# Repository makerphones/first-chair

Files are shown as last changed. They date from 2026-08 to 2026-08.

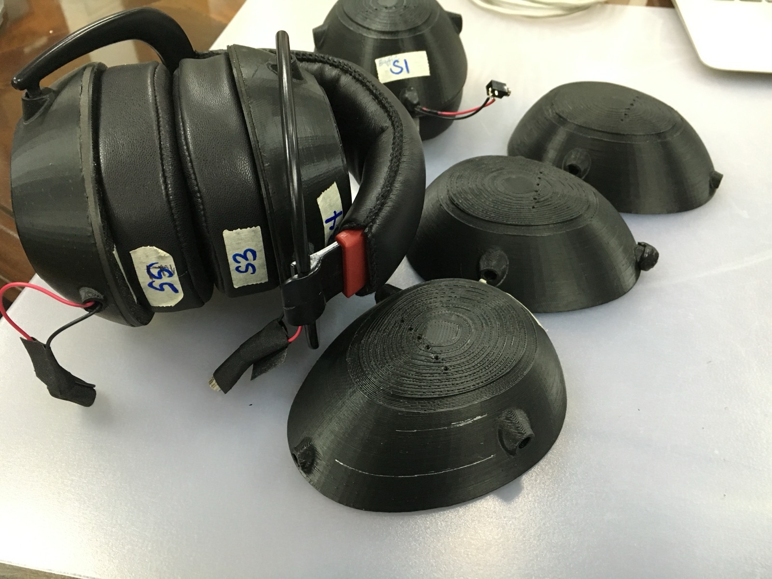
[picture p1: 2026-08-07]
design/form/reference/dev-6398.jpg

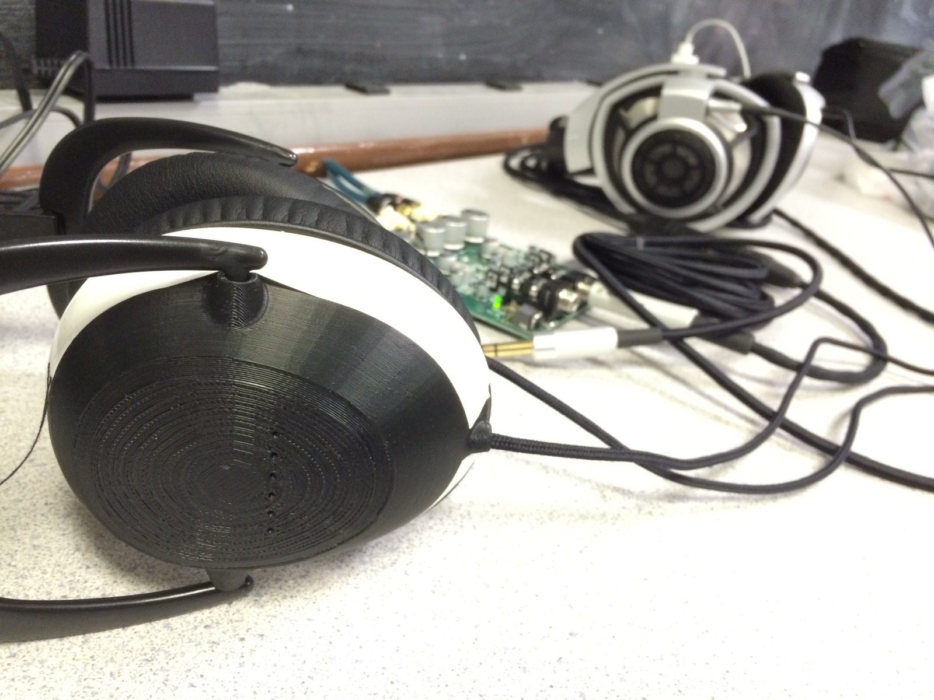
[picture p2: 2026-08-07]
design/form/reference/dev-6343.jpg

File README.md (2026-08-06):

# First Chair

An open-source **40 mm open-back headphone** you can build yourself, modify, and
make your own. Parametric CAD — change a driver, a pad, or a head size and the
model follows. A project of [MakerPhones](https://makerphones.com) / Warren Labs.

> **🧊 Spin it in 3D** — inspect the assembly in your browser before you build:
> **[live 3D preview →](https://makerphones.github.io/first-chair/)**

> **Status: early / in active development.** The cup and baffle are first-pass
> geometry; the headband parts (yoke, slider) are stubs. Nothing has been
> print-verified yet. Follow along — and fork freely.

Honest sonic target: a bright, open, detailed open-back — strong mids and
treble, modest bass. That's the nature of a small driver in an open baffle, and
the design leans into it rather than chasing bass the hardware can't make.

## How it's made

The parts are defined in code with [CadQuery](https://cadquery.readthedocs.io)
(Python). That means the whole design is plain text you can read, diff, and
modify — and it exports both **STL** (ready to print) and **STEP** (to edit in
other CAD).

### Build the parts

```bash
python -m venv .venv && source .venv/bin/activate
pip install -r requirements.txt
python build.py                 # all parts → output/
python build.py baffle          # just one
```

STLs and STEPs land in `output/`.

For the live VS Code [OCP CAD Viewer](https://github.com/bernhard-42/vscode-ocp-cad-viewer)
(`python show.py`), also install the viewer-only deps and point VS Code's Python
interpreter at this `.venv`:

```bash
pip install -r requirements-dev.txt
```

### Modify it

Open `params.py` — every dimension lives there with a comment. Common changes:

- **Different driver?** Measure it with calipers, update `driver_od` and
  `driver_aperture`, rebuild the baffle.
- **Different pad?** Adjust `pad_lip_od` to your pad's inner-ring diameter.
- **Bigger/smaller head?** Adjust the cup and headband parameters.

The build log in [`docs/DESIGN-LOG.md`](docs/DESIGN-LOG.md) explains the
reasoning behind the design and tracks the open questions. The full functional
spec is in [`docs/design-spec.md`](docs/design-spec.md).

## Bill of materials (build-it-yourself)

| Component | Source | Est. cost |
|---|---|---|
| 2× 40 mm driver, 32 Ω | Parts Express / Madisound | $8–18 |
| 1× Dekoni Universal 100 mm pads (Beyer-type) | Dekoni Audio | $30–45 |
| 1× spring steel arc (laser-cut, formed) | SendCutSend + form | $8–15 |
| 8× M3 heat-set inserts | hardware / online | $1 |
| 8× M3×8 mm button-head screws | hardware / online | $1 |
| Foam gasket tape | hardware | $1 |
| Damping pack (foam + felt + fiberfill) | Parts Express | $3–5 |
| Cable + Y-split + 3.5 mm TRS plug | online | $8–15 |
| Printed parts | own printer or print service | $3–25 |
| **Approx. total** | | **~$55–105** |

No printer? FDM print services (JLCPCB, Xometry) will print the set cheaply.

## License

**This project is open source under the [MIT License](LICENSE).** You are free
to use, modify, build, and **sell** the First Chair — commercially or
otherwise. No "personal use only" restriction, no fee. One license over the
whole repo, code and docs alike; full text in [`LICENSE`](LICENSE).

**Attribution requested:** when you share or build on it, credit *makerphones by
Warren Labs (makerphones.com)*.

The **makerphones** and **Warren Labs** names and brands are *not* covered by
the license and are protected separately by trademark — it covers the design
and code, not the names.

## Contributing

This is a learning-in-public project. Builds, measurements, and fixes are
welcome — open an issue with what you tried and what happened.

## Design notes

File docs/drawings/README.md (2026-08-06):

# Daily Driver — drawings

Schematic 2D part sheets (SVG) for the Daily Driver, in the DT880-family
direction (see `../design-spec.md`). These are **Resolve-phase schematics** — not
CAD projections. They capture intent, key joints, and first-pass dimensions so
the spec and the eventual `parts/*.py` geometry agree on what each part *is*.

| Sheet | Part | Referenced from spec section |
|---|---|---|
| `assembly.svg` | Exploded stack + the 3 joints | System architecture / BOM |
| `cup.svg` | Cup shell + integral grille | Cup shell |
| `baffle.svg` | Front-mount baffle | Baffle plate |
| `yoke.svg` | DT880-style fork-yoke | Fork-yoke |
| `slider.svg` | Bow slider (height + swivel)| Slider |
| `bow.svg` | Spring-steel head bow | Headband / bow |

**Every dimension on these sheets is a first-pass starting value pending measured
parts** — the bow especially is TBD from the real Beyer Metal Head Bow. Sheets
are schematic, dimensions are not to scale.

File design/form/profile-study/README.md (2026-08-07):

# Cup profile study

Six directions, generated by `design/form/profiles.py`, rendered from one camera so the
silhouettes compare honestly. **Silhouette only** — no grille, no bosses, no lip chamfer.
This answers *what shape is it*, not *what parts is it*.

Held fixed, because the commodity Grado pad sets them from outside:
**Ø54 rim · 3.0 lip · Ø48 body · 3.0 wall.** Depth and the whole rear form are free.

| | depth | PETG | note |
|---|---|---|---|
| `cylinder` | 27.6 | ~13.1 g | the baseline. Austere, and the wall you print is the wall you specified |
| `cone` | 27.6 | ~18.5 g | prints nose-down self-supporting; mass falls away from the ear |
| `waist` | 27.6 | ~12.5 g | the move in the 2016 shape sketches, read in section |
| `stepped` | 25.0 | ~9.2 g | concentric plates — every diameter change is a future parting line |
| `shallow` | 21.6 | ~11.0 g | Old Faithful's earcup measured 21.6 deep; this is that read |
| `bell` | 26.0 | ~7.6 g | one continuous curve from the lip to a small back face |

Mass assumes PETG 1.27 g/cm³ at ~55 % effective solid (30 % gyroid + perimeters).

## Working with it

```bash
.venv/bin/python design/form/profiles.py            # all six
.venv/bin/python design/form/profiles.py cone waist # just these
```

Add or change a direction by editing `PROFILES` — each is a list of `(radius, depth)`
points running outward from the axis at the rim, around the outside, back to the axis.

**No handoff.** These are real CadQuery solids in the repo's own toolchain, so a chosen
profile goes straight into `parts/cup.py` as the lathe profile it already is.

## Known limitation

`cone` falls back to a straight Ø26.3 bore — OCC refuses the profiled inner loft on that
one ("Courbes non jointives"), so its wall is thicker than 3.0 at the back and its mass
is overstated. The silhouette is correct; the number isn't. Same class of OCC fragility
recorded in `docs/cadquery-build-notes.md`.

---

# Split study — where does the part break?

`design/form/splits.py`. Two cases, assembled and exploded, in `_contact-splits.png`.

**The architecture being tested:**

| | |
|---|---|
| **FRONT** | pad rim + baffle + driver seat, **one printed part**. The driver is registered concentric to the pad by *geometry* rather than by assembly — no bolt circle, no four insert positions to align. |
| **REAR** | the acoustic variable: open area, volume, damping. The part a builder iterates and swaps — which makes open-vs-closed a **part**, not a parameter. We already learned that lesson the expensive way. |
| **DRIVER** | loads from the rear, seats against the back of the front piece. |

Both halves print open-side-down, no supports. That is *why* the split goes here.

| case | split | front | rear |
|---|---|---|---|
| `shallow` | 11.0 of 21.6 | 4.3 g | 6.7 g |
| `waist_split` | 15.5 of 27.0 — **at the pinch** | 9.0 g | 7.3 g |

`waist_split` is a *true* waist. The original `waist` only swells then tapers; this one
pinches to Ø42.8 at d=15.5 and flares again behind it, so **the parting line has somewhere
to hide.** A seam at the narrowest point reads as intent; the same seam on a straight wall
reads as a seam.

## On joining the two

- **Screw thread** — no fasteners, serviceable. But a thread **cannot control where it
  stops**, so anything directional on the rear cup (mark, cable exit, an oriented grille)
  lands at a random angle. Only viable if the rear is rotationally indifferent.
- **Bayonet, quarter-turn** — no fasteners *and* a defined angular stop. Strongest option.
- **Screws** — positive and serviceable, but reintroduces bosses, inserts and hardware, and
  works against the *"only parts not printed are ___"* sentence.
- **Glue** — kills serviceability. Against the standing tie-breaker: the user is a tweaker.

---

# Straight front + tapering back

Maker on `waist_split`: *"it looks like a yoyo."* Correct, and not a rendering error — that
profile swells, pinches, then **flares back out**. Wide-narrow-wide is a yoyo.

The read was *"the base of the one on the left, with the back of the other one but flipped"*:
straight front, then mass falling **away** from the head instead of bulging back out.
`_contact-taper.png`, three rates:

| | straight to | back face | depth | PETG |
|---|---|---|---|---|
| `taper_soft` | 13.0 | Ø35 | 25.0 | 10.3 g |
| `taper_mid` | 12.0 | Ø29 | 24.0 | 9.1 g |
| `taper_hard` | 11.0 | Ø22 | 22.5 | 7.8 g |

The straight section is also the split zone — which is the point. Parting on a cylinder
means both mating faces are the same diameter, so the joint is a simple round fit rather
than something that has to follow a curve.

## The parting line: shadow gap, not chamfer

A chamfer at the joint is a bad print — on whichever part has it facing down it is a
first-layer overhang. A **shadow gap** is a pure diameter step: the rear cup steps down
0.6–1.2 mm for ~2 mm above the joint. Zero overhang on both parts, prints trivially, and it
does three jobs at once:

1. reads as intentional rather than as a seam
2. **hides tolerance mismatch** — a flush joint shows every 0.1 mm of print variation, a
   recessed one shows none
3. gives a fingernail purchase for opening it

0.6 mm is a line. 1.2 mm is a feature. Both print; the choice is taste.

## On the bayonet — quarter turn is probably enough, and here is the alternative

A bayonet's retention is the **lug ramp and detent**, not the rotation angle. Three lugs at
120° need only ~60–90° to engage, and load is shared three ways.

If it still feels insufficient, the better answer is a **3-start coarse thread**: ~120° of
rotation, more screw-like in the hand, and it still solves the orientation problem — it
lands in one of **three** defined angular positions rather than anywhere at all. That is the
real objection to a single-start thread, which stops wherever friction says.

---

# Section — does the front piece hold the driver?

`design/form/section.py` → `_section.png`. **Yes, comfortably, for a dynamic.**

```
ear ──5.5── cup face ──3.5── driver flange ──5.0── driver back ──3.5/4.5── split
            (worn pad)        (dome+excursion 2.0 forward of the flange)
```

| | split | front cavity | behind the driver |
|---|---|---|---|
| `taper_soft` | 13.0 | 7.0 mm | **4.5 mm** |
| `taper_mid` | 12.0 | 7.0 mm | **3.5 mm** |

**Front cavity 7.0 mm** — the gap from the excursing dome to the ear. That is the number
that sets tonality, and it is mostly the pad: change flats for bowls and it moves several mm.

The driver flange sits **3.5 mm** back from the cup face. That is a *design* choice, not a
constraint — pushing it back trades front cavity for tail room 1:1.

## Where the planar breaks it

Maker: *planars are thicker, with a nipple on the front, so they need more space and a
different mounting ring.* That is exactly what the budget shows.

A dynamic spends **2.0 mm forward** of the flange and **5.0 mm behind**. Push either and the
front piece has to grow, because the split can only move back so far before the rear cup
stops being the acoustic part:

```
front piece depth needed ≈ DRV_SEAT + basket + 3 mm of mounting structure
```

At a plausible planar — say 9 mm body with a 3 mm front nipple — the seat has to move back
to 4.5+ and the basket needs 9, so the split lands near **17 mm**. The current 12–13 does not
hold it.

**Those planar numbers are invented.** What is needed is one caliper session on a real
planar: body depth, front protrusion, flange OD, mounting hole pattern. Then this drawing
answers it properly instead of plausibly. Adjust `DRV_*` at the top of `section.py` and re-run.

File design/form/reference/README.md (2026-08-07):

# Reference — prior work, for the form pass

**These are the maker's own prior professional headphone designs**, from the HeadRoom Cosmic
programme (planar-magnetic over-ear, taken to production prototype and independently measured
by InnerFidelity) and the shape studies that preceded it. They are here so a design session can
be seeded from *what was actually built* instead of from adjectives describing it.

Captions matter as much as the pixels — read them.

## The shape studies

| File | What it is |
|---|---|
| `shape-sketches-overview.jpg` | **Six cup-outline studies in one row.** Teardrop, oval, rounded-square, faceted, egg, round. Note what does *not* change between them: the waisted, flared yoke stem and how it lands on the cup. That constant is the family language; the outline was the variable. |
| `shape-sketch-1a … 6a.jpg` | The same six, individually. |

`shape-sketches-overview.jpg` is the single most useful image here. It is a decade-old answer to
the question the current pass is asking — and it shows the answer was never one outline.

## The headband blanks

`bow-blanks-cut-and-formed.jpg` — laser-cut blue-tempered spring steel. Flat blanks at left,
formed arcs at right.

Read the cut: a tapered strip that **splits into a Y-fork** toward the ear end, with the slots
**terminated in teardrops** so a cut cannot start a crack, and a mounting hole at each tip.
Material follows the bending moment — wide where the load is, split and slender where it is not.
This is "shape the silhouette, don't thin the slab," executed in steel years before it was
written down as a rule.

**What worked and what didn't:** the *cutting* is resolved. The *forming* failed — the arc came
out wrong and the spring rate too low, using printed forming jigs. That is why the current build
buys a bow. It is also why "make our own" is a sourcing conversation with a spring house rather
than a design problem: the part is already drawn.

## Prototypes

| File | What it is |
|---|---|
| `prototype-1.jpg` | Prototype 1 (left) benchmarked against an Audeze LCD, a MrSpeakers/Dan Clark, and a Fostex. Useful for scale and for the company it was designed to keep. |
| `driver-70mm-planar.jpg` | The 70 mm planar diaphragm — spiral conductor trace, with a polygon of tape strips laid across it. That tape is **damping applied by placement**, the same lever as acoustic paper on a baffle. |
| `dev-*.jpg` | Development photographs: printed cup and baffle series, pad trials, assembly. |
| `earcup-07revB.stl` | An actual printed earcup from the programme. Measures **80.00 × 100.06 × 21.59 mm** — matching the design letter's "fits in about 100 mm x 80 mm." Oval, not round. |

## The intent, written at the time

From the design letter to the industrial designer on that product:

> "The code name Old Faithful is chosen to represent something that lasts a lifetime and will be
> passed down for generations. It should exude quality craftsmanship, **almost looking handmade
> but with extreme precision**. Parts should be easily replaceable and durable. Reduce weight
> where ever possible."

## The rules, taken from corrections given to that designer

1. **If a mechanism isn't needed, delete it.** A fold hinge was killed with *"an extra weakness
   we do not need."* Not "unnecessary" — a **weakness**.
2. **No ornament.** On a decorative step added where the pad met the cup: *"I am assuming this is
   for aesthetic reasons? I do not have to have this."*
3. **Simplify until it's simple, then stop before it's ugly.** *"There seems to be too much going
   on with the headband mechanism right now, we'd like to simplify"* — and *"we're looking to
   simplify without looking ugly. Hopefully we can find a nice middle ground."* Both halves.
4. **Material follows load.** On a yoke: *"if we don't need the extra metal we can save weight —
   but it does look nice and beefy."*
5. **The prototype settles arguments, not the drawing.** Hinge pins moved 8 mm because a built
   part said so.

## Provenance

Everything in this folder is the maker's own photography of his own prototypes, his own shape
sketches, and his own printed part.

**Deliberately excluded:** commissioned industrial-design renders and CAD from Deep Blue Design
and Martin Ortiz (ownership likely but unconfirmed), third-party product photography from the
original mood-board collection, and anything touched by a supplier NDA. This repo is public and
MIT-licensed; none of that can live here.

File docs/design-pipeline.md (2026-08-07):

# AI-Assisted Design Pipeline

**v0.3 · 2026-08-06 · Claude Design replaces the FAL image pipeline**

This describes how AI assists the design of a MakerPhones build and, just as importantly,
**where it stops**. The pipeline produces *form* and *figures*. It never produces engineered
CAD. The headphone you can actually build is authored by hand in CadQuery, from human
decisions.

This file is not First-Chair-specific. First Chair is the fork template for every build
after it (`starting-a-new-product.md`), so what is written here is the standing process.

**Capability map: `warren-labs/docs/claude-design.md`** (internal — deliberately not linked,
since this repo is public and that one is not). That file is the source of truth for what the
tool can and cannot do — verified by direct probe on 2026-08-06, not from marketing copy —
and it applies line-wide, beyond MakerPhones. It is not restated here; the one conclusion
that changes how you work is repeated below, and nothing else.

What follows is the MakerPhones-specific part: where it sits in *this* process, what we hand
it, what we demand back, and what we do with the result.

---

## The one thing to internalise

**It has no boolean operations.** No CSG means a hole in an arbitrary place on a curved wall
is impossible, which means **nothing printable can originate there** — and that settles the
handoff with no per-part judgement. Form and figures upstream, engineering in CadQuery. It
described its own output as *"industrial-design intent, not a print-ready CAD part"*, which
is the same boundary we draw from the other side. Both parties agreeing on that unprompted
is the reason it is safe to adopt.

The corollary is the useful part: **it is valuable at the two ENDS of a project and useless
in the middle.** Before CAD exists, nothing is lost to a tool that can't do booleans, because
there is no engineering yet. After CAD exists, it is the best documentation-figure tool we
have. While CAD exists, it can only get in the way.

---

## Workflow: Diverge → Resolve → Engineer

Three phases, each with its own surface and its own job. The discipline is not doing one
phase's work on another's surface.

```
DIVERGE                          RESOLVE                          ENGINEER
find the form + family           develop it into a buildable      author the geometry
Claude Design (3D)               design — chat + SVG sketches     Claude Code + CadQuery
named, scaled GLB                parts, fit, fasteners,           params.py + parts/*.py
       │                         acoustics, wall, weight          build · gate · log · commit
       │                                  │                                │
  GLB + part list ────────────> resolved design intent ──CC prompt──> verified parts
       └──────── inspect_glb.py, then read into chat ────┘

                                                    ┌─────────────────────────────┐
DOCUMENT (after Engineer)                           │ CadQuery/OCP renders ───────┼──> Claude Design
compose, annotate, typeset the figures              │ (our geometry, our fidelity)│    composes the plate
                                                    └─────────────────────────────┘
```

### 1 · DIVERGE — find the form, before any CAD exists

Run the family/form pass in Claude Design, seeded with the repo and the naming schema (see
Conventions). Ask for **the rules in words before it models anything** — proportion and rule,
not a repeated detail; something that still works at 54 mm and at 91 mm. Then let it model.

**FORM BEFORE PARTS. This order is not optional and we got it backwards first time.**

```
1. one continuous form, no parts at all      ← judge it as an OBJECT
2. split that form into parts                ← serviceability + printability enter here
3. details: grille, mark, fasteners, joints
4. ENGINEER — re-author by hand in CadQuery
```

Asking for parts in step 1 produces exactly what it sounds like: primitives butted together,
every junction an abutment, nothing flowing into anything. That reads as clunky no matter how
good the proportions are, and no amount of "make it more elegant" fixes it, because the
*construction method* is the problem.

**It also plays to the tool.** No booleans means it cannot cut features into a body — so
assembling primitives is the only way it can fake parts, and it is its weakest mode. A single
lofted or swept body is its strongest. Ask for the thing it is good at.

And the payoff at step 2: **if the form is defined as a profile, splitting it into parts is a
split of the profile, not a boolean.** The whole path stays inside the tool's ceiling instead
of hitting it one step later.

This is also how the maker's own prior product was done — the industrial-design firm delivered
*surfacing* (one form), and the part split came afterwards, from the maker, once the shape was
agreed.

Output: **a named, hierarchical, correctly-scaled GLB** — not a picture. That is the whole
reason this replaced what came before. Run `makerphones/scripts/inspect_glb.py` on it (it is
in the parent repo, not this one), read the part list, and
carry the numbers into the discussion.

**Two things to push back on, every time.** It will try to make a "family" by repeating a
detail — that is the weak version. And it drifts toward glossy injection-moulded consumer
product, because that is what the training data is full of; anything printed, machined or
hand-built has to be asked for explicitly and defended on the second pass.

### 2 · RESOLVE — develop the chosen direction into a buildable design

With the direction picked, work the design conversationally in chat: the parts, how they fit
and fasten, then the engineering-taste calls — connector choice, acoustic treatment, wall
thickness, weight, and the design language carried across parts. Claude sketches schematic 2D
concepts (SVG) and reasons through structure, constraints, acoustics and printability.

**This is where the acoustic and mechanical decisions are made, not just the visual ones** —
chat is the only one of the three surfaces that can *reason*, so the judgment calls live here.
Output: a resolved design intent, ready to engineer.

### 3 · ENGINEER — author the geometry

In Claude Code: author the parametric CadQuery geometry (`params.py` + `parts/*.py`), then
build, gate, log, commit. The CC loop is for engineering and verification — **not** for
iterating taste one tweak at a time; that belongs in Resolve.

### 4 · DOCUMENT — the strongest mode, and the workflow it proposed itself

**Do not have it re-model geometry at lower fidelity to draw a picture of something we
already hold as real CAD.** Export views from CadQuery/OCP, hand it the renders, and let it
compose, annotate, sequence and typeset: exploded assemblies, print-orientation plates with
overhang callouts, numbered step figures, hardware tables. For schematic figures that need no
dimensional truth (exploded order, orientation, fastener callouts) it can build them directly.

For a documentation-led product this is plausibly worth more than anything it does for the
CAD, since the CAD is already solved and illustration is a cost you pay forever.

---

## Conventions — set these in every prompt

**Two of these fail silently. That is why they are a checklist and not advice.**

- **Author at 1 unit = 1 mm.** Matches CadQuery and every slicer. glTF's spec convention is
  **metres**, so a model that does not say otherwise imports at **1/1000 scale** into a
  slicer — a 54 mm cup arrives as a 0.054 mm speck, or a correctly-authored-in-metres file
  arrives 1000× too big. Nothing errors. `makerphones/scripts/inspect_glb.py` warns on **both** failure
  directions; run it on anything that arrives, without exception.
- **GLB only, never OBJ.** OBJ has no scene graph — it carries groups, not parent/child nodes
  — so it *structurally cannot* express the `SUBASSEMBLIES` hierarchy that makes the output
  worth having. An OBJ silently degrades the one property we are asking for.
- **Impose the mesh-naming schema.** Give it `assembly.py`'s `SUBASSEMBLIES` contract up
  front. It conforms exactly — verified against a test part whose names (`cup_R`,
  `cup_shell_R`, `boss_m3_1..4_R`) landed against the contract unchanged. When the names
  match, ingest is nearly free; when they don't, someone hand-maps 69 meshes.
- **Seed it, and record the seed.** A project can be seeded from a design system, uploaded
  files, or a GitHub repo. **The reproducible unit is (skill + seed + prompt), not the prompt
  alone** — record all three or the result cannot be reproduced later. A prompt kept without
  its skill and its seed is not a record of anything.
- **Write the prompt self-contained. It cannot see this repo.** Claude Design has no
  filesystem access, so "read `docs/industrial-design-brief.md`" silently yields a session
  working from its own priors — the exact failure the pass exists to fix. State every
  constraint inline and reference no local path. Seeding from the public GitHub repo does give
  it real access, but keep the prompt self-contained anyway: "go and read X" is a weaker
  instruction than stating X, and it fails quietly when the seed doesn't take.

The `claude-design` MCP has **no verb for the 3D agent** — that capability is driven by
chatting in Claude Design itself, so the loop is: prompt there, download the GLB, ingest here.
What the MCP usefully adds is **seeding**: writing our conventions and parameter table into a
project so the session starts inside our constraints instead of inventing its own.

---

## Taste vs. convention — the split that decides what AI touches

This boundary predates Claude Design and survives it unchanged. It is worth being explicit
about why: **Claude Design produces taste, never convention.** It is a form tool. It cannot
author a screw boss you would reuse, and it should never be asked to.

**TASTE is human and manual.** Cup depth, grille form, where the screws go, proportions,
stance, finish. These are judgment calls, decided from references **plus real measurements**
(that deciding is **Resolve**; **Engineer** only encodes the result). Taste is encoded two
ways, both authored by you, in code: some taste is a **number** (cup depth → a value in
`params.py`), and some is **form** (grille pattern, cup profile) authored as parametric
**geometry in `parts/*.py`** and driven by those params. AI may *inform* taste by showing
options; it never *sets* it, never writes a dimension, and never authors a part.

**ESTABLISHED MECHANICAL CONVENTIONS are not reinvented.** A screw boss, a fillet, a standard
thread, a snap fit — solved by decades of practice. They live as **reusable parametric
helpers**, authored once from convention in `parts/features.py`, and **reused** across parts.
Convention is a library, not a creative act.

| | Who/what | Where it lives |
|---|---|---|
| **Taste** | Human decision, informed by form refs + measurement | `params.py` (numbers) + `parts/*.py` (form) |
| **Convention** | Standard practice, authored once | `parts/features.py` (reusable helpers) |
| **Form + family** | Claude Design (3D) | `design/form/<date>/` — GLB + the prompt record |
| **Engineered parts** | Human + CadQuery | `parts/*.py` |
| **Documentation figures** | Claude Design, over **our** renders | `docs/figures/` |

There is a second reason the boundary holds, beyond "no CSG": **engineered features are
decisions, not pixels.** Where the screws go, how deep the cup is, how the baffle seats, the
vent open area — these have consequences for fit, acoustics and print success. They are
reasoned and measured, not inferred from a form study, and no form study knows your driver's
caliper measurements or your printer's tolerance.

---

## Layout

```
docs/industrial-design-brief.md   the form brief that seeds the Diverge pass
docs/design-pipeline.md           this file
design/
  form/<date>/                    Claude Design GLB + the (skill + seed + prompt) record
  figures/                        source renders handed out for documentation plates
scripts/inspect_glb.py            (in the makerphones repo) scale + naming + hierarchy check
parts/features.py                 reusable mechanical primitives (convention)
```

Curated keepers are committed; the exploration history is part of an open design's story.
Record the seed alongside the GLB — a GLB with no `(skill + seed + prompt)` note beside it is
an orphan nobody can regenerate.

---

## What this replaced, and why the old pipeline is gone

The **FAL image pipeline** — Stage 1 text→concept image, Stage 2 image→reference mesh — was
removed from this repo on 2026-08-06 along with `pipeline/` (`config.py`, `gen_concepts.py`,
`gen_reference_mesh.py`, `smoke_test.py`) and the FAL client dependency.

It was a two-stage lossy path whose output was images we did not want to build, and it was
abandoned rather than finished. Claude Design does both stages in one and returns **named,
hierarchical, correctly-scaled geometry instead of a picture**. That is not an incremental
improvement: an image has to be re-interpreted by a human before it can become parameters,
and a named part list reads straight into `params.py`.

**Deleted rather than kept as a documented fallback — that is a decision, recorded here so it
is not mistaken for neglect.** The argument for keeping it was that a fallback costs nothing
to leave in place. It doesn't cost nothing: an abandoned two-stage path sitting in `pipeline/`
with working code, a config file and a smoke test reads as *current* to the next person who
opens the repo, and the fork template propagates it into every future build. A trap that
regenerates itself with each fork is worse than a paragraph of history. The code is in git
history and in the Daily Driver repo if it is ever genuinely wanted.

*(Daily Driver still carries the FAL pipeline and its v0.2 version of this document. It is
paused, not deleted, and reconciling it is deliberately out of scope here.)*

---

*v0.3 · 2026-08-06 · Rewritten around Claude Design; FAL pipeline and `pipeline/` deleted;
conventions promoted to a checklist because two of them fail silently.
v0.2 · 2026-06-14 · Added the Diverge → Resolve → Engineer workflow (Resolve was the missing
layer). v0.1 · 2026-06-13 · Written as the form pass opened.*

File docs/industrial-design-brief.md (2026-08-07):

# First Chair — Industrial Design Brief

**v0.2 · 2026-08-06 · rewritten for the supra-aural, and re-opened**

> **This brief was wrong, and the CAD faithfully built the wrong thing.**
>
> v0.1 was Daily Driver's brief with the product name changed. It specified an
> *"open-back, **over-ear (circumaural)** DIY headphone"*, recorded the resolved direction as
> **"DT880-family, around-ear"**, and named a **Dekoni Universal 100 mm** pad. The fork reset
> about eight dimensions in `params.py` and left this file — the thing the geometry is supposed
> to descend from — untouched.
>
> So the model on the website was a **shrunken DT880**: domed cup, circumaural stance,
> over-ear pads on a Ø54 rim. Dimensionally correct, formally the wrong product. Same failure
> as the Ø91 radii in `params.py` and the DT 770 pads in `BOM.md`, one level further upstream.
>
> The rule that would have caught it is `starting-a-new-product.md` step 1b — run the form pass
> in Claude Design **before** writing `params.py`. This build predates that rule.

**Status: the form is OPEN. This brief states the constraints; it deliberately does not state
the answer.** The Diverge pass (`design-pipeline.md`) produces 3–5 directions and the maker
picks one. Do not read a direction into this file that isn't here.

---

## What it is

An open-back **supra-aural (on-ear)** headphone around a 40 mm driver. 3D-printed, fully
parametric, open source (MIT), meant to be downloaded, forked and modified. It is the
**flagship first build** — the first rung of a learning path, not the last.

Sonic character is bright, open, detailed, with modest bass — the honest nature of a small
driver in an open baffle on an on-ear. The form should feel like that: light, airy, unfussy.

## Who it's for, and how it should read

DIY makers and hobbyist builders. The form should read as **honest engineering — pro-audio
sensibility through a maker lens** — not glossy consumer product. Credibility comes from
looking considered, functional and serviceable, not flashy. If it looks like it was designed by
someone who knows audio and respects the person building it, it's working.

**This one needs defending on every pass.** Generative tools drift hard toward glossy
injection-moulded consumer product, because that is what the training data is full of.
Printed, machined and hand-built has to be asked for explicitly and re-asserted on the second
pass — see `design-pipeline.md`.

---

## LOCKED — the form pass works inside these

These are decided. A direction that breaks one of them is out, however good it looks.

**Architecture — supra-aural, and it must read as one.**
The failure to design away from is a scaled-down over-ear. A supra-aural sits *on* the ear:
small cup, small pad, light band, close to the head. It is a different object, not a small
version of another object.

**Dimensions** (see `params.py`; these regenerate everything):

```
front plate / pad rim   Ø 54.0        the pad-mount interoperability dimension
cup body                Ø 48.0        what the pad grips, behind the lip
interior                Ø 42.0        → 3.0 mm wall
overall depth              27.6
driver                     40 mm
```

**Parts** — sprung steel bow (bought, screwed at its end tabs) → printed slider → printed yoke
→ printed cup + separate baffle + clamp ring. **Three degrees of freedom**: swivel and tilt at
the cup, plus slider travel.

**Pads are commodity Grado-pattern.** We design a rim the foam stretches over and ship no pad.
This is the one interface where we deliberately do not innovate — diverging costs the builder
the whole aftermarket. Retention is the **step**: axial on the Ø54 lip, friction on the Ø48
body behind it.

**Prefer the smaller pad.** Not taste — our own 2026-08-03 placement data has the small-padded
SR60x ~2.5× more repeatable through 2–8 kHz than the larger-padded RS1x. Repeatability is what
this design competes on.

**Spring steel, not printed springs.** No FDM plastic is a good spring; a printed band is loose
by month three.

**Serviceability beats manufacturability.** The standing tie-breaker: the user is a tweaker.

---

## DECIDED 2026-08-06 — the cup outline rule, and why First Chair is round

Round was never chosen. It was inherited from the Daily Driver, which took it from a round
Grado reference. The maker's own prior products — the HeadRoom Cosmic and Old Faithful — were
**oval / teardrop**, and the archived earcup STL measures 100 × 80 × 21.6, matching the design
letter's "fits in about 100 mm x 80 mm."

**The rule is not a shape. It is: the cup outline follows the ear coverage the product needs.**

- **Circumaural** cups enclose the pinna, and a pinna is a teardrop. A round over-ear either
  pinches the ear or wastes cup volume avoiding it. Daily Driver, Session and Encore should be
  **teardrop / oval**.
- **Supra-aural** sits *on* the ear rather than enclosing it, so it has no outline to follow.
  **First Chair is round** — now decided rather than assumed, and overdetermined: the commodity
  Grado-pattern pad is round, and that interface is LOCKED.

*Maker's framing: "We don't have to be so rigid in our approach, we want to design with intent
for the right application."* The family is held together by the rule and the detail language,
not by a repeated outline — a repeated outline across products with different jobs is the weak
kind of family, the same failure as a repeated yoke.

**Correcting the assumption that produced the original choice:** round is easier to *turn and
mould*. It is not easier to *print* — FDM does not care whether a cross-section is a circle or
an ellipse, and there is no rotational tooling anywhere in the process. Nor is it easier in
CadQuery: the cup is already a loft of stacked circles, and stacked ellipses cost nothing. So
"round because it is easier to manufacture" was a constraint inherited from a process we do not
use — the same failure mode as the Ø91 radii, one level further out.

Cost, stated: oval cups mean oval pads, so the over-ears lose the commodity pad aftermarket.
First Chair keeps it.

## OPEN — this is what the pass is for

The form language. Explicitly *not* pre-decided in this file.

**Grado is the architectural reference, not the styling target.** It is the right reference
for *what a supra-aural is* — small cup, rod-in-block gimbal, minimal band, flat rear face,
everything visible. It is the wrong thing to copy: cloning a Grado would be the least
interesting version of this project, and `design-spec.md` §5 already lists where we diverge on
purpose:

| Grado does | We should | Why |
|---|---|---|
| Barrel profile from wood turning | Whatever prints well | A barrel is a *lathe* form; inheriting it copies a manufacturing process we don't use |
| Separate Ø45 × 2 mm screen disc | Integral printed grille | One fewer part, one fewer thing to source |
| Register the driver behind a restricted aperture | Aperture as a free acoustic variable | The clamp ring means the aperture need not double as the register |
| Glued / pressed assembly | Clamp ring, serviceable | The tie-breaker above |

**Ask for the family rules in words before anything is modelled.** The weak version of a
"family" is a repeated detail. The strong version is proportion and rule — something that
still works at 54 mm here and at 91 mm on the Daily Driver, because these two have to look
like siblings.

Specific questions the pass should answer:

- **Cup profile.** The current convex dome is inherited DT880 and is now shallow and
  chamfer-like anyway (it is capped inside the 6 mm back band). Flat rear face? Stepped?
  Something that isn't either?
- **How the grille reads.** The triangular lattice with the logo riding on it is built and
  works, but it was proportioned for a Ø91 cup and rebuilt to fit rather than designed for
  this one. `grille_logo_zone_fraction` is the live knob.
- **The gimbal.** Ours is a fork-yoke inherited from an over-ear. Grado's rod-in-block gets a
  rotational axis for free; ours pushes both rotations out to designed joints and makes the
  yoke the crowded part.
- **The band and how the cup hangs off it.** We inherit a circumaural's arc from the Beyer bow,
  knowingly, until a bow is stocked to our own spec.
- **Stance and worn silhouette** — the thing that most says "on-ear" or doesn't.

---

## Deliverable

3–5 form directions, per `design-pipeline.md`. **GLB, 1 unit = 1 mm, named to the
`SUBASSEMBLIES` contract**, with the `(skill + seed + prompt)` record beside it in
`design/form/<date>/`. Run `makerphones/scripts/inspect_glb.py` on everything that arrives.

The prompt to paste into Claude Design is **`design/form/PROMPT.md`** — self-contained, because
**Claude Design cannot see this repo** and a prompt that says "read the brief" gets a session
working from its own priors instead. It duplicates the constraints above on purpose; when this
file changes, `PROMPT.md` changes with it. `design/form/SEED.md` is the how-to-run notes and
the `(skill + seed + prompt)` record.

Renders and meshes give **appearance, not manufacturable geometry**. Claude Design has no
boolean operations, so nothing printable can originate there: the chosen direction is
translated back into parametric CadQuery by hand.

---

*v0.2 · 2026-08-06 · Rewritten as supra-aural; the resolved-direction claim removed and the
form re-opened. v0.1 · 2026-06-14 · Daily Driver's brief, renamed — see the note at the top.*

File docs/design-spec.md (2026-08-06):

# First Chair — Open-Back Headphone

### Design Specification · v0.3 · 2026-06-14

**Status:** Design phase — direction locked, CAD catching up. This document is the functional
spec the CAD is built against, and the reference behind the build guide, the parts list, and the
measurements.

> **🧊 Spin it in 3D** — inspect the assembly in your browser before you build:
> **[live 3D preview →](https://makerphones.github.io/first-chair/)**

> **Every dimension below is a first-pass starting value pending measured parts.** Numbers are
> here so the geometry has something to build against, not because they're confirmed. They get
> replaced as real drivers, pads, and the bow are measured with calipers. Where a number depends
> on a part not yet in hand (the bow especially), it's marked **TBD from measured part**.

---

## Overview

The First Chair is the canonical first build: a 40 mm open-back headphone that's forgiving to
design and to assemble, buildable by a first-timer, and good enough to keep wearing once it's
done. It's fully parametric and built to be modified — change the driver, the pad, or the head
size and the model follows. A pre-sourced kit may be offered later; everything here is also
exactly what you need to build it yourself.

Honest sonic target: a **bright, open, detailed open-back** — strong mids and treble, modest
bass. That's the nature of a small driver in an open baffle, and the design leans into it
rather than chasing sub-bass the hardware can't make.

---

## Direction — DT880-family, around-ear

The form is locked to the **Beyerdynamic DT880 family**: a sprung-steel head **bow**, **sliders**
that ride it, and **fork-yokes** that straddle each cup. This is a deliberate choice between three
candidates the form pass explored:

- **DT880-family (chosen).** Spring-steel bow + fork-yoke + sliders. Around-ear, serviceable,
  honest pro-audio engineering — and the architecture decomposes cleanly into printed parts that
  bolt to a sourced steel bow. It reads exactly like what it is.
- **Grado-minimal (rejected).** On-ear, rod-block gimbals, exposed everything. Charming but small
  on the ear and fiddly to make comfortable; not the around-ear fit we want.
- **DCA thin-metal (rejected).** Dan Clark-style folded thin-metal baffle/arc. Beautiful, but it
  only makes sense in metal fabrication, not FDM — it would be faking a process we don't have.

Everything downstream — the fork-yoke, the screw-pin pivot, the slider that reuses a real Beyer
bow — follows from picking the DT880 family.

---

## System architecture

Seven parts per side, printed or sourced, each interface independently iterable. Top of the head
down to the ear:

```
SPRING-STEEL BOW         (bought: Beyerdynamic Metal Head Bow  |  or DIY 1095 to same geometry)
        │  ← slider rides the bow
SLIDER  × 2              (printed) — height adjust + swivel; clamps the bow
        │  ← fork-yoke carried by the slider
FORK-YOKE × 2            (printed) — DT880-style fork straddling the cup; ±20° tilt
        │  ← screw-pin pivot into the cup
CUP × 2                  (printed) — shell + integral rear grille; perimeter-wall screw bosses; earpad lip on the outer rim
        │  ← baffle front-mounts into the cup
BAFFLE × 2               (printed) — front-mount driver-mount plate; integral driver guard
        │
DRIVER × 2               (bought) — ~40 mm dynamic, damped, with rear air space
        │
PAD × 2                  (bought) — Dekoni Universal 100 mm (Beyer-type); slips over the cup-rim lip
```

Keeping each interface separate means any one part can be reprinted and iterated without touching
the others. The three real joints are detailed under **Interfaces** below.

→ See **[drawings/assembly.svg](drawings/assembly.svg)** for the exploded stack with the three
joints called out.

---

## Parts table

| Part | Printed / bought | Key dims (first-pass) | Status |
|---|---|---|---|
| Head bow | **Bought** (Beyer Metal Head Bow) or DIY 1095 | width ~10 mm; arc + length **TBD from measured part** | Sourcing target; geometry from real part |
| Slider ×2 | Printed | rides bow; height + swivel | Concept (CAD stub) — see [drawings/slider.svg](drawings/slider.svg) |
| Fork-yoke ×2 | Printed | straddles cup; ±20° tilt; M3 screw-pin | Concept (CAD stub) — see [drawings/yoke.svg](drawings/yoke.svg) |
| Cup ×2 | Printed | ID 78 · **depth 20** (DT880/770 ref; rear ~96 cc) · OD 90 (pad-driven) · wall 6; earpad lip on the rim | First-pass geometry; grille authored — see [drawings/cup.svg](drawings/cup.svg) |
| Baffle ×2 | Printed | OD ~77 · **stepped 6 (driver/guard hub) / 4 (outer ring)** · aperture ⌀35 · **open arc-slot vents + glued acoustic paper** | First-pass geometry — see [drawings/baffle.svg](drawings/baffle.svg) |
| Driver ×2 | Bought | ~40 mm dynamic, 32 Ω | Candidate: Peerless HPD-40N16 |
| Pad ×2 | Bought | Dekoni Universal 100 mm (Beyer-type); outer foam ⌀100, ear opening ⌀60 | Pad target locked |
| M3 heat-set inserts | Bought | M3 brass | Convention (`parts/features.py`) |
| M3 screws (rim + pivot) | Bought | M3 — rim: socket/button; pivot: shoulder screw | Convention |
| Damping pack | Bought | felt / foam / fiberfill | Tune by ear |

---

## Interfaces — the three joints

Three real joints hold the headphone together. Each is an independently iterable interface with a
resolved decision; exact dimensions are first-pass pending the mating parts.

### 1 · Cup ↔ Baffle — front-mount plate

The baffle (OD ~77) drops into the front of the cup (interior ID 78) and **front-mounts**: four
M3 screws pass through the baffle rim, **counterbored from the front**, into four heat-set inserts
in the cup's **perimeter-wall bosses**. The screw heads sit under the pad and are hidden once the
pad is on.

- **Decision:** front-mount, screws hidden under the pad; baffle is removable for driver swaps and
  tuning.
- **Not a hard seal.** The interface allows **controlled venting** plus a deliberate
  **damping-material spot** — the open-back wants some leakage here, not a gasketed seal.
- Supersedes v0.2's rear-ledge gasket-sealed baffle and its 70%-radius free-standing insert posts.

### 2 · Yoke ↔ Cup — screw-pin pivot

A DT880-style **fork-yoke straddles the cup**. Each fork arm pivots on a **screw-pin**: an M3
**shoulder screw** through the fork arm into a **heat-set insert** in the cup. Tilt is **±20°**.

- **Decision:** screw-pin pivot (shoulder screw + heat-set insert), one per side of the fork.
- Supersedes v0.2's "project's own 6 mm pivot post" interface — the pivot now lives at the
  yoke↔cup joint as a serviceable screw-pin, not a moulded post.

### 3 · Yoke ↔ Bow — slider

The **slider** clamps and **rides the bow** for height adjustment and provides the **swivel**
(cup rotation to meet the head); the fork-yoke is carried by the slider. Together: slider = height
+ swivel, fork-yoke = tilt.

- **Decision:** printed clamp on the bow; the bow is a **Beyerdynamic Metal Head Bow drop-in** (or
  DIY 1095 to the same geometry).
- **Open:** friction vs. detent on the height adjust is still undecided — with a real Beyer bow in
  hand there's the option to **reuse Beyer's metal wiper** rather than print the clamp spring.

---

## Acoustic approach (open-back)

- **Open rear.** The back of the cup is an integral open **grille**, not a sealed chamber — that's
  what makes the design forgiving and gives the open, airy character.
- **Front cavity = pad depth.** Driver-to-ear distance is set by pad thickness. Deeper is more
  comfortable and slightly warmer; shallower is more present and brighter. This is the main tuning
  lever, and it's why the pad choice is locked into the spec.
- **Light damping.** Acoustic felt / thin open-cell foam at the rear grille and a damping spot at
  the baffle interface tame cone breakup and reflections. Start light, tune by ear and measurement.
- **Rear air space.** The driver mounts with a deliberate rear air space behind it (cup depth),
  not pressed against the back.
- **No sealed volume to get right** — the reason an open-back is the right first build.
- **Expected response:** forward mids, extended/airy treble, gentle rolloff in the low bass.

---

## Design decisions

### Cup shell

→ **[drawings/cup.svg](drawings/cup.svg)**

- **Shell + integral grille** — the rear face *is* the grille, modelled into the cup (not a
  separate vented disc). Grille = a center **hub** + **2 concentric rings** + **8 radial spokes**,
  ~**40% open** area, every member **≥ 2 mm** for FDM printability.
- **Perimeter-wall screw bosses** — the four M3 heat-set bosses for the baffle are **blended into
  the perimeter wall**, *not* free-standing posts in the field of the back. Front-mount, and
  **clocked off the pivot axis** so they don't collide with the fork pivots.
- **Earpad retaining lip on the outer rim** — a raised ring at the cup's front **outer** edge
  (DT770-style); the earpad slips **over** it and its skirt wraps the lip. Retention lives on the
  structural cup, *not* the baffle. The lip OD = the cup OD, so it sizes with the cup.
- **Envelope** — interior **ID 78 mm × depth 30 mm**; **OD 90 mm** — a **pad-driven** outer
  diameter set to the earpad's cup-mount opening, so the cup's actual wall falls out at **6 mm**
  (`wall_thickness` 3 mm is now just the min-wall floor). The interior is unchanged at 78 mm —
  this is a pad/mounting change, not an acoustic one — so the ~143 cc internal volume holds
  (⌀78 × 30 mm ≈ π·39²·30 ≈ 143 cc; the old "~90 cc" was an arithmetic slip).
  Parameterized; **cup OD is now SET at 91.44 mm** (4 in overall − 2× pad lip), back-solved from the
  Beyer/Dekoni stretch-ring grip range — no caliper needed (see the build-readiness plan).
- **Symmetric** — identical left and right; L/R marked in the surface only.
- **Print orientation** — open face down / grille flat, no supports.
- **Material** — PLA+ for prototyping, PETG for durable/kit parts.

> **Engineering-pass note.** The current CAD still carries the June-14 grille where the outer ring
> sits on the old 70%-radius boss circle (bosses as ring nodes). This direction **moves the bosses
> out to the perimeter wall**, which decouples the grille's outer ring from the boss radius. The
> clean grille + wall-boss relocation + driver guard land together in the next engineering pass —
> this docs pass only records the target.

### Baffle plate

→ **[drawings/baffle.svg](drawings/baffle.svg)**

- **Front-mount plate**, OD **~77 mm**, **~4 mm** thick — drops into the cup front and screws from
  the front (see Interface 1).
- **Aperture ⌀35 mm with an integral printed driver guard** — thin spokes / grid printed across
  the aperture to protect the driver, in the same logo-evocative language as the rear grille.
- **No pad lip on the baffle** — the earpad retaining lip now lives on the **cup's outer rim**
  (DT770-style; see the Cup shell section); the baffle is a clean **driver-mount plate**. The
  front venting is now **open arc-slots** in the ring (between the 3 clamp-standoff sectors),
  **backed by a glued acoustic paper/mesh** in a shallow front depression — the paper sets the
  back→front resistance (open area large + parametric; paper grade measurement-gated).
- **Driver pocket ⌀42 mm on the back** — the driver frame seats into a pocket on the rear face;
  the aperture is the acoustic opening it fires through.
- **4 M3 rim screws**, counterbored from the front, into the cup's perimeter-wall bosses (see
  Interface 1). Heads hidden under the pad.
- **Open front venting + acoustic paper/mesh** (resistance-controlled), not a hard seal.
- **Print orientation** — flat, no supports.

### Fork-yoke

→ **[drawings/yoke.svg](drawings/yoke.svg)**

- **DT880-style fork** that straddles the cup.
- **Screw-pin pivot** — M3 shoulder screw through each fork arm into a heat-set insert in the cup
  (see Interface 2).
- **Tilt ±20°**, with hard stops in the geometry to protect the cable.
- **Carried by the slider** at the top; the slider provides swivel and height.
- **Left/right** — mirror images, two files.

### Slider

→ **[drawings/slider.svg](drawings/slider.svg)**

- **Printed clamp that rides the bow** — provides **height adjustment** and **swivel**.
- **Adjustment mechanism open** — friction (a printed spring arm pressing the steel) vs. detent
  (punched holes in the bow for click-fit) is undecided; with a real Beyer bow there's also the
  option to **reuse Beyer's metal wiper** instead of printing the spring.
- **Carries the fork-yoke** below it.

### Headband / bow

→ **[drawings/bow.svg](drawings/bow.svg)**

- **Primary: Beyerdynamic Metal Head Bow as a drop-in.** Sourced ready-made (~$11). Design the
  slider/mount to accept it directly.
  Source: <https://north-america.beyerdynamic.com/p/metal-head-bow>
- **Option: DIY 1095 spring steel** to the **same geometry** — laser-cut a flat developed profile
  (e.g. SendCutSend), form cold over a printed radius jig. For builders who'd rather make it than
  buy it, or where the Beyer part isn't available.
- **Exact bow dimensions are TBD from the measured part** — width is ~10 mm class; arc radius,
  developed length, and the wiper/detent interface all come from a real bow on the bench.

### Cable

- **Dual entry** — each cup has its own exit; Y-split at chin level. No routing through the bow.
- **Strain relief** — raised ring at the entry; jacket clamped before it enters the cup.

---

## Component specifications

### Driver (parametric)

Design the baffle around named parameters, not a fixed part. Confirm the real numbers with
calipers and print a baffle test piece (a ~20-minute print) before committing a full cup set.

| Parameter | Starting value | Notes |
|---|---|---|
| Outer frame diameter (`driver_od`) | 42 mm | 38–42 mm class; **measure your actual driver** |
| Acoustic aperture (`driver_aperture`) | 35 mm | Driver fires through this; guard printed across it |
| Driver pocket (baffle back) | 42 mm | Frame seats into the rear pocket |
| Driver depth | 10 mm | Sets minimum cup interior depth |
| Cutout tolerance | +0.3 mm | Actual cut ≈ 35.3 mm for fit |
| Impedance target | 32 Ω | Works from phones/laptops, no amp |

**Candidate driver: Peerless HPD-40N16** — a ~40 mm dynamic that fits the class and the sonic
target. Treated as a **candidate**, not locked: the baffle stays parametric so the production
driver is confirmed late (smooth response without aggressive peaks above ~3 kHz, ideally with a
published measurement from another builder). Mount with damping and a rear air space.

### Ear pads

- **Dekoni Audio Universal 100 mm** (Beyer-type) — outer foam **⌀100 mm**, ear opening **⌀60 mm**
  (the ⌀60 is the *ear* hole, **not** the cup mount). The design is built to this pad. Price
  **~$30–45 (ESTIMATE)**.
- **Slips over the cup-rim lip** — the pad's skirt wraps a raised retaining ring at the cup's outer
  front edge (DT770-style); the lip is part of the structural cup, not the baffle.
- **Pad-mount = cup OD.** Set `cup_outer_diameter` to the Dekoni pad's actual cup-mount opening and
  the cup-rim lip follows. Current value **90 mm is ESTIMATE/TBD** — measure the pad's mounting lip
  with calipers before finalizing (don't confuse it with the ⌀100 foam OD or the ⌀60 ear hole).

### Head bow

| Parameter | Value | Notes |
|---|---|---|
| Primary part | Beyerdynamic Metal Head Bow | Drop-in, ~$11 — [source](https://north-america.beyerdynamic.com/p/metal-head-bow) |
| DIY alternative | 1095 high-carbon spring steel | Laser-cut flat profile, formed cold over a jig |
| Width | ~10 mm | Standard headband width; **confirm from the measured bow** |
| Thickness | ~0.7 mm class | 0.6 mm lighter, 0.8 mm firmer (DIY route) |
| Arc radius / length | **TBD from measured part** | Slider + jig geometry derive from the real bow |

**DIY sourcing (the clever part).** Draw the arc as a *flat developed profile*, export a DXF, and
order it laser-cut in 1095 spring steel (e.g. SendCutSend, ~$10–15 at low quantity). They ship
flat blanks; form the curve cold over a printed radius jig — no metal shop, no minimums. The DXF
ships alongside the STLs. Cold-formed spring steel springs back ~10–15%, so cut the jig radius
10–15% *smaller* than target.

---

## 3D-print guidance

- **Material:** PETG (durable, slight flex — good for cups and the stressed yoke/slider) or PLA+
  (easy, rigid, fine for prototypes). Avoid brittle plain PLA on any stressed part.
- **Tolerances:** start 0.2 mm clearance for a friction fit, 0.3–0.4 mm for a slip fit; tune to
  your printer.
- **Heat-set inserts:** M3 brass inserts in printed bosses for any joint opened and closed (baffle
  rim, pivot) — far more durable than screwing into plastic.
- **Orientation:** best surface on visible faces; print the grille flat; orient the yoke so stress
  runs *along* layer lines, not across them (layer adhesion is the weak axis).
- **Supports:** designed to be support-free where possible (overhangs ≤45° chamfered).

---

## Parametric setup (for builders who want to modify it)

The model is driven by named parameters so it can be adapted without re-modeling. **All values are
first-pass starting points** (`params.py` is the single source of truth):

```
cup_interior_diameter = 78 mm
cup_depth             = 30 mm
wall_thickness        = 3 mm
driver_od             = 42 mm     ← update when driver confirmed
driver_aperture       = 35 mm     ← update when driver confirmed
cup_outer_diameter    = 90 mm     ← pad-driven; earpad lip on the cup rim (Dekoni ~90, TBD)
baffle_thickness      = 6 mm     ← driver/guard HUB (dome-gated); outer ring 4 mm (front recessed)
grille_ring_count     = 2
grille_spoke_count    = 8
grille_target_open_fraction = 0.40
grille_member_width   = 3.8 mm    ← held ≥ 2 mm for printability
pivot_tilt_degrees    = 20        ← ±20° fork tilt
```

**Cup approach — interior first.** Model the acoustic void as the primary geometry (revolve the
half-profile of the interior, then shell outward to `wall_thickness`), then add the integral
grille, the perimeter-wall bosses, and the pivot insert bosses. Build order: cup → baffle → yoke →
slider, each constrained by the part before it.

---

## Printing the parts without your own printer

If you don't have a printer, FDM print services (e.g. JLCPCB, Xometry) will print the part set
inexpensively — order a few iterations at once to batch the shipping wait. For a show finish on
the cups, an SLA service gives a smoother surface. Once a design is stable and you're iterating
often, an inexpensive desktop printer pays for itself quickly.

---

## Bill of materials (build-it-yourself)

Mirrors the assembly sheet ([drawings/assembly.svg](drawings/assembly.svg)).

| Component | Source | Est. cost |
|---|---|---|
| 1× Beyerdynamic Metal Head Bow | [beyerdynamic](https://north-america.beyerdynamic.com/p/metal-head-bow) | ~$11 |
| — or DIY 1095 spring-steel bow (laser-cut, formed) | SendCutSend + form | $8–15 |
| 2× ~40 mm driver, 32 Ω (candidate Peerless HPD-40N16) | Parts Express / Madisound | $8–25 |
| 1× Dekoni Universal 100 mm pads (Beyer-type) | Dekoni Audio | $30–45 |
| M3 heat-set inserts (baffle rim + pivots) | hardware/online | $1–2 |
| M3 screws — rim (socket/button) + pivot (shoulder) | hardware/online | $1–2 |
| Damping pack (foam + felt + fiberfill) | Parts Express | $3–5 |
| Cable + Y-split + 3.5 mm TRS plug | online | $8–15 |
| Printed parts (2× cup, baffle, fork-yoke, slider) | own printer or service | $3–25 |
| **Approx. total** | | **~$55–110** |

Own-printer build lands near the low end (filament only); print-service sourcing near the high end.

---

## Open design questions

These are the live problems still being worked — documented as the design develops.

**Bow geometry from the measured part.** The slider clamp, swivel, and (if DIY) the forming jig
all derive from the real Beyer Metal Head Bow's cross-section, arc radius, and length. Get one on
the bench and measure before committing slider geometry.

**Slider adjustment: friction vs. detent.** Printed spring-arm friction clamp, punched-hole
detents in the bow, or reuse of Beyer's metal wiper. Decide with a real bow in hand.

**Driver confirmation.** The baffle is parametric specifically so the production driver can be
locked late — update `driver_od` / `driver_aperture` and the baffle follows. Confirm the Peerless
HPD-40N16 (or alternative) against the selection criteria, ideally one with published measurements.

**Venting balance.** How much controlled leakage at the baffle interface vs. how much damping —
tuned by ear and measurement once a driver is in.

---

## Locked vs. open — for the form/industrial-design work

**Locked (the design must respect these):**

- **DT880-family architecture:** spring-steel bow → slider (height + swivel) → fork-yoke (±20°
  tilt) → cup → baffle → driver → pad. Each interface independently iterable.
- **Screw-pin pivot** at the yoke↔cup joint (M3 shoulder screw into a heat-set insert) — supersedes
  the old 6 mm post interface.
- **Front-mount baffle** — a clean driver-mount plate with the driver guard integral to it (no pad
  lip); rim screws into perimeter-wall cup bosses, hidden under the pad.
- Driver seat parametric to `driver_od`; baffle aperture to `driver_aperture`; integral guard
  protects the driver.
- **Earpad retaining lip on the cup's outer rim** (DT770-style); pad-mount = cup OD (Dekoni
  Universal 100 mm → ~90 mm, exact **TBD** — measure the pad's mounting lip).
- Circumaural fit; Beyerdynamic Metal Head Bow drop-in (or DIY 1095 to the same geometry).
- Standard 3.5 mm cable connector, dual entry.

**Open (the form playground / still to resolve):**

- Cup outer profile and overall form.
- Final rear-grille geometry within the hub + 2 rings + 8 spokes language (the signature look).
- Fork-yoke and slider styling within the pivot and clamp constraints.
- Slider adjustment mechanism (friction / detent / Beyer wiper).
- Color, finish, and overall aesthetic language.

---

*v0.3 · 2026-06-14 · Direction locked to the DT880 family (around-ear; spring-steel bow + fork-yoke
+ sliders). Resolved the pivot (screw-pin), the driver-guard location (baffle), the baffle mount
(front-mount, hidden screws), the cup bosses (blended into the perimeter wall), and the bow sourcing
(Beyer drop-in / DIY 1095). All dimensions first-pass pending measured parts. Geometry changes —
clean grille, wall bosses, driver guard, real yoke/slider/bow — come in the next engineering pass.
Open: bow geometry from the measured part, slider adjustment, production driver, venting balance.*

*Update (2026-06-25) · Earpad target switched to the **Dekoni Universal 100 mm** (Beyer-type); the
retaining lip moved from the baffle to the **cup's outer rim** (DT770-style), making the baffle a
clean driver-mount plate; the cup OD is now a **pad-driven 90 mm** (interior held at 78 mm, wall
6 mm). Cup OD is **ESTIMATE/TBD** pending a caliper read of the pad's cup-mount opening. See the
DESIGN-LOG for the full reasoning.*

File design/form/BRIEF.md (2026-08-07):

# First Chair — design brief

**Design me a headphone.** Not a variation on one I've already drawn — I have that, and it is
the problem. I want to see what you'd do with the constraints, not watch you execute my answer.

Previous passes failed because I over-specified: I handed over a parts list, a mechanism, exact
dimensions and a naming contract, and then was disappointed to get back a rearrangement of the
product I already had. This brief gives you the constraints that are genuinely fixed, the goals
that matter, and then gets out of the way.

---

## 1. What it is, and who it's for

An **open-back supra-aural (on-ear) headphone**, 3D printed, open source, built at home by
someone who owns a printer and has never built a headphone before.

It is the **first rung of a learning path**. Not the cheapest, not the simplest — the *first*.
Someone builds this, it works, it sounds good enough to keep wearing, and they believe they can
build the next one. That is the whole job.

The character we're accepting honestly: a supra-aural leaks by design, so it will be **bass-
light**. Grado is the reference point and Grados are famously bass-light *and* famously
unfussy about placement — those are the same fact. We lean into it rather than chasing
extension the hardware can't produce.

## 2. What is genuinely fixed — and why

Everything here is set from **outside** the design. None of it is my taste.

**A 40 mm dynamic driver.** Ø39.5 measured frame, ~32 Ω. Bought. 40 mm is the standard size and
we're not designing around a specialty part.

**A commodity Grado-pattern earpad. We design and ship no pad.** This is the single most
constraining thing in the brief and it works inward:

> The foam stretches over a rim of about **Ø54**, then grips a body of about **Ø48** behind a
> step of about **3 mm**. Retention is *axial* — the lip stops it climbing forward. Radially
> it's light: the pad rotates freely on the cup but doesn't slide off.

Those numbers have real tolerance — the same pads fit cups across Ø54–56.7 — so treat the
**relationship** as fixed and the exact figures as approximate. It must mount a pad someone can
buy for ten dollars, in a dozen variants, forever.

**Printed on an FDM machine.** 0.4 mm nozzle, 0.2 mm layers, PETG. Nothing thinner than 2 mm.
**Support-free is a constraint, not a preference** — if a part needs supports it's the wrong
part. Layer lines run *along* the load on anything structural; layer adhesion is the weak axis
and that's what snaps.

**No printed springs.** FDM plastics creep under sustained strain. A printed band works on day
one and is loose by month three — the most likely way this build disappoints someone.

**Fasteners: M3 only.** M3 heat-set inserts, M3 screws, M3 washers. One thread, one insert
size, all metric. Not fewer fasteners at the cost of variety — *one kind*.

**Real heads.** Ear-to-ear is roughly 147 mm at the 50th percentile, ~140–155 across adults.
Clamp force in the HD 600 / DT 770 class — but note that force on a supra-aural concentrates on
the ear rather than spreading onto the skull, so the *pressure* is much higher. Comfort is a
first-order problem here, not a finishing touch.

## 3. What is yours to decide — explicitly

I have previously prescribed every one of these. **I am not prescribing them now.**

- **The part breakdown.** How many parts, what they are, where they split. There does not have
  to be a "cup" and a "baffle" and a "clamp ring" — that's just what I did last time.
- **How the driver is held**, and whether the thing holding it is the same thing the pad mounts to.
- **How deep it is, how thick the walls are, how much volume is behind the driver.**
- **The rear treatment.** It must be acoustically open — you can see through to the driver — but
  what that looks like is open.
- **How it attaches to the head.** A sprung steel band is what I have; anything that clamps
  without a printed spring is fair game.
- **Whether height adjustment exists at all**, and how. My last mechanism was a post and a
  thumbscrew. It's gone. Discrete positions, a compliant layer, or nothing are all on the table.
- **How many rotation axes, and how they're achieved.** A joint is one answer. A printed
  variant is another. So is doing without.
- **Cable entry**, and how the driver gets wired.

## 4. What it has to actually do

Functions, not parts. Solve these however you like:

1. Hold a 40 mm driver at a controlled distance and angle from the ear
2. Present a rim a commodity Grado-pattern pad mounts to
3. Let the back radiate freely
4. Carry the whole thing on a head at a comfortable, consistent clamp force
5. Fit adult heads across the range
6. Get a cable to the driver
7. **Come apart and go back together, repeatedly.** The person building this will take it apart
   more than once. When serviceability and manufacturability conflict, serviceability wins.

## 5. The character

From the design letter I wrote to the industrial designer on my last headphone:

> *"Something that lasts a lifetime and gets passed down. It should exude quality craftsmanship,
> **almost looking handmade but with extreme precision**. Parts should be easily replaceable and
> durable. Reduce weight wherever possible."*

**And the house language is the print process itself.** Not applied to the object — generated by
it. With one filament, material can't separate parts, so *form* has to: profile, section change,
how an edge breaks, how one part meets the next. A printed part that owns its layer direction is
on-brief. One pretending to be injection-moulded is not. Fasteners are visible and that's fine —
deliberate, neither hidden nor fetishised.

Five rules, from the corrections I gave that designer:

1. **If a mechanism isn't needed, delete it.** I killed a fold hinge with *"an extra weakness we
   do not need."* Not "unnecessary" — a **weakness**.
2. **No ornament.** *"I am assuming this is for aesthetic reasons? I do not have to have this."*
3. **Simplify until it's simple, then stop before it's ugly.** Austere is not resolved.
4. **Material follows load.** Beefy where it works, gone where it doesn't.
5. **The prototype settles arguments, not the drawing.**

**The sentence the design has to survive:** *"The only parts not 3D printed are ___."* If that
can't be finished in a short breath, it isn't a 3D printed headphone — it's a buy-a-lot-of-parts-
and-print-a-few headphone. Target answer: screws, drivers, earpads, cable, and whatever provides
the spring.

## 6. Don't drift

- **It must not read as a shrunken over-ear.** A supra-aural sits *on* the ear; it's a different
  object, not a small version of another one. This is the failure mode I keep hitting.
- **Don't design for a factory.** No bezel-and-inlay, no polished collars, no four-material
  palette. Those are machining languages and we have one filament.
- **Don't make it precious.** Someone is printing this at home in PETG.

## 7. What I need back, and why

You can't produce a printable part — no booleans, no fillets, no tolerances — so I re-author the
chosen direction by hand in parametric CAD. **These five make that handoff clean, and none of
them constrain what you design:**

1. **1 unit = 1 mm.** glTF defaults to metres; unspecified, a model imports at 1/1000 into a
   slicer and nothing errors.
2. **Every number in one constants block** at the top.
3. **Build shapes from explicit profile arrays or curves**, not hardcoded primitives — a lathe
   profile as a list of `[radius, depth]` points is *directly* re-authorable by me. This is the
   single most useful thing you can do.
4. **One named node per part.** Your names, `_R`/`_L` for sides. Tell me what you chose.
5. **State the parts list and the rules in words.** I re-derive from rules; the geometry is the
   sanity check.

**GLB only, never OBJ** — OBJ has no scene graph and loses the hierarchy.

## 8. The deliverable

**Three directions**, each a genuinely different answer to §4 — not three finishes on one idea.
State each one's rule in words *before* you model it.

One page, one live 3D stage, nav switching between them. One line per direction on **what
doesn't close** — a stated conflict is worth more to me than a resolved-looking render, and it's
been the most valuable thing you've produced.

**No written study. If it isn't in the stage, it doesn't exist.**

---

*Context if you want it — my own prior headphone work is in `design/form/reference/` with
captions, and `docs/prior-art.md` records what we've studied and what's off-limits. Read them
as background, not as a template. `params.py` describes the design I'm replacing; don't take
numbers from it.*

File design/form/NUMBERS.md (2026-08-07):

# First Chair — the numbers a form pass needs

**This file, not `params.py`.** `params.py` is the engineering source of truth for the *CAD*,
and it still carries a mechanism that was deleted by decision in August — a design pass told to
treat it as authoritative will faithfully redraw a thumbscrew, because that is what it says.
This file is the subset that is true, current, and relevant to form.

If something you need isn't here, ask. Don't infer it from `params.py`.

## Cup — LOCKED, regenerates everything

```
pad rim / front plate     Ø 54.0      the Grado pad-mount interoperability dimension
cup body                  Ø 48.0      what the pad grips, behind the lip
lip depth                    3.0      the step the pad hooks behind — retention is AXIAL
cup interior              Ø 42.0      → 3.0 mm wall
overall depth               27.6      front face to back face
grille zone               r 19.0      = interior/2 − 2.0 landing ring
```

## Driver and pad

```
driver OD                 Ø 39.5      MEASURED. "40 mm" is the nominal name
earpad OD                 Ø 60.0      commodity Grado pattern — we design and ship none
earpad opening            Ø 38.0      ESTIMATE, caliper pending
earpad depth                 9.0      a FLAT pad; bowls are thicker. Swapping is the tonal lever
```

## Bow — bought, measured off the real part

```
relaxed arc radius          63.5      a 5 inch circle
flexed on a head           ~78.0      this sets ear spacing
developed length           236.2      rolled flat
strap width                 33.0      a STRAP, not a wire
strap thickness              0.8
end tabs                   2 prongs ~7 wide, Ø3.2 hole 5 mm from each tip, 26.0 apart
```

Central ~110 mm carries an X-brace cut-out. **No printed springs** — no FDM plastic is a good
spring; a printed band works on day one and is loose by month three.

## Cup ↔ yoke pivot

```
pivot centres             Ø 56.0      = body 48 + 2 × 4 proud
pivot boss                Ø  8.0
boss stands proud            4.0      room for the insert and the arm seat
```

## Print constraints — these are design inputs, not manufacturing notes

```
nozzle / layer            0.4 / 0.2
minimum member               2.0      anything thinner is not printable here
minimum wall                 2.0      design wall is 3.0
structural sections          4.0      anything carrying bending load
```

**Support-free is a design constraint on every part, not a preference.** Layer lines run *along*
the load on anything structural — the yoke arms especially, where layer adhesion is the weak
axis and printing flat-in-plane is the difference between a part that lasts and one that snaps.

## Fasteners — the target

**M3 heat-set inserts, M3 cap screws, M3 washers. Nothing else.** One thread, one insert size,
all metric. Heat-set inserts are kept deliberately: an insert is a small cylindrical bore, where
a captured nut needs a hex pocket, capture geometry, an access slot and clear space *behind* the
joint — and it gives a reusable thread, which a build for tweakers wants.

## What does NOT exist yet

**There is no height-adjustment mechanism, and no slider.** Do not draw one, and do not infer
one from anything you find in the repo. The Daily Driver post-and-thumbscrew that appears in
`params.py` was deleted by decision in August and has never been replaced.

What replaces it is an open question, not a pending implementation:

- a printed cantilever leaf riding a detent ladder, or
- **no height adjustment at all** — discrete positions, or a compliant suspension layer

If a direction needs to take a position on this to be coherent, **say which one it assumes and
why**, and treat it as a proposal rather than a given.

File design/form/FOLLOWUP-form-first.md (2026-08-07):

Stop. We've had the process backwards and I want to reverse it.

## The order was wrong

We've been building parts and then trying to make the assembly elegant. That's the engineering order, and it's why everything reads as primitives butted together — because that's what it is.

The right order is form first:

1. **This pass — one continuous form.** No parts.
2. **Next — split that form into parts.** Where the baffle separates, where the yoke attaches, where the pad rim sits. Serviceability and printability enter here.
3. **After — details.** Grille, mark, fasteners, the treatment at each joint.
4. Then I re-author it as engineered CAD by hand.

## This pass: one body per product, no parts at all

Each product is **one continuous form** — the ear unit and the arm that carries it, flowing into each other. No part lines. No joints. No bosses, no fasteners, no grille, no rim step, no clamp ring. Nothing that implies assembly.

I want to judge it as an **object** before it becomes an assembly.

**Build each as a profile, lofted or swept — not a stack of primitives.** If a section changes, it changes through the loft. If something is round, the roundness lives in the profile curve. Where the arm meets the cup, that's one surface changing section, not two shapes meeting.

This plays to what you're good at. With no boolean operations you can't cut features into a body anyway — so a single continuous lofted body is your strongest mode, and assembling primitives is your weakest. I've been asking for the wrong one and then complaining that it looks assembled.

It also sets up step 2 properly: **if the form is a profile, splitting it into parts is a split of the profile, not a boolean.** The whole path stays inside what you can actually do.

## Reference, in the repo

`design/form/reference/shape-sketches-overview.jpg` — six cup outlines, and note the **waisted stem flowing into each one**. No step, no boss, no joint. That is the level of resolution I want back from this pass, in 3D.

The headband blanks in the same folder are the same idea in metal: one continuous taper over the whole length, and where a cut ends it ends in a teardrop.

## What I want back

The **four products, each as one body**, at true relative scale — First Chair, Daily Driver, Session, Encore. Three directions to choose between. One live 3D stage, nav switches between them. Rule stated in words first, one line on what doesn't close.

Numbers from `params.py`. Nothing else.

Don't hand me a written study. If it isn't in the stage it doesn't exist.

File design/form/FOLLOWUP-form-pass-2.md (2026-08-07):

Next pass. Same project — keep `model.js`, refine it. Don't start over.

## Scope: family and form only

Four ear units and the thing that connects them to the head. **No details this pass** — no grille patterns, no logo marks, no fasteners, no port plugs, no clamp rings. Silhouette, proportion, and how parts meet. Details come after the language is right.

And show every direction **as all four products**, not as First Chair with siblings attached. I'm choosing a family language, not a cup.

## The deliverable is geometry

One page. One live 3D stage. The nav switches between **modelled** directions you can orbit.

**If it isn't in the stage, it doesn't exist.** No separate written study — last pass produced a 39 KB document and a viewer, and the document is what I saw. One paragraph of rule per direction, in the panel beside the stage, and one line on what doesn't close. That's all the prose I want.

## What's wrong with the current model, precisely

It's **assembled from primitives**. Stepped cylinders, boss cylinders stuck on the side, box webs, 0.6 mm bevels. Every junction is a butt joint between two shapes. Nothing flows into anything else.

That is what reads as clunky — not the proportions, which are fine, and not the numbers, which are right.

**Elegance here is transitions.** Look again at three things in the repo reference folder:

- `shape-sketches-overview.jpg` — the yoke stem **waists and flares** into the cup. One continuous curve, no step. That's the single best detail in any of my prior work and nothing you've built has it.
- the headband blanks — the taper is continuous over the whole length, and every slot **terminates in a teardrop**, never a square end.
- the prototypes — the cup wall runs into the pad rim without a ledge announcing it.

So: where two parts meet, make it a transition, not an abutment. Where a section changes, change it continuously. Where a cut ends, round it out.

## Don't over-correct into bare

Rule 3 from the brief, both halves: *"simplify without looking ugly. Hopefully we can find a nice middle ground."* Direction A last pass — concentric steps, zero draft — is the stripped-bare failure, not the simple success. Austere is not the same as resolved.

## Numbers

Take them from `params.py` in the repo, not from my prose. If it disagrees with anything I've written, say so — that's a bug worth knowing about.

## Same two habits

State the rule in words before you model. Say plainly what doesn't close. Both have been the most useful things you've done.

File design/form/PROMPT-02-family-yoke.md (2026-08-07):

This is a second pass on the **makerphones family form study** (the four-product one: First Chair, Daily Driver, Session, Encore). Keep everything that's there. This pass is about **one part: the yoke.**

## What's working — don't touch it

The ratio system is right. `RULES` R1–R6, and especially the decision that the only absolute numbers are the ones physics fixes — driver Ø, `EAR_CLEAR = 64`, `BOW_R = 108`. **The head doesn't scale**, and building the family around that is exactly correct. The relative scale across the four reads properly. The earcups are a good first pass.

Leave the earcups alone this round. I don't want to refine detail until the family's design language is settled.

## What's wrong: the yoke

Three things, and the third is the one I care about.

**1. It's too thick.** It reads as a slab, not a considered part.

**2. It's identical across all four products, and that's wrong.** The loads aren't identical — a Ø54 on-ear cup is a fraction of the mass of a Ø96 Encore cup, on a shorter arm. Every other dimension in the study derives from something; the yoke doesn't derive from anything, it's just repeated. That's the weak kind of family — a repeated detail rather than a rule. **Give the yoke a rule**, like everything else has: its section should follow the load it actually carries.

**3. It isn't elegant, and it should be the part that is.** The yoke is the only part with visible structure doing visible work. Right now it's the ugliest thing in the study.

## The constraint that's also the opportunity

The yoke **must print flat in its own plane, with the layer lines running along the arm.** That's not a preference — it carries bending load, layer adhesion is the weak axis, and this is the difference between a yoke that lasts and one that snaps.

So it's effectively a 2.5D part, and that tells you where elegance can come from:

- **Thickness is expensive to vary** — it's the print's Z and it's what the strength depends on.
- **The profile in the print plane is completely free.** Waisting, tapering, a swept outline, a cut-out, a section that changes along the arm's length, a shaped transition into the eye — all of it costs nothing to print and nothing in strength if the material follows the bending moment.

**That's the lever: shape the silhouette, don't thin the slab.** A part that's widest where the moment is highest and narrowest where it isn't looks designed, is stronger for its mass, and is the honest expression of a printed structural part. Thinning it uniformly just makes it weaker and still slabby.

## What I want back

**State the rule in words before you model anything.** Then:

1. **A yoke rule for the family** — how section, profile and arm length derive from the cup they carry, so First Chair's yoke and Encore's are visibly siblings but not the same part. Show me the numbers it produces at all four sizes.

2. **Three alternative yoke forms** built on that rule, so I can pick a language rather than approve a part. For each, say what it does at Ø54 and at Ø96, because the small one is where an elegant profile is hardest to keep.

3. **How the yoke meets the cup and the slider** in each — those two joints are most of what the eye reads, and right now they're abrupt.

## Two corrections to fold in

**Use my locked First Chair numbers exactly.** Your `derive()` currently gives Ø48.21 body and 27.4 depth; the locked values are **Ø48.0 body** and **27.6 depth**. The difference is trivial physically but these are round numbers on purpose. Bend the formula to hit them — `bodyD = d / 1.125` gives exactly 48.0 at Ø54, and `depth = 22.2 + 0.10·Ø` gives exactly 27.6 at Ø54 and 31.3 at Ø91. Keep your correction that depth is driver-and-ear driven rather than a fraction of Ø — that was right, and it's why the 0.51·Ø rule from the other study fails at Ø91.

**Flag it, don't hide it:** your rule gives Daily Driver a Ø81.3 body behind a Ø91 baffle. Daily Driver is already a shipped design and has no lip-and-body split — its outer diameter *is* its body. So this rule would change an existing product. I may well want that for family coherence, but tell me plainly what changes rather than quietly restyling it.

## Conventions — unchanged

Authored **1 unit = 1 mm**. **GLB, never OBJ.** Mesh names to the same contract you're already using — `cup_R`/`_L`, `yoke_R`/`_L`, `yoke_rod_R`/`_L`, with the side mirror. And if a number doesn't close, say so rather than fudging it — the stated conflicts in your last pass were the most useful part of it.

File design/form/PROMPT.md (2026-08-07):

I'm designing an open-back **supra-aural (on-ear)** headphone around a 40 mm driver — 3D-printed, fully parametric, open source, meant to be downloaded and forked by hobbyist builders. It's the flagship first build of a series: the first rung of a learning path, not the last.

I want **3–5 distinct form directions** to choose between. **Before you model anything, state the rule each direction is built on, in words.**

## What I have now, and why it's wrong

This build was forked from my over-ear headphone. I reset the dimensions to on-ear numbers but never redesigned the *form*, so the CAD is a **shrunken over-ear**: a convex domed cup from a DT880-family design, a circumaural stance, and (until yesterday) over-ear pads sitting on a 54 mm rim. Dimensionally correct, formally the wrong product.

**A supra-aural is a different object, not a small version of another object.** It sits *on* the ear: small cup, small pad, light band, close to the head. That's the thing to design.

## Locked — a direction that breaks one of these is out, however good it looks

```
front plate / pad rim     Ø 54.0     the pad-mount interoperability dimension
cup body                  Ø 48.0     what the pad grips, behind a 3.0 mm lip
cup interior              Ø 42.0     → 3.0 mm wall
overall cup depth            27.6
driver                       40 mm
```

Architecture: a **bought sprung steel bow** (screwed at its end tabs) → printed slider → printed yoke → printed cup + a **separate** baffle + a printed driver clamp ring. **Three degrees of freedom**: swivel and tilt at the cup, plus vertical slider travel.

Pads are a **commodity Grado-pattern part I don't design or ship** — the foam stretches over the Ø54 lip and grips the Ø48 body behind it. That step is the retention feature. Smaller pads are preferred: my own measurements show a small-padded on-ear is ~2.5× more repeatable through 2–8 kHz than a large-padded one, and repeatability is what this design competes on.

No printed springs — no FDM plastic is a good spring, so the band stays steel. Serviceability beats manufacturability throughout; the user is a tweaker who will take it apart.

## The reference, and the boundary on it

**Grado is the architectural reference, not the styling target.** It's right about *what a supra-aural is*: small cup, rod-in-block gimbal, minimal band, flat rear face, everything visible and serviceable. It's the wrong thing to copy — cloning it would be the least interesting version of this project. Where I diverge on purpose:

| Grado does | I do | Why |
|---|---|---|
| Barrel profile from wood turning | Whatever prints well | A barrel is a *lathe* form; inheriting it copies a manufacturing process I don't use |
| A separate Ø45 × 2 mm screen disc | Integral printed grille | One fewer part to source |
| Driver registered behind a restricted aperture | Aperture as a free acoustic variable | My clamp ring means the aperture needn't double as the register |
| Glued / pressed assembly | Clamp ring, fully serviceable | The user takes it apart |

Don't reproduce Grado's geometry. Match the pad-mounting diameter — an interoperability dimension, like a screw thread — and nothing else.

## Two things I'll push back on, so please pre-empt them

**A "family" made by repeating a detail is the weak version.** I want **proportion and rule** — something that still works at Ø54 here and at Ø91 on the over-ear sibling, because those two have to read as siblings. This is why I want the rules in words first.

**Don't drift toward glossy injection-moulded consumer product.** This is a printed, bolted, serviceable object and should look like one. Visible fasteners are fine. Visible layer direction is fine. A parting line is not a flaw. The read I want is *honest engineering, pro-audio sensibility through a maker lens* — considered and functional, not flashy.

## Output conventions — the first two fail silently, so please confirm them explicitly

1. **Author at 1 unit = 1 mm.** glTF's spec convention is metres, so a model that doesn't state its units imports at 1/1000 into a slicer — a Ø54 cup arrives as a 0.054 mm speck, and nothing errors.
2. **GLB only, never OBJ.** OBJ has no scene graph — it carries groups, not parent/child nodes — so it structurally can't express the hierarchy below, which is the whole reason I'm using a 3D tool instead of an image tool.
3. **Name every mesh to this contract, exactly**, with `_R` / `_L` suffixes:

```
earcup         cup_R/L · baffle_R/L · driver_R/L · driver_clamp_R/L
earpad         earpad_R/L
gimbal         yoke_R/L · yoke_rod_R/L
headband       bow_ref · slider_R/L · slider_shoe_R/L · headband_clamp_R/L · thumbscrew_R/L
headband pad   headband_pad
```

4. **Tell me what doesn't close.** If a number doesn't work, say so rather than fudging it. I'd much rather have a direction with a stated conflict than a mesh that hides one.

## What each direction should resolve

- the **rule** it's built on, in words, first
- the **cup profile** — the inherited convex dome is up for replacement
- how the **rear grille** reads — mine is a triangular lattice with a logo mark riding flush on it, currently proportioned for the wrong cup size
- the **gimbal** — mine is a fork-yoke inherited from the over-ear. Grado's rod-in-block gets one rotational axis for free; mine pushes both rotations out to designed joints, which makes the yoke the crowded part. Worth attacking.
- the **worn stance and silhouette** — the thing that most says "on-ear" or doesn't

One thing to keep in mind about what happens next: **you have no boolean operations, so nothing here becomes a printable part.** I re-author the chosen direction by hand in parametric CadQuery. Give me industrial-design intent — correctly scaled, correctly named, with the rules stated — and that handoff works cleanly.

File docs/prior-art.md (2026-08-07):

# Prior art — what we adopted, what we may not touch

`starting-a-new-product.md` requires confirming the prior-art boundary on every build:
**credit adopted ideas; never copy non-permissive files or geometry.** This file is where that
gets recorded, per source, before anything from it reaches a design decision.

This repo ships CAD publicly under **MIT**. That is the constraint every entry below is measured
against.

---

## Variable Openmod — Armored Soul (Variable Static Audio)

Three published designs, 2024–2025:

- Part 1 — <https://www.printables.com/model/818386>
- Part 2 — <https://www.printables.com/model/905734>
- Part 3 (headset) — <https://www.printables.com/model/1004464>
- Driver source list — <https://docs.google.com/spreadsheets/d/1I18ZVEiOJQHK4EqZPyXjhn9TTDELaiebMAgrZp_Bvf8>

### The licence, and why it is a hard boundary

**Creative Commons BY-NC-SA 4.0** — Attribution, NonCommercial, ShareAlike. Confirmed from the
Printables listing on all three parts. Two clauses are blockers rather than cautions:

- **ShareAlike is incompatible with MIT.** Any derivative of that work must itself be
  BY-NC-SA, and a BY-NC-SA derivative cannot be relicensed as MIT. Geometry from it entering
  this repo would take the repo's licensing with it.
- **NonCommercial forbids commercial use.** MakerPhones has a book with two assigned ISBNs and
  a plausible kit business. A derivative would be permanently barred from both.

Printables states as much on the page itself: **"✖ Meets Open Definition"** and **"✖ Free
Cultural Works."** Despite the title, BY-NC-SA does not meet the Open Source Definition. That
is the author's choice to make and it is a legitimate one — it is simply a different thing from
what this project is doing.

> **HARD BOUNDARY: none of their files, ever.** Not imported, not traced, not scaled, not
> measured-and-redrawn. The practical safeguard is the same one set for the Grado CAD — design
> ours from our own constraints, and do not have their files open while doing it.
>
> **The downloads must not enter this repo.** Not in `design/`, not in `reference/`, not
> gitignored inside it. An accidental `git add -A` would be expensive.

*(Not legal advice. The MIT-vs-ShareAlike conflict is not a grey area.)*

### What we adopted — ideas, methods and facts, which copyright does not cover

Credited here because it is right, and because the author was explicit that the series exists
as *"a base that people can build upon and improve."*

| Adopted | Why it matters to us |
|---|---|
| **Captured M4 hex nuts in printed pockets, instead of heat-set inserts** | Their whole fastener BOM is 10 × M4×20 pan-head + 10 × M4 DIN934 nuts. Ours was **22 heat-set inserts across three sizes, plus a soldering iron and the technique to use it**. First Chair exists because the Daily Driver's hardware was *"a wall for the person the manual is trying to reach"* — and we had removed the eight-supplier problem while keeping the technique problem. A captured nut costs pennies, ships anywhere, needs only a screwdriver. |
| **The rear shell as a separate, swappable part** | Their open/closed is a *part swap*; ours was a *parameter* — which is why deleting the closed-back variant deleted a whole capability. A part survives what a flag does not. They also ship `custom-open-shell` / `custom-closed-shell` as explicit hack points. |
| **Spacer-based pad adapters** | One mount plus a per-size spacer and ring reaches both Brainwavz HM5 and Sony MDR-XB1000. A direct answer to our "the pad decides the outline" rule: put an adapter layer in rather than redesigning the mount per pad. |
| **Ship a `-lower-tolerances` variant** | Rather than making the builder rescale for their printer. Cheap, and kind. |
| ~~Cross-generation part compatibility~~ **— CONSIDERED AND REJECTED 2026-08-07** | Their three products share a common parts kit, and I argued we should copy it. Wrong: part commonality is a manufacturing-economics answer to a **tooling** problem, and FDM has no tooling — a part costs the same printed once or four times. The payoff is zero and the cost is real, since a shared part must be sized for the worst case. Each of our products is a different size and shape, every part is printed individually, so each should be exactly what its product needs. We share the **bow** (a bought part, where tooling economics do apply) and **conventions**. Nothing else. |
| **Raw 1.75 mm TPU filament as a flexible component** | Part 3's BOM lists *"45 cm of unprinted 1.75 mm TPU filament"*. Using stock filament as a compliant element costs nothing and every builder already has it. |
| **BOM facts** — PJ392 socket, M4 DIN934, JST PH 2-pin, HM5 pads, MonsterBolts as a source | Part numbers and suppliers are facts, not expression. |
| **The driver source list** | A directory of parts and suppliers — factual data. Our brief calls choosing the driver *"the gate on everything else"*, so this is materially useful and entirely safe. |

### The architecture, read from their CAD (2026-08-07)

Measured from the published `.3mf` parts — bounding boxes only, to understand how it is put
together. No geometry taken.

```
EARCUP — three stacked plates, not a cup
  40mm-pad-mount.3mf     96 × 96 ×  5.0      driver-size specific, ±grille
  40mm-body.3mf         106 × 100 × 12.2     driver-size specific
  open/closed-shell     100 × 100 × 18.0     SHARED across every 40–60 mm driver
                                    ─────
                                     35.2 mm total depth, in three shallow plates

HEADBAND
  headband-arc          183 × 114.6 × 36     the band, 36 wide
  tpu-suspension-pad    200 ×  60  ×  1.5    a FLAT 1.5 mm sheet that flexes into shape
  yoke                  100 ×  71  × 10.0    a flat arc; mk2 11.1, 90°-variant 11.5
  headband-clip          36 ×  12  ×  9.2
  screw-holder           10 ×  10  × 12.2    the captured-nut part — IDENTICAL in Part 1 and 2
```

**The finding that matters more than any of the individual ideas: every part is a shallow,
flat-printing plate.** 5 mm, 12 mm, 18 mm, 10 mm, 1.5 mm. Nothing is a deep cup. Their 35 mm
of earcup depth is *three plates stacked*, which is how the listing can claim **"easy to print
out without any supports"** and mean it.

That is not a styling decision. **It is the print constraint doing the architecture** — and it
is the answer to a question this project has been circling for days. We went looking for a
house *language* and kept borrowing one from machined products. For a printed product the
language should fall out of what prints well: flat parts, no supports, layer lines along the
load. Their whole object is legible as that one rule applied consistently.

Ours, by contrast: one cup, 27.6 mm deep, printed grille-face-down with *"light supports
(pivot bosses)"*. Our brief demands support-free printing of the **yoke** and the **slider**
and says nothing at all about the cup. That is an inconsistency we imposed on ourselves.

Two more things the measurements give away:

- **Rotation is a file, not a joint.** `yoke.3mf`, `yoke-mk2.3mf`, `90-degree-rotation-yoke.3mf`
  share one 100 × 71 envelope. You do not build a swivel — you print the one you want. A whole
  degree of freedom's mechanism, deleted for the cost of an extra STL.
- **Height adjustment is clip position, not a slider.** There is no slider part anywhere in the
  bundle. Given ours is the hardest unsolved item in the build, that is worth a real look.

### The signal we should take most seriously

Part 3: *"you must have some experience with soldering before attempting this. It's a pain
trying to solder everything. **Which is why I made tools for it** to make it less of a pain."*

An experienced designer had to **build and publish separate tooling** to get past the soldering
step. That says the electrical assembly — not the mechanical — is the real barrier in a printed
headphone. Our brief has cable entry listed as an open question; it should be treated as a
first-class design problem, and the target should be *minimising or eliminating soldering*,
not documenting it better.

### What we deliberately did NOT adopt

**Their printed PETG headband.** Our position — no FDM plastic is a good spring, creep will
loosen it within months — is better evidenced, and it is backed by the maker's own experience
bending and tempering spring steel blanks. This is the one place our design is ahead.

### Context worth recording

The author states Part 3 is *"likely to be the last headphone I make and of course the last
open source headphone that is released,"* and the project website was **shut down for lack of
funds** in May 2025; the assembly instructions now survive only in the download bundle and the
Wayback Machine.

Noted without triumph — it is a real loss to the space, and the work was generous. But the
structural observation is worth keeping: **the NonCommercial clause foreclosed the funding path
that might have sustained it.** MakerPhones being MIT, with a commercial route, is a difference
in kind rather than a licensing preference.

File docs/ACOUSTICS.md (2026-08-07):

# First Chair — acoustic summary

**Generated by `build.py` — do not hand-edit; change `params.py`.** Figures are computed
from the geometry, so they track the design. Acoustic *tuning* (real damping amount, vent
open-area, exact volume target) is measurement-gated — these are the parametric starting points.

## Acoustic volumes

| Cavity | Volume | Set by |
|---|---|---|
| Rear (cup interior) | **30 cc** | ⌀42 mm × 28 mm deep |
| Front (ear ↔ baffle) | **10 cc** | pad opening ⌀38 mm × 9 mm pad depth |
| **Total** | **40 cc** | |

## Tuning controls (all parametric)

- **Back:** OPEN rear grille — First Chair is open-back, full stop (Session is the line's closed-back build).
- **Rear damping:** ⌀30 × 3 mm felt disc, seated in the cup's damping ring over the grille.
- **Front seal:** 1.5 mm foam gasket at ~33% squeeze (gate-checked into 30–50%).
- **Front cavity = pad depth** (9 mm) — the main tuning lever (swap pads).

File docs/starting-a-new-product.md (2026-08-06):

# Starting a new product (the template)

The "template" for product #2+ is **this repo** — fork it copy-on-write. There is no
separate skeleton to maintain (a parallel skeleton drifts from the live code; a fork
is always current). The value here is the **checklist of what to change**, so a new
product starts clean instead of half-edited.

> Hold until product #2 is actually greenlit. When it is, this is the cold-start.

## 1. Fork

```bash
cp -r builds/first-chair builds/<new-product>         # copy-on-write from the reference
cd builds/<new-product>
rm -rf .git && git init                               # its own standalone repo
rm -rf docs/DESIGN-LOG.md output/ docs/models/ docs/renders/   # start a fresh log + artifacts
```

Then run **`/headphone-intake`** → fill `BRIEF.md`. See `new-build-intake.md`
(pipeline), `decision-tree.md` (the order), `measurement-priorities.md` (what blocks
the first print).

## 1b. Run the form pass in Claude Design — BEFORE writing `params.py`

**This is the one point in the process where it has the most leverage and the least
risk**, and the ordering is the whole point: before `params.py` exists there is no
engineering to lose to a tool that cannot do booleans, and the output is a named part
list that reads straight into one. Afterwards it can only get in the way.

Seed the project with **this repo** and with `assembly.py`'s `SUBASSEMBLIES` naming
schema, then ask for the family rules **in words before it models anything** —
proportion and rule, not a repeated detail. Full process in `docs/design-pipeline.md`;
verified capability map in `warren-labs/docs/claude-design.md`.

Four conventions, and **two of them fail silently**:
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

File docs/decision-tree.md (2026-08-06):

# Decision tree — the order to lock choices

Eight iterations on the First Chair taught a dependency order: **lock the inputs,
derive the cup, derive the mechanism, build the chain, then style.** Following it
avoids the churn of re-deriving downstream parts when an upstream number changes.
Reusable for any new headphone (it's about dependencies, not this product).

```
0. FRAME          use-case & vibe ─────────────────────────────► colours every choice below
                       │
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

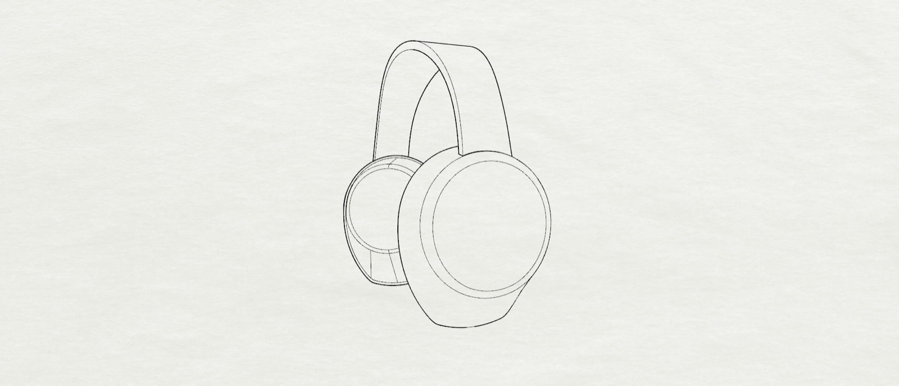
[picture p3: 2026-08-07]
design/form/reference/shape-sketch-3a.jpg

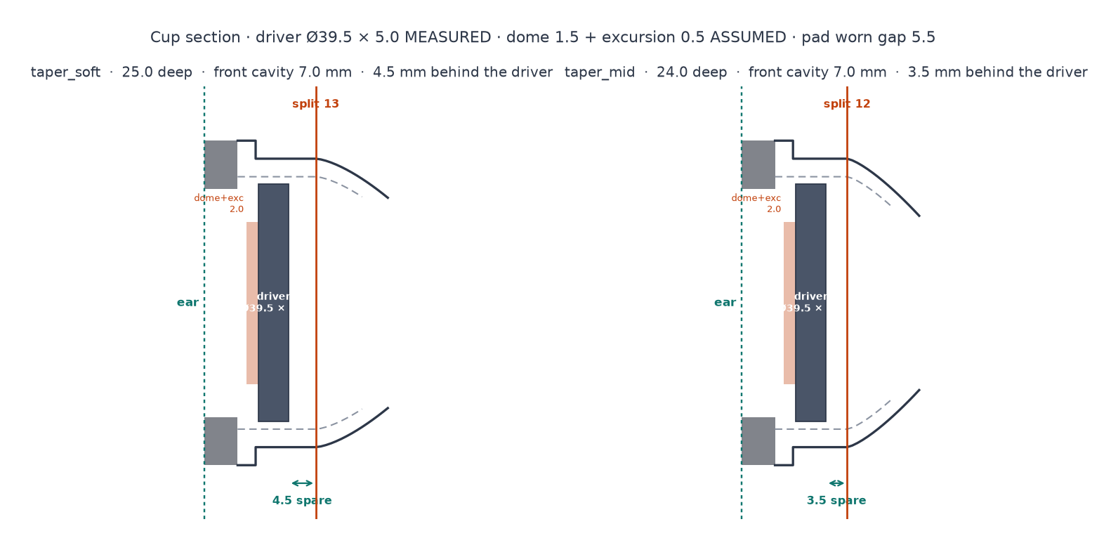
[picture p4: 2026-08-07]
design/form/profile-study/_section.png

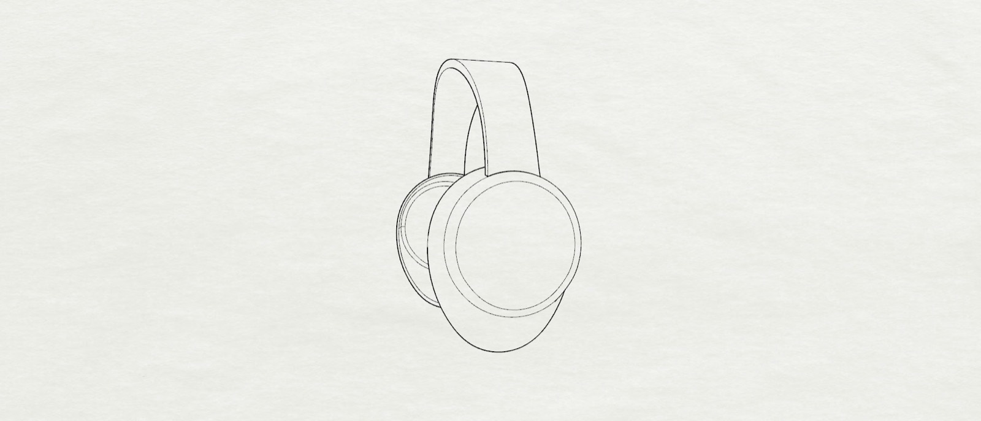
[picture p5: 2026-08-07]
design/form/reference/shape-sketch-5a.jpg

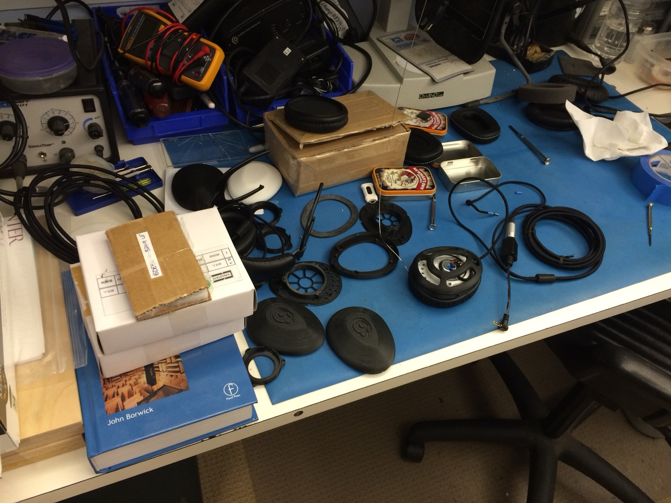
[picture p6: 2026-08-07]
design/form/reference/prototype-1.jpg

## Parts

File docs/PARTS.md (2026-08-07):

# First Chair — parts inventory

**Generated by `build.py` — do not hand-edit; add/remove parts in `build.py`.**

**13 parts total** — 3 printed · 4 accessory · 2 fit coupon · 4 reference. A full `build.py` / `gate.py` run reports **13/13**. Sourcing + quantities are in `BOM.md`.

## Printed

| Part | Output | Role |
|---|---|---|
| `cup` | STL + STEP | earcup shell — integral lattice grille, baffle bosses, pivot bosses, pad lip |
| `baffle` | STL + STEP | front driver plate — aperture, guard, controlled vents, driver seat + collar |
| `yoke` | STL + STEP | fork — tilts on the cup pivot, carries the height-adjust post |

## Accessory — printed, not in the reference assembly

| Part | Output | Role |
|---|---|---|
| `driver_clamp` | STL + STEP | 3-ear ring retaining the driver against the baffle back |
| `adapter_ring` | STL + STEP | step-down ring to host a smaller driver in a bigger baffle (optional) |
| `headband_pad` | STL + STEP | crown cushion under the bow (TPU) |
| `grille_dot` | STL + STEP | press-in accent cap at the grille centre (the mark's orange dot) |

## Fit coupon — printed QA tool, not in the assembly

| Part | Output | Role |
|---|---|---|
| `driver_coupon` | STL + STEP | FIT COUPON — driver seat/collar + clamp standoff interface (QA) |
| `pad_coupon` | STL + STEP | FIT COUPON — pad-skirt grip on the cup OD (QA) |

## Reference — not printed (bought part / mockup)

| Part | Output | Role |
|---|---|---|
| `bow` | STEP only | bought Beyer metal head bow (917017/973361) or DIY spring-steel blank (reference) |
| `yoke_rod` | STEP only | the adjustment-post shoulder screw, ISO 7379 Ø6×M5×50 (reference viz) |
| `driver` | STEP only | representative 40 mm driver mockup (reference) |
| `earpad` | STEP only | representative round earpad mockup (reference) |

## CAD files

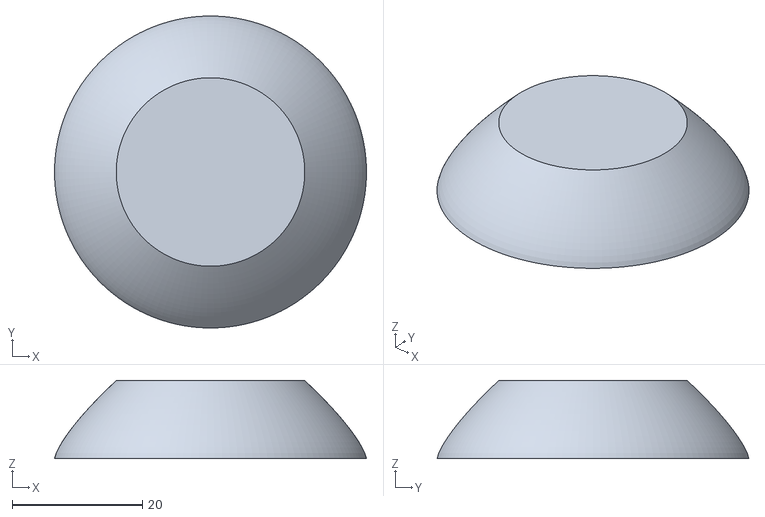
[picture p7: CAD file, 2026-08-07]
design/form/profile-study/joint-flush-rear.stl
48.0 x 48.0 x 12.0

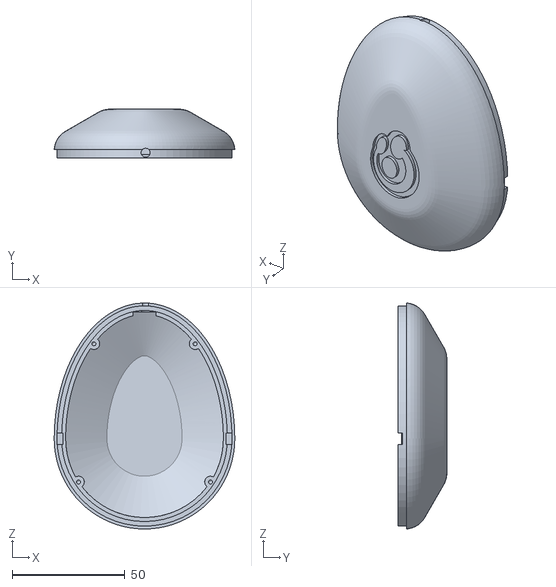
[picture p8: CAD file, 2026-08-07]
design/form/reference/earcup-07revB.stl
80.0 x 21.6 x 100.1

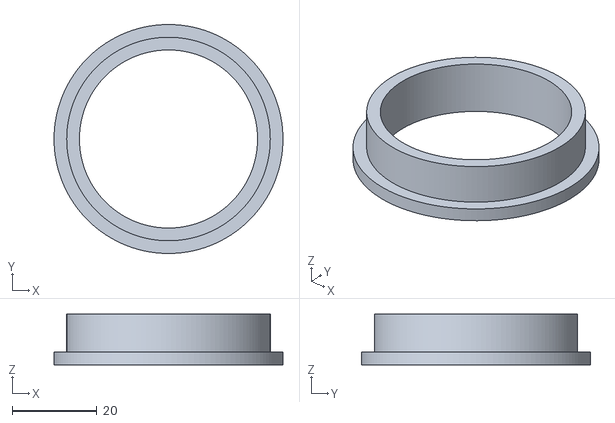
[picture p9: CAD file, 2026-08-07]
design/form/profile-study/joint-shadowgap12-front.stl
54.0 x 54.0 x 12.0

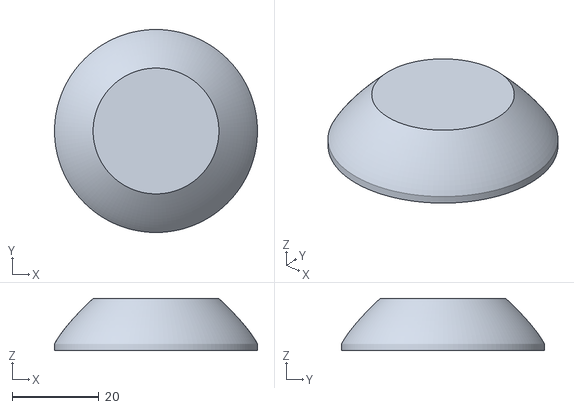
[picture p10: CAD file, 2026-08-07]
design/form/profile-study/joint-shadowgap06-rear.stl
46.8 x 46.8 x 12.0

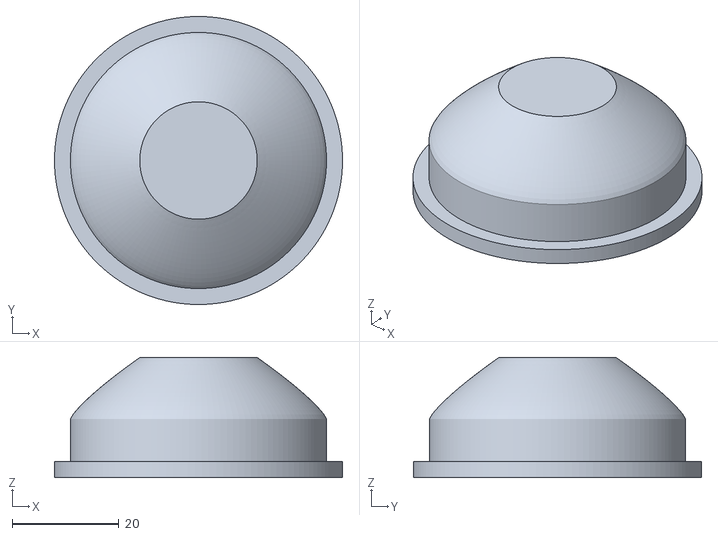
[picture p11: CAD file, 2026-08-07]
design/form/profile-study/taper_hard.stl
54.0 x 54.0 x 22.5

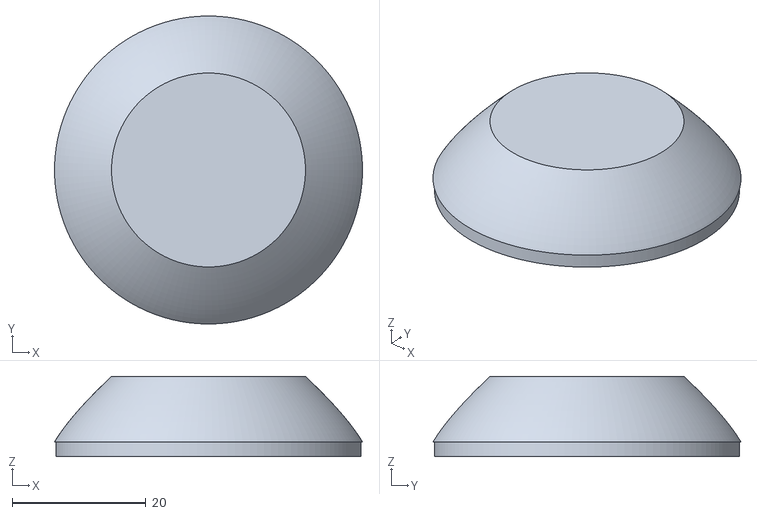
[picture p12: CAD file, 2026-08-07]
design/form/profile-study/joint-shadowgap12-rear.stl
46.1 x 46.0 x 12.0

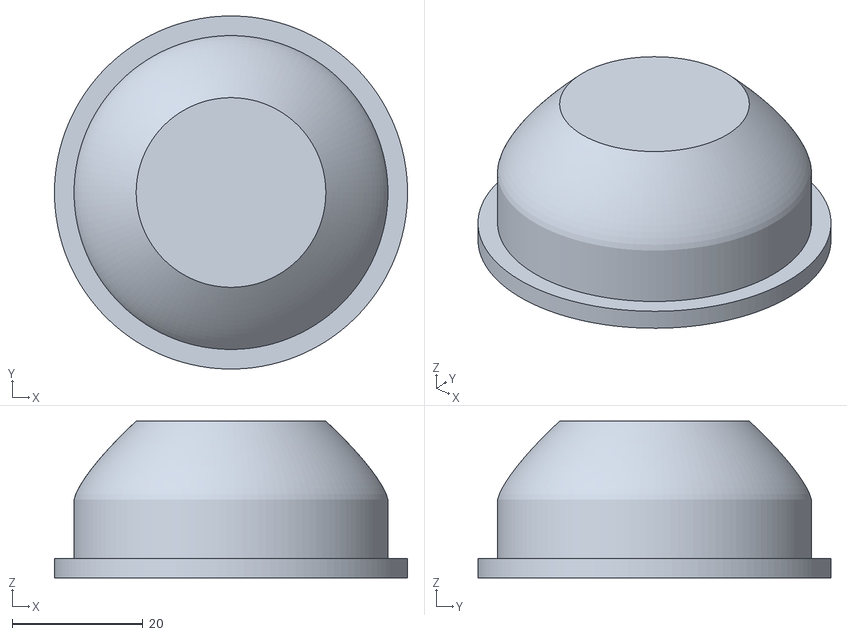
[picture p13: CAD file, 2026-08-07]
design/form/profile-study/taper_mid.stl
54.0 x 54.0 x 24.0

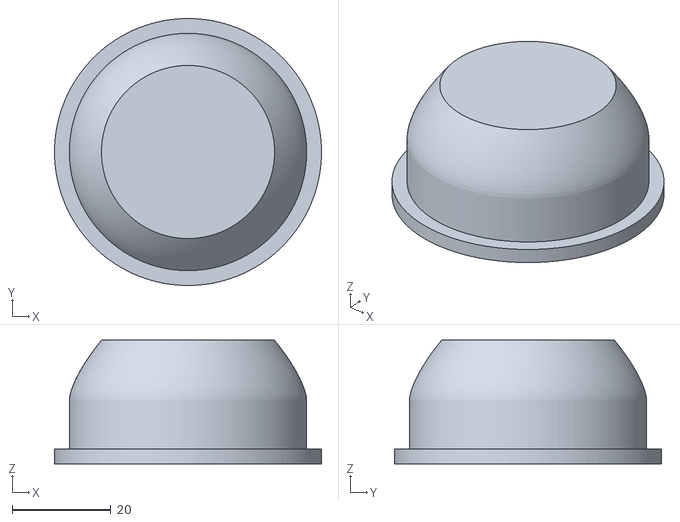
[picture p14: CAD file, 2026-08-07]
design/form/profile-study/taper_soft.stl
54.0 x 54.0 x 25.0

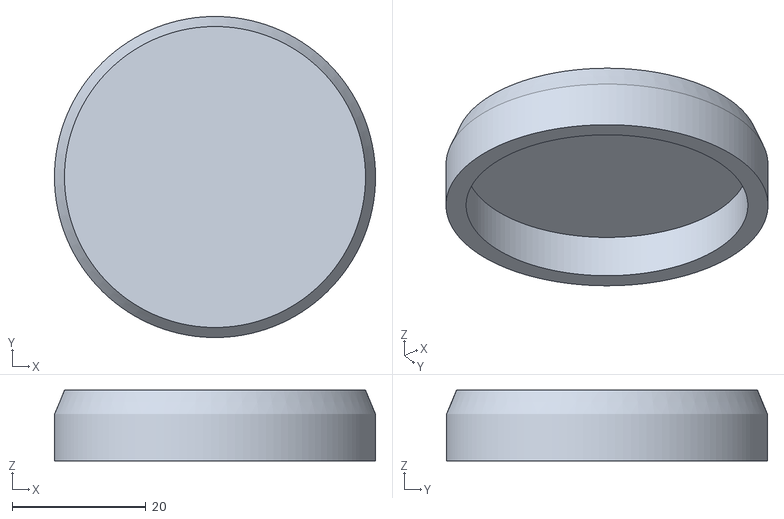
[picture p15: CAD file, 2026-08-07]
design/form/profile-study/split-shallow-rear.stl
48.0 x 48.0 x 10.6

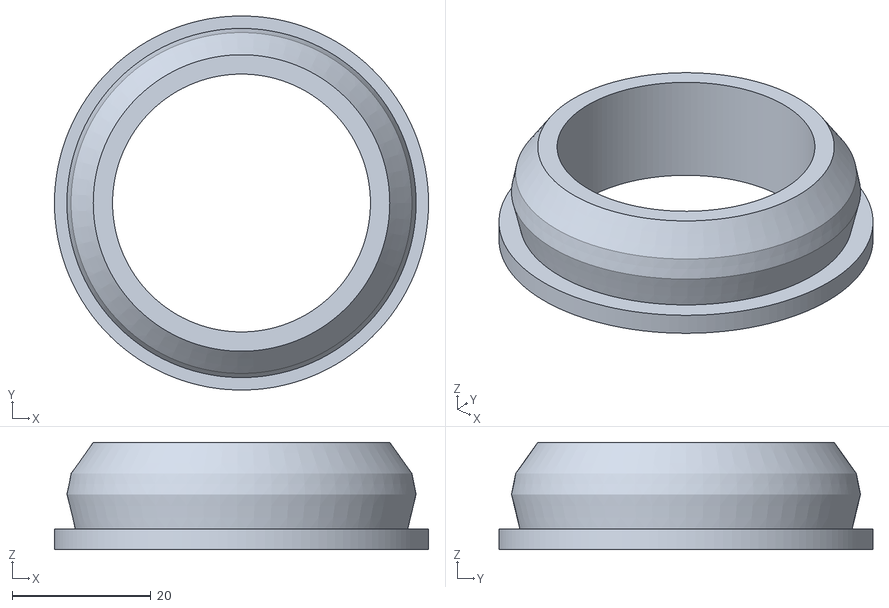
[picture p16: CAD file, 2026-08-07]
design/form/profile-study/split-waist_split-front.stl
54.0 x 54.0 x 15.5

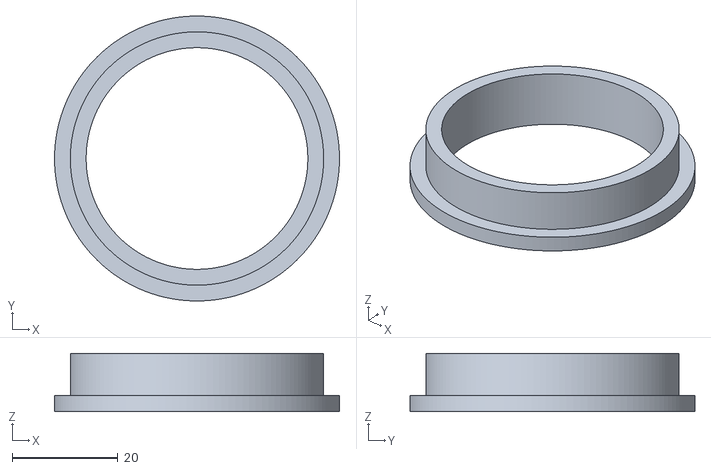
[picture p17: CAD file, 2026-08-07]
design/form/profile-study/split-shallow-front.stl
54.0 x 54.0 x 11.0

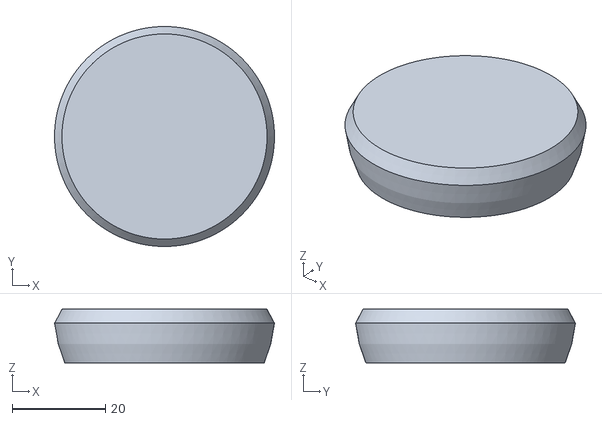
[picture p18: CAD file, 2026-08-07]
design/form/profile-study/split-waist_split-rear.stl
47.2 x 47.2 x 11.5

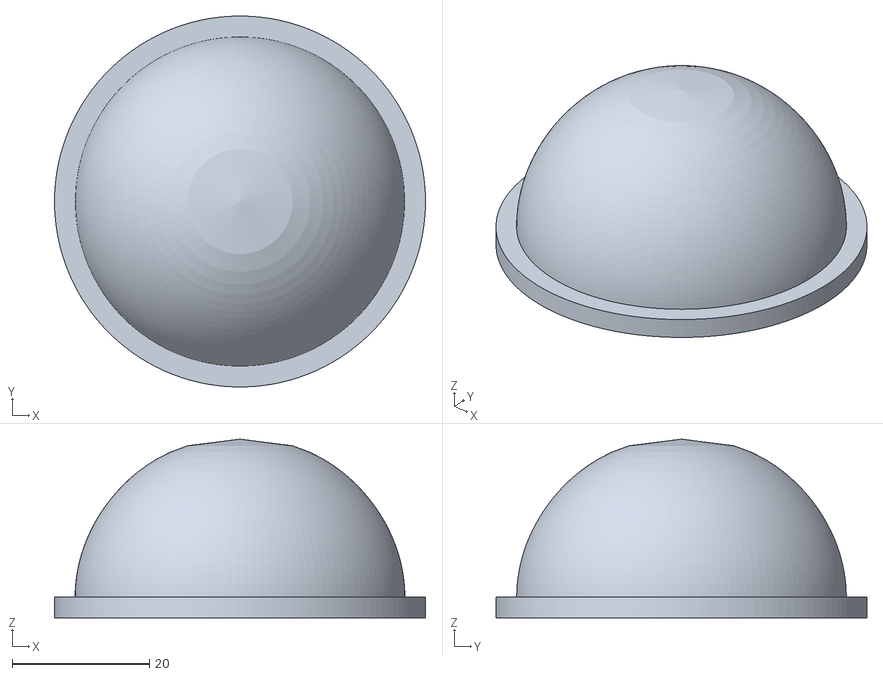
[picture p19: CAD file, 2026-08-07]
design/form/profile-study/bell.stl
54.0 x 54.0 x 26.0

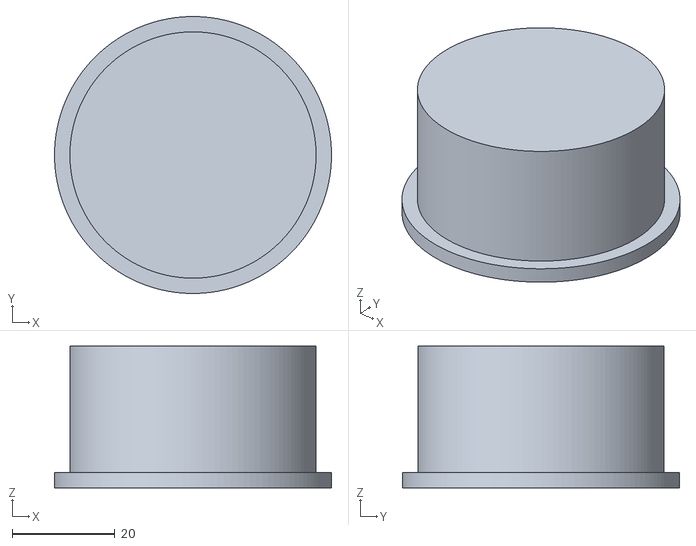
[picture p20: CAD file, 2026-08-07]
design/form/profile-study/cylinder.stl
54.0 x 54.0 x 27.6

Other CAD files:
design/form/profile-study/stepped.stl
design/form/profile-study/cone.stl
design/form/profile-study/shallow.stl
design/form/profile-study/waist.stl

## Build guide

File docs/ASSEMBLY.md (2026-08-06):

# Assembly sequence — First Chair

> ⚠️ Like the print guide, this is a **forward reference** for when the design is build-ready —
> not a green light. It's also the canonical **order** the 3D exploder should follow (the explode
> is grouped by these stages; refining it to step through them in order is tracked work).

Build **one earcup at a time**, then join the shared headband last. Part numbers + quantities are
in [`BOM.md`](../BOM.md); the part inventory is [`PARTS.md`](PARTS.md). Heat-set install bores are
sized for the inserts in the BOM — install them with a temperature-controlled soldering iron.

The order is chosen so nothing traps a part you still need to reach, and so every fastener threads
into a heat-set that's already seated:

## Stage 0 — Heat-set inserts (do all of them first)

Seat every brass insert before any screw goes in — you can't press an insert cleanly once parts
are stacked around it.

1. **M3** (Ruthex RX-M3x5.7) → the 4 baffle bosses (cup interior), the 3 driver-clamp standoffs
   (baffle back), and the 2 cup pivot bosses (cup side walls). 9 per ear.
2. **M5** (Ruthex RX-M5x9.5) → the fork boss (yoke), for the adjustment-post shoulder screw. 1 per ear.
3. **8-32** (Ruthex RX-8-32x4.7, short) → the slider thumbscrew boss. 1 per ear.

## Stage 1 — Driver into the baffle

The driver is captured between the baffle (front) and the clamp ring (back) — no glue.

4. Lay a **front-seal foam gasket** on the baffle's driver seat (the rim the driver frame lands on).
   It compresses ~33 % when clamped — that's the seal.
5. Drop the **driver** into the baffle's back recess (frame rim on the seat, dome firing forward
   through the guard). The locating collar keeps it centred.
6. Set the **driver-clamp ring** over the driver's back; its shoulder bears on the rear frame rim.
   Run **3× M3×6** (FMW 2170020) into the standoff heat-sets. Tighten evenly until the gasket seats.

## Stage 2 — Baffle + damping into the cup

7. Drop the **rear damping felt disc** (⌀38) into the cup's interior damping ring, over the grille.
   *(Closed-back variant: also press **vent plugs** into the tuning ports to taste — this is the
   reversible openness knob.)*
8. Lower the **baffle sub-assembly** into the cup front; align the 4 bolt holes to the baffle bosses.
   Run **4× M3×8** (FMW 2170021) from the front into the boss heat-sets. The heads sit under the pad.

## Stage 3 — Cup ↔ yoke pivot (the friction-tilt stack)

The cup hangs in the fork on one shoulder screw per side. The washer stack makes it a **friction
hinge** — the cup holds its tilt angle, no detent. Build the stack in this order, outside → in:

9. On the **pivot shoulder screw** (Accu 49844-SKH-M3-8-A2), thread on, in order:
   **`[ screw head | M3 wave washer | nylon flat washer | yoke eye | nylon flat washer | cup boss ]`**
   The wave washer is the preload; the nylon washers protect the printed PETG from the steel and add
   drag. The eye rides the **smooth Ø4 shoulder** (not the thread); the M3 thread takes the boss heat-set.
10. Tighten until the cup tilts with light friction and holds. Repeat for the other side. Free
    rotation otherwise (Grado-style — no over-rotation stop).

## Stage 4 — Adjustment post + slider (shoe goes in FIRST)

The captive shoe must be trapped in the slider **before** the post fills the bore — there's no way
to insert it afterward.

11. Drop the **pressure shoe** into the slider's side pocket (it sits in the wall, saddle facing the bore).
12. Thread the **adjustment post** (Mädler 619806050 shoulder screw) — M5 end — into the fork's M5
    heat-set. The Ø6 ground shoulder is the post; the head is the built-in **top stop**.
13. Slide the **slider** down onto the post (the shoe's saddle now cradles the post). The slider
    travels the post for height; the post also swivels in the bore for seal conform.
14. Run the **8-32 knurled knob** (Grand Brass SCK35) into the slider boss until its tip presses the
    **shoe** onto the post — that's the height lock. Never let the screw touch the post directly.

## Stage 5 — Headband (join both ears)

15. Drop each **bow** prong-tip into the recess in its slider's clamp lozenge; the slider's rib enters
    the bow's open channel (anti-rotation).
16. Set the **clamp cover plate** (`headband_clamp`) on the band's inner face; run **2× M3** through the
    prong-tip holes into the lozenge inserts. The band is now sandwiched.
17. Press/clip the **headband pad** onto the bow's underside at the crown.

## Stage 6 — Finish

18. Route the **cable** out each cup's bottom exit; solder to the driver tabs (observe polarity).
19. Stretch the **earpads** over the cup's outer rim; the elastic mount-ring hooks behind the lip.
20. Set height (slide), check tilt (friction holds), wear-test, then **measure** and feed real numbers
    back into `params.py`.

---

**Explode-tool note.** The 3D viewer groups parts by sub-assembly (earcup / earpad / gimbal /
headband / heads). Refining the explode to step through **these stages in order** (and to keep parts
in frame rather than flying them to infinity) is tracked in the build-readiness plan — the stages
above are the intended sequence.

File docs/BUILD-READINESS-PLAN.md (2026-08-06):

# First Chair — Build-Readiness Plan

Canonical plan for the push to a buildable prototype. Captures the 2026-06-27 readiness
assessment + the maker's decisions + the work plan. **Source of truth for this push — update
the checkboxes as items close.** (A fresh session can resume from here.)

## Readiness verdict (2026-06-27)

**~50% to true prototype-ready.** The CAD is sound *where the gate covers it* (16/16 build,
gate 0 HARD/0 SOFT, the pivot-bore bug caught + fixed); **what's left is mostly MEASUREMENT +
one real print, not redesign.** Weakest area: **acoustics (45/100)** — it's intention, not
geometry yet. Per-lens: printability 62, fit 52, acoustics 45, hardware/BOM 45.

## Maker decisions (2026-06-27)

- **Driver = Kingstate 40 mm.** Maker has several Kingstate 40 mm drivers, all ~same height.
  Supersedes the HPD-40N16 candidate. → set the driver family to Kingstate 40 mm; **measure exact
  OD / dome-proud / excursion / DCR / Fs-Qts when bench-testing** (params stay parametric).
- **Printer: not yet in hand.** Do NOT let print-verification BLOCK the work; do NOT drop it
  either. When the printer arrives the maker will ask what to print first (answer: the two
  coupons, then one cup). Keep all print-verify items flagged, not gating.
- **Pads: DEFAULT = Beyerdynamic** (maker has them now). **Dekoni = premium alternative + a
  tuning option** (incoming). `cup_outer_diameter` (91.44) back-solves from the pad cup-mount
  skirt Ø → **MEASURE the Beyer pad** (skirt/tension-ring ID + pad depth) and set MEASURED.
  Maker offered to caliper them — take him up on it.
- **Headband / fit (the worn-fit fix):** add **THREE reference heads (S / M / L)** to the viewer
  to compare how the band lands; make the **bow simulate SPRING STEEL** — flex/compress per head
  (conserve developed length) so the clamp adjustment is *visible*; tie the slider travel so
  **FULL EXTENSION = the LARGEST head**. Reconsider the ~30 mm post range in that light (if the
  cup/post can raise in the slider, the usable range shrinks — size it to S↔L head span, not a
  guessed 30 mm).
- **Fasteners: pin real SKUs + part numbers + lengths now** (BOM gets a part-number column).

## Blockers to a first prototype (maker-gated — tracked, not all doable now)

1. **Lock the driver** — Kingstate 40 mm; measure OD/dome/excursion/Fs-Qts when in hand.
2. **Print the coupons** (`driver_coupon`, `pad_coupon`) — *when the printer arrives*. Converts
   slip/friction/heat-set/pad-grip clearances ESTIMATE→MEASURED. Highest-leverage single action.
3. ~~Measure the Beyer pad~~ **RESOLVED from published dims** (no caliper needed): Beyer DT770/880/990
   = Dekoni/Brainwavz interchangeable, **elastic stretch-ring mount** → pad **OD 100, opening ~58,
   depth ~22–25 mm**. The ring stretches over ~88–95 mm, so **`cup_outer_diameter` 91.44 is fine as-is
   — keep it** (REF it, no longer a back-solve blocker). Only change: set the pad mockup **depth ~24 mm**
   (front-cavity acoustics) — fold into the acoustic-geometry task. (Optional later: caliper the cup-rim
   snug fit; not gating.)
4. **Fix the worn headband fit** (band floats ~35 mm above the crown) — via the head-models +
   sprung-bow + slider-range work below.
5. **Pin fastener SKUs** — doing now.

## Work plan — proceed NOW (no parts needed)

Ordered; tick as done. Each = build→gate→log→commit→push, sync promote until v1.0.

- [x] **1. Fastener SKUs + part numbers** — DONE (16c1b10). `bom.py` rewritten with a linked
  **Part #** column + flags; every number read off a live supplier page (no invented McMaster
  numbers). Post=Mädler 619806050, pivot=Accu 49844-SKH-M3-8-A2, knob=Grand Brass SCK35,
  bow=Beyer 917017/973361, heat-sets=Ruthex RX-M3x5.7/M5x9.5/8-32x4.7, SHCS=FMW 2170021/2170020,
  wave=BelMetric WW3BSS, nylon=Accu HPW-3-2-7-0-5-N, cable=Parts Express 240-1032. Fit fixes:
  8-32 bore 5.0→5.6; 5⁄8″ all-metal knob is non-stock (½″ SCK35, flagged). Driver→Kingstate,
  pads→Beyer default.
- [x] **2. Close gate gaps** — DONE. Added `slider_shoe`, `headband_clamp`, `driver_coupon`,
  `pad_coupon` to the manifold loop (all 1 valid solid). Added 3 shoe checks
  (`shoe-saddle-reaches-post`, `shoe-saddle-cradles-post`, `shoe-fits-pocket`). guard-dome stays
  SOFT — precondition sharpened to `driver_dome_excursion` measured (the one remaining estimate).
  Gate covers 12 parts + shoe interface, 0 HARD / 0 SOFT.
- [x] **3. Stale-doc sweep + AUTO-UPDATE.** DONE. Fixed active-code comments (Ø8→Ø6 in slider_shoe.py
  + params; M4/4-40→8-32 in hardware.py/slider.py/assembly.py). `print-guide.md`: removed the
  over-rotation stop, build-count→"all green (see PARTS.md)", M3→M3/M5/8-32 inserts, dead SOFT ref
  → driver-excursion note, +orientation rows for the new parts. Template docs '8/8'→'N/N'.
  **Auto-gen:** new `gen_parts_doc()` in build.py writes `docs/PARTS.md` (live inventory + 16/16 count,
  derived from the part dicts) alongside the already-auto-gen BOM.md. Website spec + local design-spec:
  corrected the actively-wrong facts (90→**143 cc**, pads→Beyer default) + an honest status note.
  **Parked:** a FULL website/local design-spec architecture refresh (it still describes the old
  spring-steel-arc/old-pivot architecture) — do after items 4-5 settle acoustics + headband, so it's
  rewritten once. (DESIGN-LOG could one day be auto-summarized too, but it's append-only history.)
- [x] **4. Acoustic geometry as params + shown in model.** DONE. `cup_open_back` toggle (open grille /
  solid back + pluggable tuning ports — closed-back verified to build as 1 solid). New `parts/vent_plug.py`
  (reversible openness knob). Damping retaining ring (felt-disc seat) in the cup. Dimensioned front-seal
  gasket + HARD `front-seal-squeeze` check (30–50 %). Acoustic-volume helpers fix the 143 cc IN CODE
  (`cup_interior_volume_cc` 143.4, `front_cavity_volume_cc` 67.9). `earpad_depth 24` (pad mockup
  Z-scaled). New gate checks `front-seal-squeeze` + `closed-back-ports-clear`; vent_plug in manifold.
  Build 17/17, gate 0/0. Parked: gasket/damping in the assembly VIZ; real vent open-area vs a REW sweep.
- [~] **5. Head models S/M/L + sprung bow + slider range.** DONE: three toggleable reference heads
  (S/M/L, uniform-scaled, ears aligned; `head_ref_s/m/l` — 3 viewer toggles, off by default); sprung-bow
  helper `bow_radius_for_ear_half` (conserves developed length, `bow_worn_radius_s/l`); viewer/render
  renames handled. Build 17/17, gate 0/0. **REMAINING (the actual blocker fix, scoped follow-up):** the
  bow apex floats ~34 mm above the crown and that exceeds the 32 mm slider travel — the yoke+post stack is
  ~2 cm too TALL. Trim `yoke_fork_height`/post ~20 mm + map slider travel S↔L (full extension = largest)
  so the band lands. The 3 heads now make the gap visible to calibrate against. (Its own careful pass —
  ripples through yoke geometry + gate + renders.)
- [~] **6. Assembly sequence + explode refinement.** DONE: wrote **`docs/ASSEMBLY.md`** — the full
  ordered build (Stage 0 heat-sets → driver+gasket+clamp → baffle+damping into cup → pivot
  **washer-stack** `[head|wave|nylon|eye|nylon|boss]` → shoe-before-post → post/slider/knob → band
  sandwich → finish), grounded in the real interfaces + BOM part numbers, and named as the explode's
  intended step order. **REMAINING (viz polish, scoped):** (a) draw the pivot washer stack in the
  assembly render (currently insert+screw only — "a manual nicety", DESIGN-LOG); (b) refine the
  explode tool to step through the ASSEMBLY.md stages in order + clamp offsets so parts stay in frame
  (the doc now defines the order to follow). Both iterative "as we go" per the maker.

## Parking lot (revisit)

- **Worn-fit RE-POSE (head-driven, per head) — the next focused build.** Head + ears DONE (live);
  the fit is diagnosed (see DESIGN-LOG 2026-06-28): earpad buried ~24 mm (modeled uncompressed +
  bow-driven cup spacing too narrow), band doesn't flex (vertical-only auto-fit). FIX: re-derive the
  worn pose head-driven — head ear → compressed worn-earpad (~12 mm) flush → cup position → bow flexes
  (`bow_radius_for_ear_half`) to span → band height to crown; per head; then the viewer re-poses on
  selection (swap a pre-flexed bow + per-head transforms, or per-head GLBs). Also: optionally make the
  KU100 face a touch more defined; the current nose/brow are subtle.

- ~~Worn-fit STACK TRIM~~ **BAND-FLOAT RESOLVED 2026-06-27 — it was the head model + pose, not the
  stack.** The ovoid had the ear at its centre (ear→crown 114, ~15 mm short) and the slider was posed
  mid-travel. Fixed: `head_ref_height_half 121` + `head_ref_z 8` (ear→crown 129, S/M/L 123/129/135) and
  `assembly_worn_slider_frac 0.9` (near-retracted = average head; big cup forces the block high). The
  stock 9.3″ Beyer bow now LANDS (pad contacts the M crown). Stack trim NOT needed. *Optional minor
  polish remaining:* the post travel is biased to the retracted end (average ≈ near-retracted) — a small
  post/fork trim could centre it so M sits mid-travel, but it's cosmetic, not a blocker.
- **Assembly viz polish** — (a) draw the pivot washer stack `[head|wave|nylon|eye|nylon|boss]` in the
  render (assembly.py currently shows insert+screw only); (b) refine the explode tool to step through
  the `ASSEMBLY.md` stages in order and clamp the per-part offsets so nothing flies out of frame.
- **Full design-spec refresh (website `.mdx` + local `design-spec.md`)** — both still describe the
  pre-bow "spring-steel-arc" architecture, the old pivot, Dekoni-default pads. Item 3 fixed only the
  actively-wrong facts (143 cc, pad default) + a status note. Do the full v0.4 reconciliation AFTER
  items 4-5 land (acoustics + headband), so it's rewritten once, not three times.
- Print-verify everything (printer pending) — coupons first, then one full cup + a baseline REW sweep.
- Kingstate driver specs — measure when bench-testing.
- Dekoni pads — incoming; premium/tuning alternative.
- After v1.0 lock: stop the beta↔current auto-sync (see `website-publish-channels` memory).

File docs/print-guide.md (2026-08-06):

# Print guide — First Chair (DRAFT — NOT print-ready)

> ⚠️ **The First Chair is not ready to print or assemble.** All parts *build*
> green (see `PARTS.md`) and pass the *printability* linter (0 HARD), but that's a low bar — the
> DESIGN still needs significant work before a print-and-assemble: measurements,
> fit, acoustics, mechanism detail, the soft yoke, the headband pad, and the
> tweaks the maker is carrying (see "What's still open" below + the DESIGN-LOG).
> This file is a **forward reference** for when it gets there, not a green light.

When the design IS ready, this is the how-to-print layer — orientation, supports,
material, and order. Even the earliest useful step (a baffle to check a driver) is
gated on settling more than is settled today.

> STLs export to `output/` (gitignored) via `python build.py`; they ship to builders
> through tagged GitHub Releases, not the tree. STEP is exported alongside for
> editing elsewhere.

## Print the BAFFLE first (against a real driver)

Per the build's golden rule: **print the baffle alone, first, and seat your actual
driver in it** before committing to the rest. It's flat and fast, and it validates
`driver_od` / aperture / recess — the cheapest way to catch the #1 first-print risk.

## Baseline settings (tune to your printer)

| Setting | Start at | Why |
|---|---|---|
| Material | **PETG** (cups/yoke/slider), **TPU** (headband pad) | PETG = tough + a little flex for the snap/lip; TPU for the cushion |
| Layer height | 0.2 mm (0.16 for the grille/flange) | finer on thin features |
| Walls / perimeters | 4 (≥ the 3 mm design wall) | strength; the structural floor is 4 mm |
| Infill | 30–40 % gyroid | cups/yoke see real load |
| Inserts | M3 / M5 / 8-32 brass heat-set | bores are sized for them — install with a soldering iron (exact part #s in `BOM.md`) |

## Per-part orientation + supports

| Part | Orient | Supports | Notes |
|---|---|---|---|
| **baffle** | flat, **back face down** | none | guard spokes bridge fine; counterbores face up (heads hide under the pad) |
| **cup** | **back/grille down**, axis vertical | **yes** — the 2 pivot bosses (radial overhangs) + a touch under the front flange | brim on a brim if the grille lifts; the rounded back edge prints clean on the bed |
| **yoke** | **flat in its plane** (bracket lying on the bed) | minimal (under the eyes if needed) | flat bracket = easy print. **Post-process:** the cross-section edges are square (kernel can't round them yet) — a quick sand softens them, or wait for the build123d port |
| **slider** | **post-bore axis vertical**, lozenge + thumbscrew boss facing sideways | light, in the post-bore mouth | rounded lozenge, mostly self-supporting; the shoe pocket + 8-32 boss bore print across the +Y face |
| **slider_shoe** | **saddle axis vertical** (concave face sideways) | none | tiny — print a few spares; drops into the slider pocket through the bore |
| **driver_clamp** | flat, ring face down | none | 3 ears; the M3 clamp holes + standoff bosses face up |
| **headband_clamp** | flat, plate face down | none | small inner cover; the rib slot faces up |
| **grille_dot** | flat, proud face up | none | press-in accent cap |
| **headband_pad** | arch on its side or flat | light at the arch ends | **TPU**; rough draft — expect to iterate |
| **adapter_ring** | flat | none | accessory (only if stepping a smaller driver) |
| **driver_coupon / pad_coupon** | as the part each validates (baffle-back / cup front down) | as that part | **QA fit coupons** — print these *first* against your real driver + pad |
| **bow** | — | — | **NOT printed** — bought Beyer metal bow (917017/973361) or a DIY laser-cut/water-jet 1095 spring-steel blank to the modelled geometry |

## First-prototype order

1. **Baffle** + seat the real driver → confirm `driver_od`, aperture, recess. Measure.
2. **Cup** (one) → check the pivot bosses, the grille, and that your **earpad's mount
   skirt** actually grips the front flange. Measure the pad mount Ø → set
   `cup_outer_diameter`. (This is the Tier-1 number that moves everything.)
3. **Yoke + slider + hardware** → dry-fit the pivot (M3 shoulder screw + inserts) and
   the **free tilt range** (Grado-style — no over-rotation stop), and the post + 8-32
   knob → shoe height lock.
4. **Bow** (bought/cut) → measure relaxed radius + rolled-out length → set the bow
   params; check ear spacing on a head.
5. Re-build with the measured numbers → re-gate → reprint the parts that moved.

## Post-processing checklist

- [ ] Heat-set inserts: **M3** (cup pivot + baffle + driver-clamp bosses), **M5** (fork → post
      shoulder screw), **8-32** (slider knob). Part #s in `BOM.md`.
- [ ] Sand the yoke edges if you want the soft feel now (kernel limitation logged).
- [ ] Light chamfer/clean on the earpad flange so the skirt slips on.
- [ ] Note every real measurement back into `params.py` (overwrites the ESTIMATE),
      then **rebuild → gate → DESIGN-LOG → commit → push**.

## What's still open (why this isn't print-ready)

A design in progress, not a finished product. Known work before a real
print-and-assemble — and the maker is carrying more:

- **Measurements** — pad mount Ø (→ cup OD), bow geometry (→ fit), driver OD: all
  still `ESTIMATE`/`TBD`.
- **Earpad lip** — extension/thickness provisional (5 mm reaches ⌀100 = pad foam);
  resize once the real pad groove is measured.
- **Fit** — worn ear spacing / clamp / tilt unverified on a head.
- **Acoustics** — driver choice (40 vs 50), damping, vent open-area: nothing tuned
  or measured.
- **Yoke** — stays a flat bracket; the soft round version waits on the build123d port.
- **Headband pad** — explicitly a rough draft.
- **Mechanism detail** — slider bolt-on + bow end-tab hole specs need calipers + a
  real hardware fit.
- **Driver dome excursion** — still an `ESTIMATE`; the guard↔dome clearance gate check stays
  SOFT until it's measured on the real Kingstate driver (then it promotes to HARD).
- **…and the maker's tweak list** — the items that prompted this note.

See `measurement-priorities.md` for the measurement order once we're closer.

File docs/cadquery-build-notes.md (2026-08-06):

# CadQuery / OCC build notes — what this kernel can and can't do

The Daily Driver CAD runs on a CadQuery + OCP/OCC build whose **boolean and
finishing operations are fragile**. This file is the hard-won map of what works,
so future parts (and future headphones) don't re-discover it the slow way. If a
fillet "doesn't show up" or a part comes out as several invalid solids, it is
almost always one of the limits below — not a logic bug in the part.

## The one rule that matters most

**Round (fillet/chamfer) on CLEAN geometry, BEFORE you cut pockets/bores.**

`.fillet()` and `.chamfer()` raise `Standard_Failure: BRep_API: command not done`
on any solid that already has pockets, bores, or unioned features. They succeed on
a fresh primitive (a plain box, a clean disc) or a single isolated edge.

```python
# WORKS — round the box, then cut into it
slider = cq.Workplane("XY").box(w, d, h).edges().fillet(2.5)
slider = slider.cut(pocket).cut(bore)        # cuts after the fillet are fine

# FAILS — cut first, then try to round
slider = cq.Workplane("XY").box(w, d, h).cut(pocket)
slider = slider.edges("|Z").fillet(2.5)      # BRep_API: command not done
```

## What works / what fails (measured 2026-06-25)

| Operation | Status | Notes |
|---|---|---|
| `.fillet()` on a clean box/disc | ✅ | any/all edges |
| `.fillet()` after a cut/pocket | ❌ | `BRep_API: command not done` |
| `.chamfer()` after a cut | ❌ | same failure as fillet |
| `.fillet()` on one isolated outer edge of a complex part | ⚠️ | sometimes (cup front rim `>Z` worked; cup back `<Z` failed) — test it |
| `revolve` | ❌ | unusable — build arcs from extruded annular sectors or fans of cylinders (see `parts/bow.py`, the yoke stop slot) |
| `sweep` a profile along a path | ✅ | **but** `moveTo(start)` the path first — a bare `.spline(pts)` runs from the origin and mis-places the result |
| union of a FEW clean solids | ✅ | |
| `combine()` / union of MANY solids (~30+) | ❌ | fragments into invalid pieces; unioning rounded arms + eyes/hub then cutting bores also fails |
| extrude / cut / simple union | ✅ | the dependable core |

## Workarounds, in order of preference

1. **Round before cut.** Fillet the blank/primitive, then cut features into it.
2. **Sketch-level (2D) rounding.** Build a rounded profile and extrude it, instead
   of filleting the 3D solid.
3. **Annular sectors / cylinder fans** for arcs (revolve substitute).
4. **Chamfer** where a fillet won't take and the edge is exposed/clean.
5. **Perpendicular-section LOFT for a smooth swept form.** (SUPERSEDES the old "yoke
   stays a flat bar" note.) The wraparound yoke arm is now a single
   `cq.Solid.makeLoft(wires, ruled=False)` through rounded-rectangle sections placed
   perpendicular to the path tangent — a continuous organic tube, ROUNDED with no sharp
   edges along it, in pure cadquery. The key: build each section's rounded-rect wire BY
   HAND (4 line segments + 4 tangent `threePointArc` corners), NOT with `Sketch().fillet()`
   (fillet2D is unreliable on complex faces here). Loft the arm first; union eyes/hub/post
   with each end overlapping DEEP (a tangent kiss → two disjoint solids); cut bores/slots
   LAST. This rounds the form WITHOUT a 3D fillet and WITHOUT the build123d port. (The
   earlier failures — incremental union, `combine()`, swept circle fused with eyes/hub +
   bores — were all trying to round AFTER assembly; lofting the smooth section up front
   sidesteps it. See parts/yoke.py.)

## How to probe quickly

Before committing to a finishing approach on a new part, trial it in isolation and
check `len(v.Solids()) == 1 and v.isValid()`:

```python
def trial(name, fn):
    try:
        v = fn().val()
        print(name, len(v.Solids()), v.isValid())
    except Exception as e:
        print(name, "FAIL", str(e)[:60])
```

A part that builds as `1 solid, valid=True` is sound; `>1 solids` or `valid=False`
means a boolean fragmented — back off to a simpler construction.

## build123d evaluation (2026-06-25) — the path off these limits

Spiked `build123d` 0.11 in an isolated venv to see if it dodges the limits above.
It rides the **same OCCT kernel**, so it is not a magic wand — but it handles the
geometry that fragments cadquery here:

| Test (the cadquery pain points) | cadquery/OCC | build123d |
|---|---|---|
| Small fillet (r ≤ 0.8) after a pocket cut | ❌ any radius (`BRep_API`) | ✅ works |
| Larger fillet (r ≥ 1.5) after a cut | ❌ | ❌ but errors clearly ("try a smaller value") |
| `sweep` a circle along the wrap arc | ⚠️ mis-places the profile | ✅ clean, 1 solid |
| **Full round-tube yoke** — 2 swept tubes + 2 eyes + hub fused, then a bore cut | ❌ **fragments to invalid solids** | ✅ **1 valid solid, 0.7 s** |

**Verdict:** build123d builds the rounded yoke that this cadquery/OCC build can't,
its `sweep` works, and its errors are actionable. It's the realistic path to (a) the
**soft round-section yoke** and (b) fewer boolean surprises generally.

**Recommendation — a planned port, not a mid-stream scramble.** `params.py` (the
single source of truth) stays; the work is porting the part builders + `build.py`,
`gate.py`, `assembly.py` from the cadquery API to build123d's. Do it as a dedicated
effort (good moment: alongside the product-template/platform work, or sooner if the
rounded yoke jumps the queue). Until then **product #1's yoke stays the flat
bracket** — already shipped and gate-clean. Don't half-migrate one part into the
cadquery pipeline; the APIs don't mix cleanly.

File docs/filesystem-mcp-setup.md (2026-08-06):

# Filesystem MCP — chat-side read access to this repo

**Status: config + groundwork only. Nothing is enabled by this repo.** The last
step (adding the connector) is a manual one you take in the Claude app — see
[What you do to enable it](#what-you-do-to-enable-it).

## Why

The GitHub MCP connector is platform-blocked on this account, so chat-side review
can't read the repo through GitHub. Instead we run the official local
**filesystem** MCP server, scoped to `~/Projects`, so a review session can read
the *live* working tree directly. Chat-side is for **review**; the writes still
happen here in Claude Code.

## Where the repo lives (no move needed)

`daily-driver` is its own standalone git repo, nested inside the website repo at:

```
~/Projects/makerphones/builds/daily-driver        ← canonical path
```

It is gitignored by the parent `makerphones` repo (see `makerphones/.gitignore`,
"hardware build repos"), so it is **already under `~/Projects`** — a server scoped
to `~/Projects` reaches it without moving anything. For convenience there is also
a top-level alias symlink so it shows up as a first-class project:

```
~/Projects/daily-driver -> makerphones/builds/daily-driver   (symlink, resolves within ~/Projects)
```

No files were moved and no paths changed (there are no absolute paths baked into
the repo — verified with `git grep`). You can delete the symlink with
`rm ~/Projects/daily-driver` at any time; the canonical nested path still works.

## The config

Scoped to `~/Projects` **only** (not `$HOME`). Note this exposes *every* project
under `~/Projects` to chat-side review (read-only), not just daily-driver — that's
the intended scope.

```json
{
  "mcpServers": {
    "projects-fs": {
      "command": "npx",
      "args": [
        "-y",
        "@modelcontextprotocol/server-filesystem",
        "/Users/jameywarren/Projects"
      ]
    }
  }
}
```

Pin the version if you want reproducibility:
`"@modelcontextprotocol/server-filesystem@2026.1.14"` (latest at time of writing).

## Read-only — the honest mechanism

The official `@modelcontextprotocol/server-filesystem` has **no `--readonly`
flag**. Its directories are positional arguments, and it always registers write
tools (`write_file`, `edit_file`, `create_directory`, `move_file`) alongside the
read tools. The `readOnly` strings in its source are only advisory
`readOnlyHint` *annotations* on individual tools, not an access mode.

So read-only is enforced **on the client side, by denying the write tools** — not
by the server. After adding the connector, allow only the read tools and deny the
writes:

- **Allow (read):** `read_file`, `read_text_file`, `read_media_file`,
  `list_directory`, `list_directory_with_sizes`, `directory_tree`,
  `search_files`, `get_file_info`, `list_allowed_directories`
- **Deny (write):** `write_file`, `edit_file`, `create_directory`, `move_file`

In Claude Code this is a permissions entry, e.g. in `.claude/settings.json`:

```json
{
  "permissions": {
    "deny": [
      "mcp__projects-fs__write_file",
      "mcp__projects-fs__edit_file",
      "mcp__projects-fs__create_directory",
      "mcp__projects-fs__move_file"
    ]
  }
}
```

In the Claude desktop app, toggle the individual tools off for this connector (or
simply decline any write-tool prompt).

### Switching to read-write later

If you later want chat-side to write too, **remove the deny entries** above (or
re-enable the write tools in the connector's tool list). The server itself needs
no change — it's read-write by default; the lockdown is entirely the client
allow/deny list.

## What you do to enable it

This repo does **not** enable anything. To turn it on (macOS, Claude desktop app):

1. Open the Claude app → **Settings → Developer → Edit Config**. That opens
   `~/Library/Application Support/Claude/claude_desktop_config.json` (create the
   file with `{}` if it doesn't exist yet).
2. Merge the `mcpServers` block above into it (keep any servers already there).
3. **Quit and reopen** the Claude app so it spawns the server.
4. Apply the read-only lockdown (deny the four write tools) as above.
5. In a chat, confirm it's live: ask it to list `~/Projects` — you should see the
   sibling projects and `daily-driver`. The first call may take a few seconds
   while `npx` fetches the server package.

Alternative (Claude Code CLI instead of the desktop app):

```bash
claude mcp add projects-fs -- npx -y @modelcontextprotocol/server-filesystem /Users/jameywarren/Projects
```

then add the same `deny` list to your settings.

### What to expect once it's live

- A new toolset `mcp__projects-fs__*` (read tools only, after the lockdown).
- Read access to the whole of `~/Projects`, including the live daily-driver tree
  at `~/Projects/daily-driver` (or `~/Projects/makerphones/builds/daily-driver`).
- No write ability from chat (by the deny list) — review reads; Claude Code writes.
- Reads reflect the working tree *as saved on disk*, including uncommitted changes.

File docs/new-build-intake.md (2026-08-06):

# New headphone intake → brief → build

The Daily Driver is product #1. This is the repeatable pipeline for starting the
next one without a blank page: a structured **intake** that produces a **brief**,
which seeds a parametric **build** you iterate on. The intake captures exactly the
decisions that ended up driving `params.py` and the styling passes for the Daily
Driver — so it's grounded in what actually mattered, not a generic survey.

Run it interactively with the **`/headphone-intake`** skill (it asks the questions
below and writes a `BRIEF.md`), or fill the template by hand.

## The pipeline

```
INTAKE  →  BRIEF.md  →  params.py + parts/  →  build.py → gate.py → DESIGN-LOG  →  iterate  →  release
(ask)      (decisions)   (single source)        (N/N)      (0 HARD)   (one entry)    (re-measure)  (tag)
```

- **Intake**: answer the questionnaire; gather reference photos + any measurements.
  Unknowns are fine — mark them `TBD` / `ESTIMATE`, don't invent numbers.
- **Brief**: the frozen-enough set of decisions + targets. Lives in the build dir.
- **Build**: translate the brief into `params.py` values (the single source of
  truth) and any new part geometry. Reuse the Daily Driver skeleton + ritual.
- **Gate every change**: `python build.py` (N/N) then `python gate.py` (0 HARD).
- **Log + commit + push** every real decision/iteration (newest DESIGN-LOG entry
  on top; one commit per task; **always push**).
- **Iterate on real parts**: measurements from printed parts / the actual pad/bow
  overwrite ESTIMATEs cleanly → rebuild → gate → log.

See `cadquery-build-notes.md` for the kernel limits (round before cut, etc.) before
you reach for fillets, and `design-pipeline.md` for the taste-vs-convention boundary.

## The questionnaire (what a brief must answer)

Each block maps to params/decisions. Capture the answer **and** its confidence
(`MEASURED` / `ESTIMATE` / `TBD`).

1. **Use-case & vibe** — open- or closed-back? studio / commute / desk / gaming?
   The feel: soft & rounded vs. angular & technical? Reference headphones/images.
2. **Driver** — size (e.g. 40/50 mm), impedance, model or "generic class". Aperture
   and recess derive from `driver_od`, so this sets the baffle family.
3. **Earpad** — brand/model + the four numbers: outer Ø, ear-opening ID, **mounting
   skirt Ø** (what the cup lip wraps — NOT the ear opening), and depth. Drives the
   cup OD and the retaining lip. (Daily Driver: Dekoni Universal 100 mm.)
4. **Headband / bow** — bought spring band (e.g. Beyer metal bow) or DIY blank?
   Relaxed radius, developed (rolled-out) length, width, end-tab hole pattern. The
   band flexes; the worn radius sets ear spacing.
5. **Cup–yoke–slider mechanism** — pivot + swivel gimbal? How does the band attach
   to the slider — **bolt-on at end tabs** or telescoping clamp? (Daily Driver:
   bolt-on, screws on the inside face.)
6. **Fit** — target head width / ear spacing, clamp feel, tilt range.
7. **Aesthetic** — grille pattern + open-area target, accent color, edge treatment
   (roundovers vs chamfers — within the kernel's limits), any signature mark.
8. **Constraints** — print bed size, material (PLA/PETG/ABS/TPU pads?), hardware
   you'll stock (M3 inserts/screws), license, budget per unit.
9. **Prior-art boundary** — list reference designs studied; note their licenses.
   Credit adopted ideas in DESIGN-LOG; **never copy files/geometry** from
   non-permissively-licensed projects.

## BRIEF.md template

```markdown
# <Headphone name> — design brief
Status: DRAFT · <date>

## 1. Use-case & vibe
- ...
- References: <links / image filenames>

## 2. Driver
- Size / impedance / model: <…>  [MEASURED|ESTIMATE|TBD]

## 3. Earpad
- Model: <…>
- Outer Ø: <…> | Ear ID: <…> | Mount skirt Ø: <…> | Depth: <…>  [confidence each]

## 4. Headband / bow
- Type: <bought | DIY>  | Relaxed R: <…> | Developed length: <…> | Width: <…>
- End-tab holes: <count / pitch>  [confidence each]

## 5. Mechanism
- Cup pivot / swivel: <…>
- Band ↔ slider attach: <bolt-on | clamp>, screws on <inside|outside>

## 6. Fit
- Ear spacing target: <…> | Tilt range: <…> | Clamp: <…>

## 7. Aesthetic
- Grille: <pattern>, open-area target <…>
- Accent: <…> | Edge treatment: <…> | Signature: <…>

## 8. Constraints
- Bed: <…> | Material: <…> | Hardware: <…> | License: <…> | Target cost: <…>

## 9. Prior-art studied (look-don't-copy)
- <project> — <license> — <idea adopted, credited in DESIGN-LOG>

## Open questions / next measurements
- [ ] <…>
```

## Turning a brief into a build

- New cup OD / pad → set `cup_outer_diameter`, `pad_lip_*`; the lip + pivot bosses
  + yoke regenerate.
- New driver → `driver_od`; aperture/recess/guard derive.
- New bow → `bow_radius`, `bow_developed_length`, `bow_width`, `bow_worn_radius`.
- Styling → grille params, accents, edge treatments (mind the kernel limits).
- Everything flows from `params.py`; parts stay independently buildable.

## Bigger picture (not built yet)

A public intake **form on makerphones.com** that collects design suggestions is the
natural extension. Caveat: an LLM-backed form burns API credits per submission, so
prove the value with this here-only `/headphone-intake` skill first, then decide
between (a) a plain structured web form that emails a brief draft, and (b) a
hosted assistant. Start cheap.

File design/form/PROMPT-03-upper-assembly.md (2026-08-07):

Follow-on to the yoke pass. **The whole upper assembly is wrong** — the bow, the slider, and how they join. That's my fault, not yours: I gave you a parts list and never gave you the mechanism, so you invented one. Here it is properly. Design the three together, because they only make sense together.

## 1. The bow — a bought part, measured, not a variable

It's a Beyerdynamic DT-family sprung steel head bow. We buy it. Every number here is measured off the real part:

```
relaxed arc radius        63.5      (a 5 inch circle)
flexed on a head          ~78       this is the radius that sets ear spacing
developed length         236.2      rolled flat
strap width               33.0
strap thickness            0.8
```

The central ~110 mm carries an X-brace cut-out pattern. Each end runs out into **two flat prongs about 7 mm wide** over roughly the last 28 mm, and **each prong has a Ø3.2 hole about 5 mm in from its tip. The two holes are 26.0 mm apart.**

Both your studies have this wrong, and they don't agree with each other:

- the four-directions study: `BOW = { R: 98, t: 1.1, w: 13 }`
- the family study: `BOW_R = 108`

**The width matters most.** 13 mm reads as a wire; the real part is a 33 mm strap, and it looks and behaves completely differently. The radius being 98 or 108 instead of ~78 worn puts the cups in the wrong place relative to the head. Since the bow is the one component genuinely identical across all four products, getting it right is what makes the family study trustworthy.

## 2. How the bow attaches — settled, and simpler than what you drew

**Two M3 screws straight through the bow's own end-tab holes**, into heat-set inserts in the slider. That's it.

No clamp sandwich, no cover plate, no recess the prongs drop into, no captured band. You drew a clamp block that grips the strap; delete it. The bow was manufactured with mounting holes and is designed to be screwed — we use the holes it already has, at their 26 mm pitch.

This is the one joint in the build where we deliberately spend fasteners, because it's the only one carrying sustained spring load. Everywhere else, a screw has to justify itself.

## 3. The slider — this is the part to actually design

**A printed cantilever leaf with a detent bump, riding a notch ladder.** Height adjustment clicks from notch to notch.

**It deletes the thumbscrew, the brass insert and the pressure shoe in one move — that deletion is the whole point.** You drew a knurled brass thumbscrew clamping a printed leg with a smooth travel slot. That's a friction lock, it's what our over-ear does, and replacing it is a deliberate decision, not an oversight. There is no thumbscrew on this product.

Four things that constrain it:

- **The leaf must bend in the print plane, with the layer lines running along the leaf.** Same rule as the yoke, same reason: printed flat, it bends exactly across the layer boundaries where adhesion is weakest and it snaps early.
- **It has to print support-free.** If a form needs supports, it's out.
- **It tunes by leaf thickness.** That's the adjustment knob, and we're settling the actual number by printing a physical coupon — one rail, five sleeves at graduated leaf thickness — and picking by feel. So don't agonise over the exact spring dimension; get the architecture right and leave thickness as the parameter.
- **The rail is rectangular, so the slider can't rotate in its sleeve.** This is why both rotational axes have to be real designed joints out at the yoke, and it's a large part of why the yoke is crowded. The two prompts connect here. If you think a round rail is better — returning swivel to the slider for free, at the cost of letting the cup twist under load — say so and make the argument.

This part has less prior art than anything else in the build. Printed detents that still hold after a few hundred adjustments are not a solved problem, and I'd rather see the difficulty than have it styled over.

## What I want back

**The rules in words first**, then the upper assembly as one designed thing across the family — bow, slider, attachment, and how the yoke hangs off it.

Show me at least two ways to arrange the detent ladder and leaf (where the ladder lives, which part carries the leaf, which way the leaf faces) with the trade-offs stated, rather than one resolved answer.

And keep doing the thing you did well last time: **if something doesn't close, say so.** The stated conflicts in your first pass were the most useful part of it. If the detent can't produce enough holding force at this scale against a real bow's spring load, that's exactly what I need to hear.

## Unchanged

1 unit = 1 mm. GLB, never OBJ. Same mesh naming — `slider_R`/`_L`, `yoke_R`/`_L`, `bow_ref`, and no `thumbscrew_*` or pressure-shoe nodes any more, because those parts stop existing.

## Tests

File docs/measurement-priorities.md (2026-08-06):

# Measurement priorities — what to measure, when, and why

The design churns when measurements arrive out of order or get re-taken. This is
the ranked list of open measurements: **Tier 1 blocks the first print**, Tier 2 can
wait for the second print / acoustic loop. Each one says which param it sets, the
risk if it's wrong, and how to capture it. Measure Tier 1 with calipers + a photo
(scale reference in frame) before printing anything load-bearing.

> Rule of thumb: if a part **regenerates from** the number, it's Tier 1. If the
> number only **tunes** a part, it's Tier 2.

## Tier 1 — measure before the first print

| # | Measurement | Sets (param) | Risk if wrong | How |
|---|---|---|---|---|
| 1 | **Earpad cup-mount skirt Ø** (the diameter the pad's inner skirt stretches over — NOT the 60 mm ear hole, NOT the 100 mm foam OD) | `cup_outer_diameter` → cascades to lip, pivot bosses, `yoke_pivot_centres`, ear spacing | Pad won't seat, or the whole cup is the wrong size and everything downstream regenerates wrong | Turn the Dekoni pad inside-out; caliper the mounting opening / groove ID. Photo top-down with a ruler. |
| 2 | **Bow relaxed radius** + **developed (rolled-out) length** | `bow_radius`, `bow_developed_length` → ear spacing, slider height, arc angle | Wrong ear spacing → fit is off; worn-pose geometry wrong | Roll the bow across a ruler (length); lay it on paper, trace the arc, R = chord/sagitta or fit a circle. Photo with ruler. |
| 3 | **Driver OD** (40 / 42 / 50 mm class) + frame depth | `driver_od` → aperture, recess, guard all derive | Driver won't drop into the baffle recess; aperture wrong | Caliper the frame OD and the seat-flange depth. |

These three are the spine: pad → cup size, bow → fit, driver → baffle. Lock them
and most of `params.py` regenerates coherently.

## Tier 2 — measure before the second print or the REW/acoustic loop

| Measurement | Tunes (param) | How |
|---|---|---|
| Pad flange/groove depth + skirt thickness | `pad_lip_extension`, `pad_lip_thickness` (how far the lip sticks out / how thin) | Caliper the pad's mounting groove depth |
| Bow end-tab hole Ø + pitch | `bow_endtab_hole_*`, slider mount-bore pattern | Caliper hole Ø + centre-to-centre |
| Bow thickness + width confirm | `bow_thickness`, `bow_width` (33 mm looked wide — confirm flat-strap width) | Caliper the flat strap, not across a curve |
| Bow **worn** radius (on a head) | `bow_worn_radius` → ear spacing fine-tune | Pose on a head/form; note arc ≥180° for clamp |
| Baffle screw head height | insert/counterbore depth floor | Caliper the M3 head |
| Damping material + mass | acoustic tuning (later) | Scale + notes |

## What's currently a guess (so you know what you're de-risking)

From the DESIGN-LOG, these ship as `ESTIMATE`/`TBD` today and want Tier-1/2 numbers:
`cup_outer_diameter=90` (Tier 1, pad), the whole bow block (Tier 1/2),
`driver_od=42` (Tier 1), `pad_lip_extension=5`/`thickness=2` (Tier 2, reaches Ø100
so likely shrinks once the real groove is measured), `bow_worn_radius=78` (Tier 2).

## Capture standard (so a number is never ambiguous later)

- **Scale reference in every photo** — a steel ruler, or a printed Ø25 mm
  calibration disk you keep on the bench. Caliper readings beat photos; photos
  catch what you forgot to measure.
- **Record the number AND its confidence** in the brief / params comment:
  `MEASURED` / `ESTIMATE` / `TBD`. Never invent a number to make geometry "work".
- After measuring: set the param → `build.py` (N/N) → `gate.py` (0 HARD) →
  DESIGN-LOG entry → commit → push. The ESTIMATE is overwritten cleanly.

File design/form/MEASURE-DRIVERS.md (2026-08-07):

# Driver measurements — what to take, and what each number decides

The cup section (`section.py`) currently runs on **two assumptions and one design choice**.
These are the numbers that turn it from plausible into correct. Edit the `DRV_*` block at the
top of `section.py` and re-run.

Current state: `taper_mid`, flush joint, **split at 12.0**, driver flange 3.5 mm back from the
cup face → **7.0 mm front cavity, 3.5 mm behind the driver.**

## The 40 mm dynamic — replacing assumptions

| Measure | Now | Why it matters |
|---|---|---|
| **Dome proud of the flange** | 1.5 **ASSUMED** | Sets how far forward the driver intrudes. Directly trades against front cavity. |
| **One-way excursion** | 0.5 **ASSUMED** | Clearance the dome needs to move into. Under-guess this and the diaphragm hits something. |
| Frame OD | 39.5 measured | Confirm. Sets the seat. |
| Basket depth behind the flange | 5.0 measured | Confirm. Sets the split. |
| Flange thickness | — | The seat ledge it lands on. |
| Magnet OD | 27.0 | Rear clearance to damping / the rear cup. |

**And one nobody remembers until it bites: the solder tabs.** Measure how far the terminals
protrude behind the magnet and where they sit. With only **3.5 mm behind the driver**, the tabs
— not the basket — may well be the binding constraint on where the split goes. If they stick
out 2 mm the tail is effectively 1.5.

## The planar — everything is unknown

Nothing here is measured; the section currently guesses 9 mm body + 3 mm nipple, which pushes
the split to ~17 mm and **breaks the 12 mm front piece.** Worth knowing before you talk to
Pablo, because it is also the spec you would be asking him about.

- overall OD, and flange OD
- **body depth** behind the mounting face
- **front protrusion** — the nipple: height *and* diameter
- mounting hole pattern (PCD + hole count + size) — this is the "different mounting ring"
- terminal position and protrusion

## If the rig is out anyway

Fs, impedance, sensitivity per candidate. The brief calls choosing the driver *"the gate on
everything else"* and measuring candidates *"the highest-leverage day in the project"* — and
the `.mdat` files in the archive turned out to be imported datasheet traces, not captures, so
that day has not actually happened yet.

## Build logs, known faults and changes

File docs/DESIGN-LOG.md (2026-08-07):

# First Chair — Design Log

For an open design, the log *is* part of the product. Every decision, every
measurement, every iteration goes here so anyone can follow the reasoning, not
just the result. Newest entries at the top.

This log starts at the fork. Daily Driver's log stayed with Daily Driver — it is
that product's history, not this one's.

---

## 2026-08-07 — First form decision that actually landed: `taper_mid`

After six Claude Design passes produced nothing worth building, form exploration moved
in-house — `design/form/profiles.py` builds each direction as a real CadQuery solid from a
list of `(radius, depth)` points and renders a contact sheet. Six silhouettes, then the split,
then the section. **Three iterations, one afternoon, no handoff.**

**Decided: `taper_mid`, flush joint, split at 12.0.** Straight front wall from the lip to the
split, then tapering to a Ø29 back face. 24.0 deep, ~9.1 g of PETG.

The route there is worth keeping, because each step was the maker correcting a real error:

1. **Six silhouettes.** Liked `shallow` and `waist`.
2. **The split.** Maker's read: the profile is the *front* piece, baffle integrated, driver
   loading from the rear, and something closes the back. Asked whether the waist could even
   be split — and it inverts: **a waist is the best place to put a parting line**, because a
   seam at the narrowest point reads as intent. Also found that integrating the baffle into
   the front piece **registers the driver concentric to the pad by geometry** rather than by
   assembly, and makes the rear cup — where the acoustics live — the part you iterate.
3. **"It looks like a yoyo."** Correct: that profile swelled, pinched, then flared back out.
   Wide-narrow-wide. The fix was *"the base of the one on the left with the back of the other
   one flipped"* — straight front, mass falling away from the head.
4. **The section.** The 12 mm question could not be answered in the abstract, so it got drawn.

### What the section settled

```
ear ──5.5── cup face ──3.5── flange ──5.0── driver back ──3.5── split
            (worn pad)       (dome + excursion 2.0 forward)
```

**Front cavity 7.0 mm**, and it is mostly the pad — flats to bowls moves it several mm, which
is *why* the pad swap is the tuning lever rather than something we design around. The flange
at 3.5 back is a choice, not a constraint: pushing it back trades front cavity for tail room 1:1.

### Two things deferred honestly

**The parting line** is flush for now. A **shadow gap** (rear cup stepping down 0.6–1.2 mm for
~2 mm above the joint) was drawn and remains available — a pure diameter step, so zero overhang
on either part, and it hides tolerance mismatch that a flush joint displays. A chamfer was
considered and rejected: on whichever part faces it down it is a first-layer overhang.

**The joint** is unresolved. A quarter-turn bayonet is probably sufficient — retention is the
lug ramp and detent, not the rotation angle, and three lugs share load three ways. If it wants
more travel, a **3-start coarse thread** gives ~120° and still lands in one of three defined
positions, which is the real objection to a single-start thread: it stops wherever friction says,
so anything directional on the rear cup lands at a random angle.

### Paused on measurements

The section runs on two assumptions — dome proud 1.5, excursion 0.5 — and the planar numbers are
invented outright. `design/form/MEASURE-DRIVERS.md` lists what to take and what each number
decides, including the one that usually bites: **solder tab protrusion.** With 3.5 mm behind the
driver, the terminals rather than the basket may be what sets the split.

## 2026-08-07 — Stop prescribing. A brief that asks for a design instead of an execution.

Maker, after four form passes came back as rearrangements of the product we already have:

> *"Let's give Claude Design more leeway with its design decisions. Let's not prescribe as
> much, give it the general gist and maybe a list of basic parts... don't provide the already
> designed parts, give it a chance to design something really cool and appropriate."*

Correct, and the diagnosis is embarrassing in hindsight. **Every pass produced a Daily Driver
derivative because I specified one.** I handed over a parts list, a mechanism, exact dimensions
and a naming contract, then expressed surprise at getting back a rearrangement. The briefs got
*more* prescriptive with each failure — the opposite of the right correction.

### The brief now separates three things it had been conflating

- **Fixed** — and only what is genuinely set from *outside* the design: the 40 mm driver, the
  commodity Grado pad interface, FDM constraints, no printed springs, M3-only, real head
  anthropometry. Each with its reason, so it can be argued with.
- **Free — explicitly listed.** The part breakdown, depth, wall, rear treatment, how it attaches
  to the head, whether height adjustment exists at all, how many rotation axes and how. I had
  prescribed every one of these; the brief now names them as *not* prescribed, which is stronger
  than silence.
- **Functions, not parts.** Seven things it must do. There does not have to be a cup and a baffle
  and a clamp ring — that is just what I did last time.

### The handoff question, answered properly

Maker asked the right question: can we give leeway *and* still get something we can manufacture
from? Yes — because **the handoff requirements are about form of expression, not design content.**

The thing I re-author from is not the mesh. It is the **source**, which I can read directly, and
which the last pass already produced in an ideal shape without being asked: `CUP_PROFILES` as
lists of `[radius, depth]` points. That is *directly* re-authorable as a CadQuery revolve — no
tracing, no measuring tessellation, no loss, and no provenance question since it is our own
design from our own tool.

So five requirements, none of which constrain the design: 1 unit = 1 mm · every number in one
constants block · shapes from explicit profile arrays rather than hardcoded primitives · one
named node per part · the parts list and rules stated in words.

**What we give up is the `SUBASSEMBLIES` naming contract**, so ingest needs a one-time manual
mapping after a direction is picked. Since the CAD is hand-authored anyway, that is cheap.

### And the dead mechanism is finally gone from the tree

Not just commented — deleted. `parts/slider.py`, `parts/slider_shoe.py`,
`parts/headband_clamp.py`, and 41 parameters (`slider_*`, `thumbscrew_*`). What replaced them in
`params.py` is a marker saying there is no mechanism and naming the open question, because the
alternative kept regenerating: a design pass read those parameters — *from the file I had
declared authoritative* — and faithfully redrew the thumbscrew.

The yoke keeps its post; the post is part of the yoke. What is undesigned is the thing that
*receives* it. The worn-pose solve still needs to place the band somewhere, so two POSE-ONLY
references carry the numbers the clamp collar used to imply, clearly marked as describing a
drawing rather than a part.

**Build 13/13. Gate 0 HARD / 0 SOFT.**

*(A first attempt at this deleted `yoke_post_*` too and cascaded into `assembly.py`'s worn-pose
kinematics — where "fixing" it would have silently chosen one of the open questions. Reverted
and redone with a smaller blast radius. Worth recording: the cascade is a symptom of the fork,
not of the cleanup.)*

## 2026-08-07 — One thread, one insert. And Daily Driver isn't what we say it is.

Two decisions, and the second is bigger than the first.

### Fastener target: M3 inserts, M3 cap screws, M3 washers. Nothing else.

I proposed dropping heat-set inserts for captured hex nuts, borrowed from Variable Openmod.
**Maker pushed back and was right.** An insert is a small cylindrical bore; a captured nut needs
a hex pocket, capture geometry, an access slot, and clear space *behind* the joint — and our
baffle bosses are columns standing in the void with the bore facing forward, so there is no
behind. Inserts also give a reusable metal thread, which the standing tie-breaker
(serviceability — the user is a tweaker) wants over a nut that can drop out on the fourth
teardown. *"I feel like the heat inserts will allow us to design something more elegant."*

The real problem was never inserts, it was **variety**: five thread standards mixing metric and
imperial (M3, M5, 8-32, Ø4 and Ø6 shoulder screws), three insert sizes, three install bores.

**And almost all of it is one un-propagated decision.** The 8-32 insert, the 8-32 thumbscrew,
the pressure shoe, the M5 insert and the Ø6×M5 adjustment post are every one of them part of
the thumbscrew height-lock — the Daily Driver mechanism §4b already deletes. Propagate that and
the BOM collapses to M3 on its own. **Fifth instance of the session's one recurring failure:** a
decision made and never carried through. After the Ø91 radii, the DT 770 pads, the over-ear
form brief and the closed-back variant, this is starting to look less like a series of
oversights and more like the fork's default state.

One outlier survives, and the brief already convicted it: the Ø4×M3 pivot shoulder screw sits
below the official ISO 7379 size sheet, so suppliers brand it *"similar to"* — one of the
original complaints against Daily Driver's BOM. If a plain M3 cap screw and a printed bushing
can carry the tilt pivot, the build is M3 and nothing else.

Recorded in `params.py`, not executed: the deletion is tangled with the slider, and whether the
slider survives is an open question for the form pass.

### Daily Driver gets redesigned, and the reason is an identity problem

> **REVERSED same day.** Maker: *"Let's leave Daily Driver where it was."* The critique below
> stands and is worth keeping — it is why First Chair exists — but Daily Driver is not being
> rebuilt now. It stays paused where it is. The fork direction does **not** invert; First Chair
> is simply its own product.

Maker: *"I think we need to redesign the daily driver anyway... That's too complicated for a 3D
printed headphone, **it's not really what we say it is, it's more like a buy a bunch of parts
and print a few** headphone, so I want to redesign it."*

This is a sharper critique than the one in the brief, and a different one. The brief said Daily
Driver's hardware was a **barrier** — *"a wall for the person the manual is trying to reach."*
This says it is a **category error**: the product does not match its own description.

The count supports it. First Chair inherited that architecture: **~17 printed pieces against
60+ bought items across eight-plus suppliers.** Armored Soul's listing can state *"the only
parts not 3D printed are the screws/nuts, electronics and the earpads"* and have it be true.
Ours cannot finish that sentence in under a paragraph.

So it becomes a testable design rule, now in the brief:

> **"The only parts not 3D printed are ___."** If that can't be finished in a short breath, the
> design is wrong — not merely hard. Target answer: screws, drivers, earpads, cable, and one
> spring steel bow.

**Consequence for the family: the fork direction inverts.** First Chair was forked *from* Daily
Driver. A redesigned Daily Driver gets rebuilt *from* First Chair — which is what
`starting-a-new-product.md` already says, and which makes the shared-kit family model load-
bearing rather than aspirational. The kit gets designed once, here, and the over-ear inherits it.

Daily Driver remains paused, not abandoned. It comes back rebuilt rather than resequenced.

## 2026-08-07 — The closed-back variant is deleted, not deferred

The gate had been red on every push since the cup rebuild, on one check:
`closed-back-ports-clear`. I demoted it to SOFT first — a gate that fails constantly
teaches you to ignore it, and the next real unprintable part would have arrived looking
identical. Then the maker took the obvious next step: *"sounds like something we should
do?"* Yes.

**Deleted rather than fixed, for two reasons that stack:**

1. **It does not fit at 54 mm, and that was a real finding.** The ports live in the
   back-band floor between the damping ring and the baffle bosses. Rebuilt at 54 the
   bosses sit at r20.5 — hard against the wall, as far out as they can go — so the floor
   inside them ends at r17.0 while the ring already reaches r16.5. No Ø6 port fits a
   0.5 mm annulus, and shrinking the felt until one does gives a token Ø19 disc over a
   Ø38 grille zone.
2. **The line now has a closed-back product.** Session is the over-ear closed monitoring
   build. First Chair carrying its own closed-back conversion is a second answer to a
   question another product already owns — and it only ever had one because it inherited
   Daily Driver's "Studio clone" scope through the fork.

This is the maker's own **rule 1** applied to our own work: *if a mechanism isn't needed,
delete it — "an extra weakness we do not need."* Not deferred, not toggled off. Gone.

**What went:** `cup_open_back`, `cup_port_count`, `cup_port_diameter`, the derived
`cup_port_circle_diameter`, `vent_plug_clearance`, `vent_plug_flange`, `parts/vent_plug.py`,
the branch in `cup.py`, the gate check, the BOM row, the `build.py` classification and
ACOUSTICS line, and the website's tuning-plug card. Recoverable from git history if
Session ever wants the pattern.

**Build 16/16** (was 17 — vent_plug is gone). **Gate 0 HARD / 0 SOFT — clean for the
first time since the fork.**

Worth noting what this closes: the one finding I deliberately left failing at the start of
the session is now resolved the way the brief said it should be — as a design decision,
by the maker, not as a number I tuned to make a check go green.

## 2026-08-07 — Form before parts. We had the process backwards.

Maker, after two form passes came back clunky: *"we need to not take a primitive assembly
approach for our first pass, we need to take a more organic free flowing pass for the first
design, then we can break them up structurally and refine the details. It seems like we're
going about this backwards."*

Right, and it is the most consequential correction of the whole exercise — bigger than any of
the geometry ones, because it explains why the last two passes failed rather than fixing one
instance of the failure.

### What we were doing

Asking for **parts** in the first form pass. So `model.js` builds the cup as stepped cylinders,
boss cylinders stuck on the flank, box webs, 0.6 mm bevels — every junction an abutment between
two primitives. Nothing flows into anything. That reads as clunky regardless of proportion, and
"make it more elegant" cannot fix it, because the **construction method** is the defect.

That is the *engineering* order — parts, then assembly — imported into the *form* phase.

### The order, corrected

```
1. one continuous form, no parts at all      ← judge it as an OBJECT
2. split that form into parts                ← serviceability + printability enter here
3. details: grille, mark, fasteners, joints
4. ENGINEER — re-author by hand in CadQuery
```

### Two reasons this is right and not just a preference

**The maker's own prior product was done this way.** The archive folder is named
`Old Faithful Surfacing Rev 1` — the industrial-design firm delivered *surfacing*, one form, as
IGES and STEP. The part split came afterwards and came from the maker, in the design letter:
*"we can't make the whole cup out of wood. We decided split the part in two, imagining that we
would machine a frame out of aluminum, then attach wood cups."* Form first, split second. His
six shape sketches are outlines — no joints, no parts, no bosses.

**And it plays to the tool instead of against it.** Claude Design has no booleans and no fillet
operator. It therefore *cannot* cut features into a body, which is why it abuts primitives —
that is the only way it can imply parts, and it is its weakest mode. Lofts, revolves and sweeps
are its strongest. **We had been asking it for the one thing it is worst at, then complaining
the result looked assembled.**

There is a second payoff, and it is what makes the whole pipeline viable: **if the form is
defined as a profile, splitting it into parts at step 2 is a split of the profile — not a
boolean.** The path stays inside the tool's ceiling instead of hitting it one step later.

Recorded in `design-pipeline.md` §1 as standing process for every build, not just this one.
`design/form/FOLLOWUP-form-first.md` is the pass.

---

## 2026-08-06 — The house design language already existed. It was in a 2016 archive.

The maker opened up a 179 MB archive of prior professional headphone work: the **HeadRoom
Cosmic** (planar magnetic, Kickstarter-era, measured by InnerFidelity) and **Old Faithful**
(closed-back, industrial design by Deep Blue Design and Martin Ortiz). Prototypes 1–3, cut
spring-steel headband blanks, driver measurements, and the correspondence.

Three documents in it are worth more than everything I have written for this build.

### 1. The intent, in the maker's own words, 2016

From the design letter to the industrial designer:

> "The code name Old Faithful is chosen to represent something that lasts a lifetime and will
> be passed down for generations. It should exude quality craftsmanship, **almost looking
> handmade but with extreme precision**. Parts should be easily replaceable and durable.
> Reduce weight where ever possible."

Compare what I had been feeding Claude Design: *"honest engineering, pro-audio sensibility
through a maker lens."* Mine describes a category. His states an intent with a time horizon,
and "almost handmade but with extreme precision" is *actionable* — it tells a designer what to
do with a tolerance, a parting line, a visible fastener. Note also "parts should be easily
replaceable and durable": First Chair's serviceability tie-breaker, written a decade earlier.

### 2. The taste rulebook, and it has not moved in ten years

The Rev 2 feedback to that designer is eight corrections, and they are one position:

- kill the fold hinge — *"an extra weakness we do not need"* (not "unnecessary" — a **weakness**)
- kill the decorative step at the pad transition — *"I am assuming this is for aesthetic
  reasons? I do not have to have this"*
- **"There seems to be too much going on with the headband mechanism right now. We'd like to
  simplify."**
- and, crucially, the other half: *"we're looking to simplify without looking ugly. Hopefully
  we can find a nice middle ground."*
- on the yoke: *"if we don't need the extra metal, we can save weight — but it does look nice
  and beefy"*
- hinge pins moved 8 mm because a built prototype said so, not a drawing

The third one is verbatim the note the maker gave about Claude Design's slider today. **A
decade-stable taste position that I had been paraphrasing instead of quoting.**

### 3. Placement repeatability — the Cosmic's own numbers

Tyll Hertsens' raw workbook (512-point sweep, five placement positions in columns 1–10) run
through the same placement-SD metric the brief uses:

| Cosmic P3 | 20–200 Hz | 200 Hz–2 k | 2–8 kHz | 8–20 kHz |
|---|---|---|---|---|
| L / R | 0.10 / 0.34 | 0.29 / 0.41 | **0.77 / 0.48** | **2.02 / 1.84** |

More repeatable than any of SR60x, HD 650 or RS1x in the brief's table — with a *large* pad on
a circumaural, which is the opposite of what "prefer the smaller pad" predicts. **Not a valid
head-to-head**: different rig, different operator, ten years apart, and the brief's own rule is
that placement SD compares only within a session. A planar's large flat radiator also behaves
differently from a 40 mm dynamic. Recorded as a reason to re-examine the small-pad input, not
to overturn it.

Also worth knowing: InnerFidelity published that five-position overlay on *every* measurement
it ever made. §3's "as far as we know nobody publishes it as a design goal" survives as
written, but there is a public corpus of hundreds of headphones measured this way on one
consistent rig — a benchmarking asset the brief did not know it had.

### 4. The bow blanks change what "ruled out" means

§4b records that forming our own bow is ruled out by experiment. The photos show what actually
failed: the **cutting is excellent** — tapered strip, Y-fork at the ear end, teardrop-terminated
slots so the cuts cannot start cracks, holes at the tips. It was the *bend and the temper* that
failed, with printed jigs.

So the blanket "ruled out" overstates it. §4b already names "a stocked custom part made to our
spec" as the better long-term answer — **that spec is already drawn**, in blue-tempered steel,
on the bench. It is a sourcing conversation with a spring house, not a design problem. And the
cut language (fork, taper, teardrop slot ends) is material-follows-load executed in steel years
before I wrote the same principle into the yoke prompt.

### 5. The shape decision — see industrial-design-brief.md

Every built product in the archive is oval or teardrop; `Earcup - 07Rev B.STL` measures
100 × 80 × 21.6. First Chair's CAD is a perfect circle **by inheritance, not by decision**.

Maker's resolution, and it is better than the round-or-oval question I asked: *"We don't have
to be so rigid in our approach, we want to design with intent for the right application."* The
rule is the ear coverage, not the outline — circumaural follows the pinna (teardrop), supra-
aural does not enclose it (round). First Chair stays round, now decided, and overdetermined by
the locked round commodity pad. Full entry in the brief.

Also corrected there: round is easier to **turn and mould**, not to **print**. FDM does not care
about circle vs ellipse and there is no rotational tooling in the process — so the original
"round is easier to manufacture" was a constraint inherited from a process we do not use.

### What was deliberately not read

`Dai-Ichi - HeadRoom NDA`, the Menlo NDA, and `Proposed Joint Venture Menlo and Jamey` — all
commercial rather than design, and nothing from NDA'd supplier material can go near an
MIT-licensed public repo. The Deep Blue and Martin Ortiz work was also commissioned from third
parties; ownership is probably the maker's, but that is the same provenance question §5 raised
about the forum Grado CAD and it wants confirming before any of it becomes public reference.

### Not chased

Maker: more design files may exist on an old PC, *"but I think they're on an old PC and maybe
not worth digging up anyway, we need to move forward with our own design based on our current
constraints and capabilities."* Archaeology closed.

`design/form/PROMPT-04-design-language.md` carries all of this to Claude Design — the intent
quoted rather than paraphrased, the five rules as rules, the outline rule, and an attach list
pointing at the archive images.

---

## 2026-08-06 — The form brief was never rewritten, so the CAD built a shrunken DT880

Maker, looking at the published 3D viewer: *"that's not correct — this was supposed to be much
more of a Grado type headphone. I think we do actually need to resort to Claude Design and do
some of the design work before the actual build, looks like we got ahead of ourselves."*

Correct, and the cause is one file.

`docs/industrial-design-brief.md` — **the document the geometry is supposed to descend from** —
was Daily Driver's brief with the product name changed. It said, in v0.1:

> An open-back, **over-ear (circumaural)** DIY headphone … the chosen direction is
> **DT880-family, around-ear** … the target pad is the **Dekoni Universal 100 mm**.

The fork reset about eight dimensions in `params.py` and left that untouched. So the CAD did
exactly what it was told: it built a DT880 at 54 mm. Domed cup, circumaural stance, over-ear
pads on a Ø54 rim. **Dimensionally correct, formally the wrong product.**

This is the third and worst instance of the session's one recurring failure — inherited content
renamed rather than rebuilt. The Ø91 radii in `params.py` were the same bug in numbers; the
DT 770 pads in `BOM.md` the same bug in sourcing; this is the same bug in *intent*, and it sits
upstream of both. Everything downstream was faithfully derived from it, which is exactly why
nothing caught it: the gate checks printability, not whether we are building the right object.

**And the rule that would have caught it was written today, in this repo, a few hours earlier.**
`starting-a-new-product.md` step 1b: run the form pass in Claude Design *before* writing
`params.py`. This build predates the rule it needs. The process document is right; it just
arrived after the fork it was describing.

### What changed

- **`industrial-design-brief.md` rewritten at v0.2** as a supra-aural, with its false
  "direction resolved — DT880-family" claim removed and **the form re-opened**. It now states
  constraints and deliberately does not state the answer.
- **`design/form/SEED.md` added** — the operational seed to hand Claude Design: the naming
  contract, the four conventions, the locked dimensions, the honest description of what is
  wrong with the current model, and the Grado boundary. Committed, because the reproducible
  unit is `(skill + seed + prompt)` and a seed kept in a chat window is not a record.
- **Earpad mockup rescaled** from Ø100 × 24 (DT 770 class) to Ø60 × 9 — a supra-aural flat.
  The Ø60 has backing: the concept-mesh read put a Grado-pattern pad there and the maker's own
  note was "60 mm OD is right", and the brief puts flats at 8–10 mm thick. **The Ø38 opening is
  mine and wants a caliper**, and it drives `front_cavity_volume_cc`, which moves 67.9 → 10.2 cc.
  Treat that figure as soft. The pad is a visualisation mockup, not a spec — we neither design
  nor ship one.
- **Both website pages now say the form is wrong**, in those words, rather than implying the
  model is merely unfinished. The maker's call was to leave them up: a beta channel showing
  work in progress is the point, and it is how this got caught.

### The direction, settled by the maker

**Supra-aural architecture is the constraint; the form language is the open question.** Grado
is the right *architectural* reference — small cup, rod-in-block gimbal, minimal band, flat rear
face, everything visible — and the wrong styling target. `design-spec.md` §5's diverge-on-purpose
table stands. The pass produces 3–5 directions rather than my writing an answer into the brief.

**Not decided here, on purpose:** cup profile (the inherited dome is up for replacement), how
the grille reads at this size, the gimbal (ours is a fork-yoke from an over-ear; Grado's
rod-in-block gets a rotational axis for free), and the worn stance.

### Blocked on

The `claude-design` MCP needs `/design consent`, which needs an interactive session — so the
project could not be seeded from here. `SEED.md` is the handoff instead. Note the MCP has no
verb for the 3D agent in any case; seeding is the only thing it would have automated.

**No further geometry until the form pass lands.** Building more parts against a brief we know
is wrong just makes more to throw away.

---

## 2026-08-06 — Published to the manual, and the design pipeline moves to Claude Design

Two things, both about the build's *surfaces* rather than its geometry.

### Published as a build on makerphones.com

GitHub Pages enabled on this repo (main `/docs`, matching Daily Driver), so
`makerphones.github.io/first-chair/` now serves the beta channel — the assembly GLB,
the sub-assembly manifest, and the per-part renders, with
`access-control-allow-origin: *`, which is what lets the manual fetch them cross-origin.

Two pages on the website, same structure and same components as Daily Driver:
**First Chair — Design Spec** and **First Chair — Parts & Exploded View**. They lead the
Build Guides section, ahead of Daily Driver, which is the flagship ordering the brief
calls for. Daily Driver is untouched — resequenced, not abandoned.

`PartsGallery.astro` had Daily Driver's parts table hardcoded inside it. That table now
lives in `src/data/build-parts.ts` alongside First Chair's, and the component takes a
`table` prop defaulting to Daily Driver, so the existing pages are unchanged.

**No CURRENT-build page yet, deliberately.** `promote.py` has not been run — the cup was
rebuilt hours ago and the gate is still red on one check. Promotion is the maker's call,
and both website pages carry a caution banner saying this is the live design.

**Found while writing the parts table:** `BOM.md` still lists **Beyerdynamic DT 770/880/990
earpads** as the default. That is a circumaural pad on a supra-aural headphone — `bom.py`
was not reconciled at the fork, same class of inherited content as the Ø91 radii. The
website pages are written from the locked brief (commodity **Grado-pattern** pads, which we
neither design nor ship), so **the site and the BOM currently disagree**. `bom.py` is the
one that is wrong.

### The design pipeline now runs through Claude Design

`docs/design-pipeline.md` rewritten at v0.3. It described the FAL image pipeline as current
— 16 mentions of FAL, zero of Claude Design — which was straightforwardly stale: the FAL
path was abandoned rather than finished, and the probe results that replaced it never made
it out of the pre-fork brief and into the build repos.

The capability map is **not** restated here; it lives in `warren-labs/docs/claude-design.md`
and applies line-wide. What this repo now carries is the MakerPhones-specific part: where it
sits in the process, what we hand it, and what we demand back.

**The taste-vs-convention boundary survives the change untouched**, and it is worth saying
why rather than just asserting it: **Claude Design produces taste, never convention.** It is
a form tool. It cannot author a screw boss you would reuse, and should never be asked to.
Taste → `params.py` (numbers) + `parts/*.py` (form); convention → `parts/features.py`.

**`pipeline/` deleted** — `config.py`, `gen_concepts.py`, `gen_reference_mesh.py`,
`smoke_test.py`, plus the `fal-client` dependency and the FAL-specific gitignore rules.

*The decision, recorded so it is not mistaken for neglect:* the case for keeping it as a
documented fallback is that dead code costs nothing to leave in place. It doesn't. An
abandoned two-stage path with working code, a config file and a smoke test reads as
**current** to the next person who opens the repo — and because this repo is the fork
template for every build after it, the trap regenerates itself with each fork. A paragraph
of history is cheaper than that. The code is in git history and in the Daily Driver repo.

**`starting-a-new-product.md` gains step 1b:** run the family/form pass in Claude Design
**before** writing `params.py`, seeded with the repo and the `SUBASSEMBLIES` naming schema.
The ordering is the whole point — before `params.py` exists there is no engineering to lose
to a tool that cannot do booleans, and the output is a named part list that reads straight
into one. Afterwards it can only get in the way.

**Four conventions, written down in all three places, because two of them fail silently:**

- **1 unit = 1 mm.** glTF's spec convention is *metres*, so an unspecified model imports at
  **1/1000** into a slicer. Nothing errors — you get a 0.054 mm cup.
- **GLB only, never OBJ.** OBJ has no scene graph, so it *structurally cannot* carry the
  `SUBASSEMBLIES` hierarchy that is the entire reason to use the tool.
- **Impose the mesh-naming schema.** It conforms exactly when asked; when it isn't, someone
  hand-maps every mesh.
- **The reproducible unit is `(skill + seed + prompt)`, not the prompt.** A project can be
  seeded from a design system, uploaded files, or a GitHub repo — all three go in the record
  beside the GLB, or the result cannot be reproduced later.

Run `makerphones/scripts/inspect_glb.py` on anything that arrives: it warns on **both**
scale-failure directions, which is the only cheap way to catch the two silent ones.

*Out of scope, flagged:* Daily Driver still carries the FAL pipeline and the v0.2 doc (it is
paused), and the manual's **Designing Headphones with AI** chapter still lists FAL as a tool
with no mention of Claude Design.

---

## 2026-08-06 — Rebuilding the cup at 54: what the fork inherited, and the one thing that did not survive

**Starting state:** 17/17 parts building, `gate.py` red on one HARD check —
`manifold:cup: 3 solid(s), valid=True (want 1, True)`.

**The reported hypothesis was the rear grille lattice.** It was not. The grille was
genuinely broken, but it was not what split the cup into three solids.

### The actual cause: `yoke_pivot_centres = 98.0`

That number is Daily Driver's Ø91.44 cup plus ~4 mm of boss stand-off per side, and
it came through the fork untouched. It drives `pivot_boss_outer_radius`, so the two
yoke pivot bosses were being built spanning **r40 → r49 on a cup whose body radius is
24.0**. They touched nothing. Dumping the solids says it plainly:

```
0: vol=  48813.1  x[ -33.52,  33.52]  z[ 0.00, 33.60]   <- the shell
1: vol=    942.5  x[  40.00,  49.00]  z[14.80, 26.80]   <- a pivot boss, floating
2: vol=    942.5  x[ -49.00, -40.00]  z[14.80, 26.80]   <- the other one
```

**The part worth remembering is how quietly it passed everything else.** `gate.py`
reported `[PASS] pivot-clearance: boss proud 22.0 mm >= 2.0 mm` — because a boss
attached to nothing is extremely proud of the wall. The check measured
`pivot_boss_outer_radius − cup_outer_diameter/2` and got a large positive number,
which is exactly what "healthy" looks like. **A check written at one scale can read as
confirmation at another.** It now measures against the body, which is the wall the
boss actually sits on.

### The audit, since one absolute surviving the fork means all of them did

Diffing the fork against Daily Driver: **eight values changed, everything else is still
a Ø91.44 number.** Auditing every radial dimension the cup touches against the new
scale (body r24.0, void r21.0):

| Parameter | Was | At 54 mm |
|---|---|---|
| `cup_back_face_radius` | 35.0 | **larger than the cup's own radius** — the "dome" lofted OUTWARD to Ø70 |
| `cup_dome_height` | 12.0 | ran 6 mm past the void floor and thinned the wall below 3.0 |
| grille zone edge | r33.0 | 9 mm outside the shell — cut in air |
| `grille_lattice_pitch` | 16.0 | ≈ the zone diameter; 3 bars, no mesh |
| `baffle_bolt_circle_diameter` | 70.0 (r35) | 11 mm outside the body — four columns in open air |
| `baffle_boss_diameter` / flare | 12.0 / 15.0 | a quarter of the cup's diameter |
| `yoke_pivot_centres` | 98.0 | **the manifold failure** |
| `damping_felt_diameter` | 38.0 | ring outer r20.5, straight into the rebuilt boss circle |
| `driver_clamp_bolt_circle` | 60.0 (r30) | off the Ø54 baffle entirely |
| `cup_port_circle_diameter` | 50.0 (r25) | outside the void |

**These are not nudged. They derive now**, so they cannot drift out of scale again.
The pattern in almost every case: the *rule* was already written in the parameter's own
comment, and the absolute was standing in for it. `driver_clamp_bolt_circle` literally
said "between vents (r26) + frame holes (r35)" — that sentence is the arithmetic, and it
is now the arithmetic. Same for the damping ring ("stays inside the baffle-boss circle"),
the dome height ("capped by the void wall"), and the grille zone.

One value deliberately did **not** scale: `grille_lattice_member_width = 2.2`. That one
is a legitimate absolute — it is a nozzle multiple (0.4 × 5.5), set by the printer, not
by the part. Worth naming the distinction explicitly, because "scale everything" is as
wrong as "scale nothing".

### Two more inherited-semantics bugs, same class as `cup_wall_thickness`

Both invisible for the same reason: the model never stated the number, so nothing checked it.

1. **`cup_total_height` returned `cup_depth + cup_back_thickness`.** Correct on Daily
   Driver, where `cup_depth` meant the *interior* depth. Here `cup_depth` is the overall
   front→back dimension off the reference profile and is **LOCKED at 27.6** — so the model
   was building a 33.6 mm cup against a 27.6 mm lock. Now returns `cup_depth`, with
   `cup_interior_depth` derived for the volume calc (which had been over-reporting the void
   by double-counting the back band).

2. **`cup.py` built the shell at `cup_outer_diameter` (54.0).** The Ø54 is the front
   **plate**; the shell is the Ø48 **body**. Building it at 54 gave a 6 mm wall while
   `cup_wall_thickness` correctly reported the real 3.0 — the exact failure already caught
   one level up in params, repeated one level down in geometry — and it deleted the step
   the pad hooks behind. The cup is now the Ø48 body with a Ø54 × 3.0 lip, which lands the
   overall depth on 27.6 for free.

   `parts/coupon.py` had the same read: the pad coupon was validating fit against a grip
   surface 6 mm too big, which is precisely the fit a coupon exists to catch.

### The grille, rebuilt rather than nudged

It now derives from `cup_interior_diameter`: the zone is the void less `grille_rim_land`
(2.0, at the member floor) — a landing ring of solid floor that carries the mesh into the
wall. The logo scales into that zone by the mark's own 64-grid proportions, held in one
place (`_LOGO_GRID`) so it can only be scaled, never re-typed.

**The mark cannot be reproduced proportionally at 54 mm.** Its inner ring stroke lands at
1.34 mm, below the 2.0 printability floor, so the floor wins and the ring is clamped. That
is a fact about the printer, and it is clamped in the derivation rather than quietly
re-typed as an absolute.

**Two bugs found while doing it, both created by splitting the logo from the zone** — a
distinction that did not exist before, because the mark used to fill the zone exactly:

- `gate.py` measured open area over `grille_outer_ring_radius + width/2`, i.e. the *logo's*
  edge. Once the mark shrank inside the zone that silently excluded the lattice-only
  annulus outside it — about 44 % of the zone, and the most open part.
- `cup.py` cut its zone from the same expression, so it punched a hole the size of the
  **logo** and left everything out to the wall solid: a 6 mm back plate with a badge in it,
  measuring **0.075 open**. Caught on the render, not the number.

**`grille_logo_zone_fraction` is a new taste knob and it is a real trade — maker's eye
wanted.** At 1.0 (Daily Driver's implicit value) the mark closes ~47 % of the zone unaided;
the lattice pitch then has to open past the zone radius to stay in the open-area band,
which leaves 3 bars per angle — only the through-centre bars survive and the "triangular
lattice" degenerates into a **6-spoke wheel**. That puts the logo back to being the
structure, which is the arrangement the Stage 1b rework specifically inverted. Set to
**0.60**, which buys 5 bars per angle and lands open area at **0.388** against a 0.40
target. Cost: the mark is Ø22.8 on a Ø38 grille rather than filling it. **0.75 with pitch
0.66 also passes** (open 0.436) if the bolder mark is worth the spoke wheel — that is a
look-at-it decision, not a numbers one.

### Left failing on purpose: the closed-back variant

`gate.py` is down from the reported failure to **one HARD failure**, and it is a true
statement about an **inactive** variant (`cup_open_back` defaults True, so the built part
is unaffected):

```
[FAIL] closed-back-ports-clear: ports r17–23 between damping ring r16 and baffle bosses r17
```

The tuning ports live in the back-band floor, between the damping ring and the baffle
bosses. Rebuilt at 54 the bosses sit at r20.5 — hard against the wall, which is as far out
as they can go — so the floor inside them ends at r17.0, and the damping ring already
reaches r16.5. That is a 0.5 mm annulus and no Ø6 port fits in it. Shrinking the felt until
one does drives it to ~Ø19 over a Ø38 grille zone, which is a token disc, not damping.

**So this is a design decision, not a value, and it is not mine to make.** Three ways out:

1. **Drop the closed-back variant from First Chair.** The brief specifies an open-back
   on-ear throughout; this toggle is inherited Daily Driver "Studio clone" scope.
2. **Interleave the ports angularly** between the four bosses (ports at 0/90/180/270 vs
   bosses at 45/135/225/315). The ports pierce z0–6 and the bosses stand from z6 up, so
   they only actually conflict where they share an angle — which means the gate's purely
   *radial* band check is testing for the wrong thing, and only ever passed on Daily Driver
   because that cup was big enough to satisfy the wrong test. Fixing the check is a real
   improvement; it is not one to make while trying to go green.
3. **Segment the damping ring** into arcs between the bosses and reclaim the floor.

### Form note for the next pass

Capping the dome inside the back band makes it **shallow** — 4.5 mm of bulge over 6 mm of
height reads closer to a 45° chamfer than a Denon bulge. The lever is the one Daily Driver
already identified: thicken the back band or reduce the cup ID. `cup_back_thickness` is
still 6.0, an inherited absolute that is 22 % of this cup's total depth; it is defensible
(it is the dome's home) but it has not been re-derived and it is the obvious next knob.

### Still on Ø91.44 numbers, not touched this pass

`baffle_outer_diameter = 77.0` — the plate should be the LOCKED Ø54. The baffle still
builds and passes, but it is a Ø77 disc in a Ø54 world, and its vent zones, guard and
clamp-standoff geometry all sit on Daily Driver radii. **The baffle is the next part to
rebuild**, and it should be done as one pass rather than piecemeal — moving its bolt
circle (done, it is shared with the cup) without moving its plate leaves the two parts
mutually consistent and both wrong against the lock.

Build **17/17**. Gate **1 HARD / 0 SOFT** — the closed-back variant above.

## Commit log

2026-08-06 First Chair: fork from Daily Driver, cup geometry reset
    The on-ear open-back. Forked per daily-driver/docs/starting-a-new-product.md:
    copy-on-write from the reference, fresh repo, logs and artifacts cleared.
    Cup taste params reset to the settled profile (BRIEF.md, moving in next):
    cup_outer_diameter 54.0 LOCKED -- the baffle plate, and the pad-mount rim
    cup_body_diameter 48.0 LOCKED -- what the pad grips, behind the lip
    cup_lip_depth 3.0 LOCKED
    cup_depth 27.6 SET
    wall (derived) 3.0
    The reading that made the profile make sense: the 'lip' is not a feature ON the
    cup, it is the BAFFLE PLATE OVERHANGING THE BODY. That explains the whole
    profile in o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
2026-08-06 First Chair: take the product identity off Daily Driver
    62 references renamed across code, docs and generated artifacts. The one that
    actually mattered: docs/models/daily-driver.glb is a PUBLIC CONTRACT with the
    manual's parts viewer (assembly.py says so), and a First Chair repo shipping a
    14 MB Daily Driver assembly under that name would have been wrong in the file
    name, the geometry and the 14 MB. Now first-chair.glb + first-chair.groups.json,
    rebuilt from this repo's own parts.
    Left pointing at Daily Driver on purpose: starting-a-new-product.md,
    new-build-intake.md, design-pipeline.md, cadquery-build-notes.md,
    filesystem-mcp-setup.md and drawings/README.md. Those describe the process and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
2026-08-06 First Chair: regenerate artifacts after the identity rename
    Renders, GLBs, drawings and the generated docs (BOM, PARTS, ACOUSTICS) rebuilt
    from this repo's own parts. These are tracked rather than ignored because
    GitHub Pages serves docs/models for the web parts viewer -- same as Daily Driver.
    Left over from the rename pass: the tree still carried geometry built before
    cup_outer_diameter dropped to 54.0, so the committed renders showed a 91 mm cup
    under First Chair's name.
2026-08-06 First Chair: driver_clamp artifacts
2026-08-06 First Chair: rebuild artifacts (and a note on determinism)
    FINDING, inherited from Daily Driver: the build is NOT deterministic. Rebuilding
    a single part with no source change produces a different GLB hash and leaves the
    tree dirty. Confirmed by rebuilding driver_clamp twice: 6842d2bc -> c5b8a61b.
    Consequence for a repo that COMMITS its artifacts: 'git status is clean' stops
    being a meaningful check after any build, and real changes cannot be told apart
    from build noise. Not fixed here -- it wants either deterministic export or
    moving artifacts out of git and generating them in CI, and both are decisions
    rather than patches.
2026-08-06 First Chair: the cup rebuilt at 54 — design log, and a provenance note
    Adds docs/DESIGN-LOG.md (this repo had none — Daily Driver's log stayed with
    Daily Driver) and corrects CLAUDE.md's inherited "yoke/slider are stubs" claim,
    which would have had someone re-solving finished work.
    PROVENANCE, because the history does not say so: the cup rebuild itself is
    already in dae0165, committed under the message "regenerate artifacts after the
    identity rename". That commit's body describes renders and GLBs only, but it
    also carries params.py (+298), parts/cup.py, gate.py and parts/coupon.py — the
    whole 54 mm rebuild, swept up mid-edit by a concurrent artifact-regeneration
    pass and pushed. Not r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
2026-08-06 First Chair: Claude Design replaces the FAL pipeline, as standing process
    docs/design-pipeline.md described the FAL image pipeline as current -- 16 mentions
    of FAL, zero of Claude Design. The probe results that superseded it never made it
    out of the pre-fork brief and into a build repo. Rewritten at v0.3, and written as
    standing process rather than First-Chair-specific, because this repo is the fork
    template for every build after it.
    The capability map is NOT restated here. It lives in warren-labs/docs/claude-design.md
    and applies line-wide; this repo carries the MakerPhones-specific part -- where it
    sits in the process, what we hand it, what we demand back.
    The taste-vs-convention boundar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
2026-08-06 First Chair: the form brief was never rewritten, so the CAD built a shrunken DT880
    Maker, looking at the published viewer: "that's not correct -- this was supposed to be
    much more of a Grado type headphone... looks like we got ahead of ourselves." Correct,
    and the cause is one file.
    docs/industrial-design-brief.md -- the document the geometry is supposed to descend
    from -- was Daily Driver's brief with the product name changed. v0.1 said "an
    open-back, OVER-EAR (circumaural) DIY headphone", recorded the resolved direction as
    "DT880-family, around-ear", and named a Dekoni Universal 100 mm pad. The fork reset
    about eight dimensions in params.py and left it untouched, so the CAD did exactly wh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
2026-08-07 First Chair: split the paste-in prompt out, and make it self-contained
    Maker: "I opened that file but it's got extra shit in it. Give me just the prompt.
    Also, is Claude Design able to see the file you've asked it to view? I don't think so."
    Right on both counts, and the second one was a real hole. Claude Design has NO
    filesystem access to this repo, so SEED.md telling it to "read the full brief in
    docs/industrial-design-brief.md" would have silently produced a session working from
    its own priors -- which is precisely the failure the form pass exists to fix. It would
    not have errored; it would just have designed the wrong thing again, for a new reason.
    - design/form/PROMPT.md -- the prompt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
2026-08-07 First Chair: pass 02 prompt — the yoke, as a family rule
    Maker's read on the two Claude Design passes: the family study is a good first pass
    and the four-direction single design is not, "other than the earcups maybe". So the
    next pass goes to the FAMILY project and the single design is parked -- refining
    detail on a wrong first pass wastes it.
    The yoke is the target, for the reason that makes it a family problem rather than a
    styling one: it is IDENTICAL across all four products, and the loads are not. A Ø54
    on-ear cup is a fraction of the mass of a Ø96 Encore cup on a shorter arm. Every other
    dimension in that study derives from something; the yoke is just repeated -- which is
    exactly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
2026-08-07 First Chair: pass 03 prompt — the whole upper assembly, and my prompt was the cause
    Maker: "there is more wrong here than just the yoke, the whole slider mechanism is
    not right, the headband is not what we need based on the one we've chosen, the
    attachment of the headband to the slider is completely not right."
    All three, and they share a cause I own: PROMPT.md gave Claude Design a PARTS LIST
    ("bought sprung steel bow -> printed slider -> printed yoke") and three DoF, and never
    described the MECHANISM. So it invented one -- and what it invented is, predictably,
    Daily Driver's: a knurled thumbscrew friction-locking a printed leg with a smooth
    travel slot, plus a clamp block gripping the st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
2026-08-07 First Chair: the house design language already existed, in a 2016 archive
    Maker opened a 179 MB archive of prior professional work -- the HeadRoom Cosmic
    (planar, Kickstarter-era, measured by InnerFidelity) and Old Faithful (closed-back,
    ID by Deep Blue Design and Martin Ortiz), plus prototypes 1-3, cut spring-steel bow
    blanks and driver measurements. Three documents in it are worth more than everything
    I have written for this build.
    INTENT, his words, 2016: "something that lasts a lifetime and will be passed down for
    generations... exude quality craftsmanship, almost looking handmade but with extreme
    precision. Parts should be easily replaceable and durable." I had been feeding Claude
    Desi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
2026-08-07 First Chair: one lineup brief, seeded from the repo instead of attachments
    Maker: "I don't want to have to attach anything, can you help me put together a repo
    we can link" -- and, separately, "7506 is not round."
    BOTH CORRECTIONS MATTER, and the second one breaks a conclusion I reached too fast.
    I had listed Grado round, Beyer round, 7506 round, M50x rounded-oval, and concluded
    "almost every commodity pattern is round, therefore round is what the pad principle
    implies." Two of the four are not round. The RULE survives -- the pad decides the
    outline -- but the conclusion does not: the aftermarket offers both, so choosing the
    pad IS choosing the outline, and that is a real per-product decisi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
    [earcup-07revB.stl]
2026-08-07 First Chair: seed the lineup form study — project created, brief written in
    Project: makerphones — lineup form study v2
    https://claude.ai/design/p/aac8535d-f9c9-4cbd-a518-687dcfcbf011
    BRIEF.md written into the project over MCP. The GitHub seed itself is a UI action --
    create_project takes a design system id and nothing else, and there is no MCP verb for
    the 3D agent either -- so the brief carries public raw.githubusercontent URLs as the
    fallback route to the reference images and params.py.
    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
2026-08-07 First Chair: form pass 2 follow-up — transitions, not primitives
    Maker: the refined First Chair is "still very clunky and not elegant at all", and
    "we need to get the family and form right first before we work on the small details".
    The clunkiness is diagnosable from model.js rather than a matter of taste: the cup is
    ASSEMBLED FROM PRIMITIVES. Stepped cylinders, boss cylinders stuck on the flank, box
    webs, 0.6 mm bevels. Every junction is a butt joint between two shapes and nothing
    flows into anything. The proportions are fine and the numbers are right -- 54/48/42,
    depth 27.6, bow R78/w33/pitch 26 all read correctly. It is the junctions.
    So the note is transitions, and it points at three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
2026-08-07 First Chair: form before parts — the process was backwards
    Maker: "we need to not take a primitive assembly approach for our first pass, we need
    to take a more organic free flowing pass for the first design, then we can break them
    up structurally and refine the details. It seems like we're going about this backwards."
    The most consequential correction of the exercise, because it explains why the last two
    passes failed rather than fixing one instance. We were asking for PARTS in the first
    form pass, so model.js builds stepped cylinders, boss cylinders stuck on the flank and
    box webs -- every junction an abutment. That reads as clunky regardless of proportion,
    and "make it more elegant" can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
2026-08-07 First Chair: one canonical BRIEF.md — surfaced, not assembled, not a blob
    Maker, on my "one continuous form, no parts" instruction: "I don't want a continuous
    rim and body. that's not what Deep Blue provided, they were able to show pads and all
    that, I don't want to see a blob."
    Right, and I over-corrected. The Cosmic render has a visible pad, a wood face, an
    aluminium ring, a leather band, distinct materials -- it reads as a photographable
    product. It is not engineered: no bosses, no fasteners, no part-split lines, because
    those had not been designed yet. So the distinction is SURFACED, NOT ASSEMBLED --
    not "one body".
    Corrected in the brief as three instructions rather than one prohibi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
2026-08-07 First Chair: BRIEF.md — resolved ID, not "no part lines"
    Maker showed the eight Deep Blue first-pass renders: "I'd like to see something like
    this, not a blob or a bunch of squareish chunky things."
    Which corrects my instruction twice over. Those renders ARE assembled parts -- bezel,
    face panel, yoke blade, band, sliders, pad, all distinct, all in different materials.
    "Surfaced, not assembled" and "no part lines" were both wrong. The real distinction is
    RESOLVED INDUSTRIAL DESIGN vs ENGINEERED ASSEMBLY: parts are parts and read as parts,
    but there are no fasteners, no screw bosses, no grille lattice, no print-split lines,
    because none of that had been designed when those renders were made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
2026-08-07 First Chair: delete the closed-back variant
    Maker, on the note that Session already owns closed-back: "sounds like something we
    should do? Go ahead and make the change if you recommend it."
    Deleted rather than deferred, for two reasons that stack:
    1. It does not fit at 54 mm, and that was a real finding rather than a tuning problem.
    The ports live in the back-band floor between the damping ring and the baffle
    bosses. Rebuilt at 54 the bosses sit at r20.5 -- hard against the wall, as far out
    as they can go -- so the floor inside them ends at r17.0 while the ring already
    reaches r16.5. No Ø6 port fits a 0.5 mm annulus, and shrinking the felt until one
    does gives a token Ø19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
2026-08-07 First Chair: BOM pads are Grado-pattern, not DT 770
    bom.py still specified "Beyerdynamic DT 770/880/990, OD ~100 / opening ~58 / depth
    22-25 mm" -- a CIRCUMAURAL pad on a supra-aural headphone. Inherited from Daily Driver
    at the fork and never reconciled, so the generated BOM.md and the website page have
    been contradicting each other since the pages went up: the site was written from the
    locked brief (commodity Grado-pattern, which we neither design nor ship), the BOM from
    Daily Driver's leftovers.
    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
2026-08-07 First Chair: record the Variable Openmod prior-art boundary
    Maker found Armored Soul's Variable Openmod series (three published printable
    headphones) and asked whether we could shorten development by borrowing ideas. Worth
    it -- but the licence decides the shape of that, so it goes in writing before anything
    reaches a design decision.
    LICENCE: CC BY-NC-SA 4.0, confirmed on all three Printables listings. Two clauses are
    blockers, not cautions. ShareAlike is incompatible with MIT -- a BY-NC-SA derivative
    cannot be relicensed, so their geometry entering this repo would take the repo's
    licensing with it. NonCommercial forbids the book and kit path. Printables says as much
    on the page: "Meets Op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
2026-08-07 First Chair: new form brief — the print process IS the house language
    Maker: read the CAD to understand the architecture, document it, write the new brief.
    Corrected my own over-tightening first: copyright restricts reproduction and derivative
    works, not looking. The repo's own Grado boundary already says reading to understand
    architecture is legitimate. The rule is about what comes OUT, not what goes in.
    ARCHITECTURE, measured from the published .3mf parts (bounding boxes only, no geometry
    taken):
    pad-mount 96 x 96 x 5.0 driver-size specific
    body 106 x 100 x 12.2 driver-size specific
    shell 100 x 100 x 18.0 SHARED across every 40-60mm driver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
2026-08-07 First Chair: fastener target recorded, and Daily Driver's identity problem
    FASTENER TARGET: M3 inserts, M3 cap screws, M3 washers. Nothing else.
    I proposed swapping heat-set inserts for captured hex nuts (borrowed from Variable
    Openmod). Maker pushed back and was right: an insert is a small cylindrical bore, while
    a captured nut needs a hex pocket, capture geometry, an access slot and clear space
    BEHIND the joint -- and our baffle bosses are columns standing in the void with the
    bore facing forward, so there is no behind. Inserts also give a reusable metal thread,
    which the serviceability tie-breaker wants over a nut that can drop out on the fourth
    teardown.
    The real problem was never inse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
2026-08-07 First Chair: delete the dead mechanism, and stop prescribing the design
    Two changes, and the second is the reason for the first.
    DEAD MECHANISM DELETED, not commented. parts/slider.py, parts/slider_shoe.py,
    parts/headband_clamp.py, and 41 parameters (slider_*, thumbscrew_*). All of it Daily
    Driver's post-and-thumbscrew height lock, inherited through the fork, and deleted by
    decision in August -- §4b: the detent ladder "deletes the thumbscrew, the insert and
    the pressure shoe in one move."
    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
2026-08-07 First Chair: cup profile study — form exploration in our own tool
    Six cup profiles built as real CadQuery solids and rendered from one camera, after six
    Claude Design passes failed to produce a form worth building — including a deliberately
    minimal prompt written by the maker himself. When a short prompt from someone with a
    decade of headphone design behind him also comes back generic, the instrument is the
    problem rather than the instructions.
    So: form exploration moves in-house. No handoff, no tool that cannot do booleans, and
    every output is a real part. `design/form/profiles.py` defines each direction as a list
    of (radius, depth) points -- the same shape Claude Design was producing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
    [bell.stl, cone.stl, cylinder.stl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]
2026-08-07 First Chair: split study — where the cup breaks, and why the waist is the answer
    Maker likes `shallow` and `waist`, and asked the real question: this profile is the
    front/head-facing part with the baffle possibly integrated, the driver loads through
    the rear, and something has to close the back. Screw-in cup, glue, or screws?
    Two findings.
    THE WAIST WORRY INVERTS. A waist is the best possible place to put a parting line — a
    seam at the narrowest point reads as intent, the same seam on a straight wall reads as a
    seam. So the waist does not prevent the split; it says where the split goes. Added
    `waist_split`, a TRUE waist (the rendered one only swells then tapers), pinching to
    Ø42.8 at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
    [split-shallow-front.stl, split-shallow-rear.stl, split-waist_split-front.stl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]
2026-08-07 First Chair: straight front + tapering back, and the parting line
    Maker on waist_split: "it looks like a yoyo." Correct, and not a render error -- that
    profile swells, pinches, then FLARES BACK OUT. Wide-narrow-wide is a yoyo. The read was
    "the base of the one on the left with the back of the other one but flipped": straight
    front, mass falling AWAY from the head rather than bulging back out.
    Three taper rates added (soft/mid/hard, 25.0/24.0/22.5 deep, 10.3/9.1/7.8 g). The
    straight section doubles as the split zone, which is the point: parting on a cylinder
    means both mating faces share a diameter, so the joint is a simple round fit instead of
    something that has to follow a curve.
    PARTING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
    [joint-flush-front.stl, joint-flush-rear.stl, joint-shadowgap06-front.stl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]
2026-08-07 First Chair: cup section — the 12 mm question, answered
    Maker picked the bottom-left (taper_mid + flush joint), and could not answer the "does
    12 mm hold a driver" question without seeing it — fair, it was a question about a stack
    nobody had drawn. So: draw it.
    design/form/section.py puts the driver, the pad and the ear plane into the profile in
    section. 2D on purpose -- a section reads a stack far better than a render.
    ANSWER: yes, comfortably, for a dynamic.
    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
2026-08-07 First Chair: taper_mid locked, paused for driver measurements
    DECIDED: taper_mid, flush joint, split at 12.0. Straight front wall from the lip to the
    split, tapering to a Ø29 back face. 24.0 deep, ~9.1 g PETG. The first form decision in
    this project that has actually landed.
    Route there, three iterations in one afternoon with no handoff, each step a maker
    correction: six silhouettes -> liked shallow and waist -> the split study, where the
    waist worry inverted (a waist is the BEST place for a parting line, since a seam at the
    narrowest point reads as intent) -> "it looks like a yoyo" (correct: swell, pinch, flare
    back out) -> straight front with mass falling away -> the section.
    Also estab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
